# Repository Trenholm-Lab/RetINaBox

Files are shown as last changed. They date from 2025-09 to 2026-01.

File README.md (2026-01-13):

# RetINaBox 

Welcome to RetINaBox, an interactive learning tool for experimental neuroscience. If you haven't read the paper yet, check it out at https://www.eneuro.org/content/13/1/ENEURO.0349-25.2025.

To get started, you'll want to build yourself a RetINaBox, install the software on a Raspberry Pi, and connect your RetINaBox to the Raspberry Pi. Everything you need to get going can be found here, from the 3D printing files, to the components list, to the software, to the user manual. Once you're all up and running, check out the lesson plans!

Enjoy, and best of luck!

cover art copy

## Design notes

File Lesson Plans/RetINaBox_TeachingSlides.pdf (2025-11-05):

# RetINaBox

# Lesson Plans

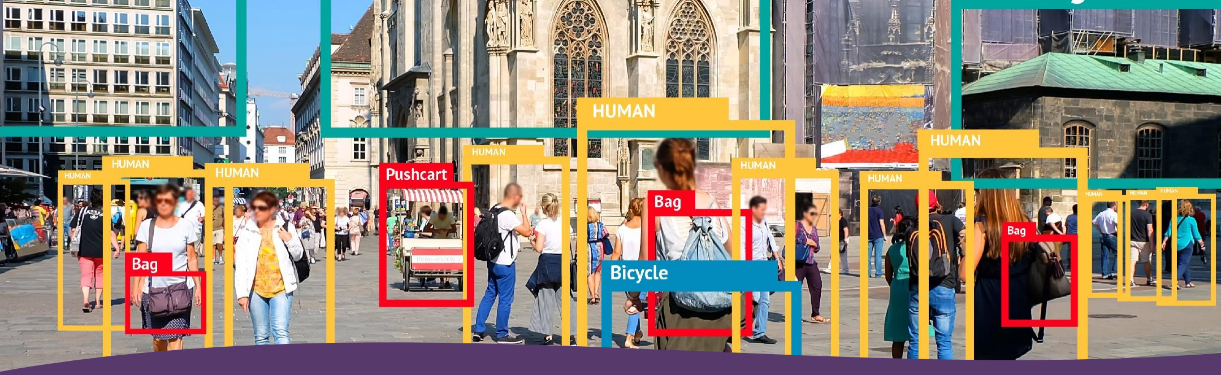
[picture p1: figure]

# The visual world is made up of things in places

Our brain has developed ways of knowing what it’s looking at and where things are

## The brain breaks down the visual world with feature detectors

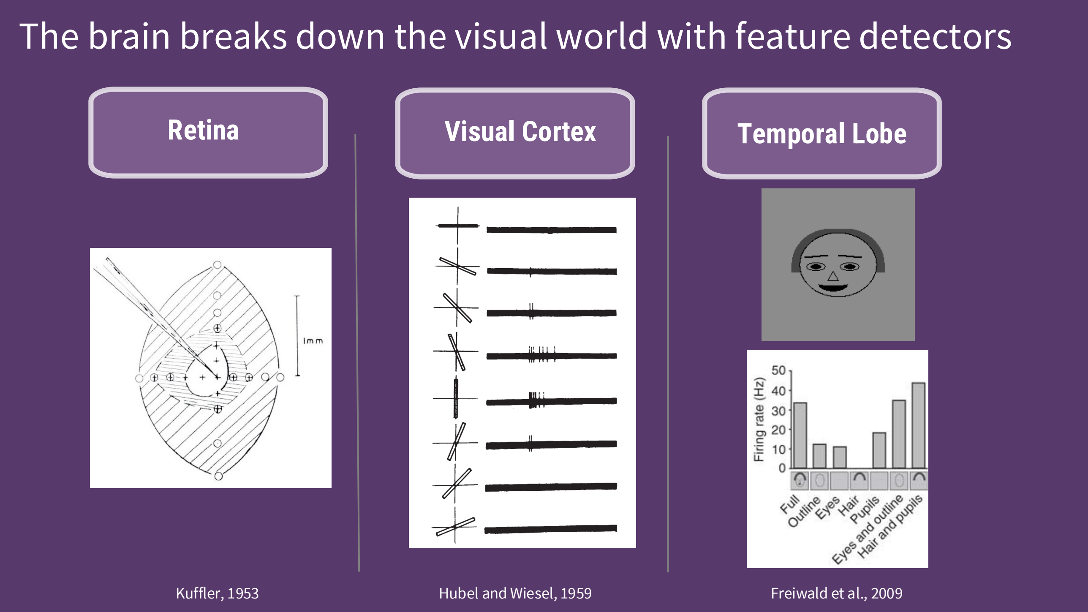
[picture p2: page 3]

Kuffler, 1953 | Hubel and Wiesel, 1959 | Freiwald et al., 2009
Retina | Visual Cortex | Temporal Lobe

# Seeing starts in the eye

# The retina

## Photoreceptors are arranged in a

dense, 3D mosaic in the retina.

# RetINaBox is a simplified model of the visual system

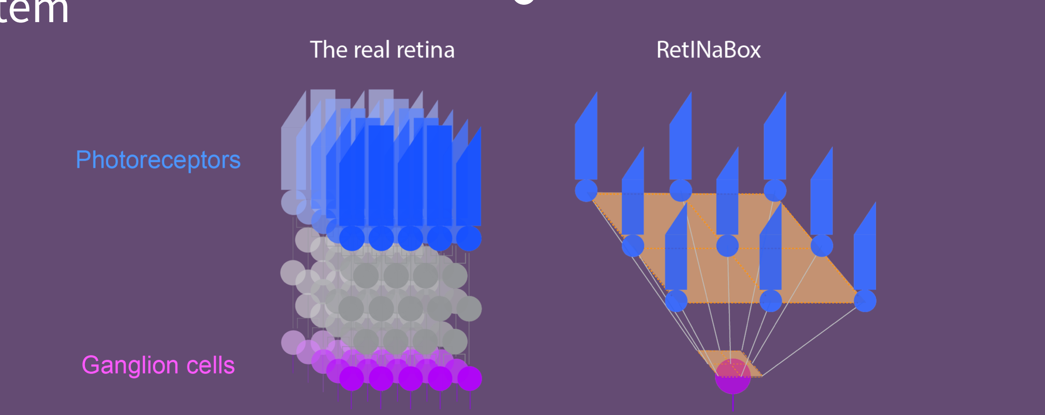
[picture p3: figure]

*Note that while in RetINaBox, photoreceptors directly connect to RGCs, this does not happen in the real retina. In RetINaBox, the contribution from other retinal neurons (such as horizontal cells, bipolar cells and amacrine cells) to RGC responses are included in sign, delay and ON/OFF transfer functions.

# Today we’ll use RetINaBox to explore how the brain generates visual feature detectors

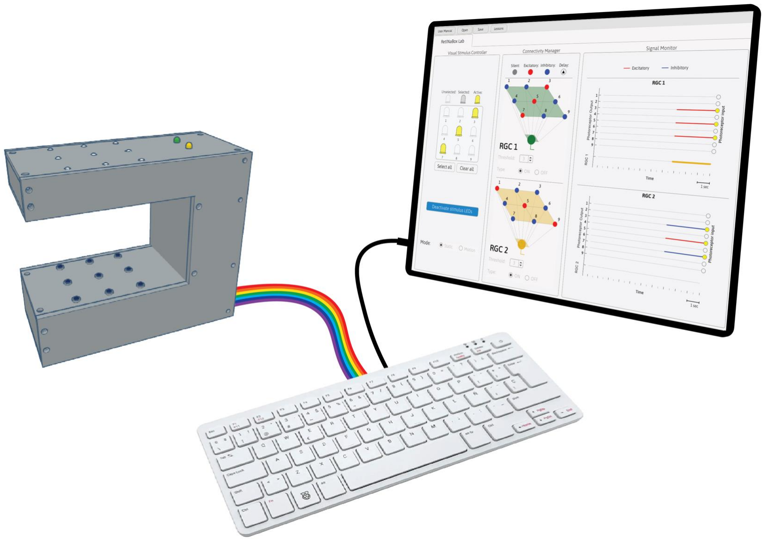
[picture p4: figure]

# RetINaBox

# RetINaBox

Each ganglion cell
responds when it
receives positive inputs
from a sufficient number
of photoreceptors.

Each photoreceptor can
connect to either or both
ganglion cells.

# RetINaBox

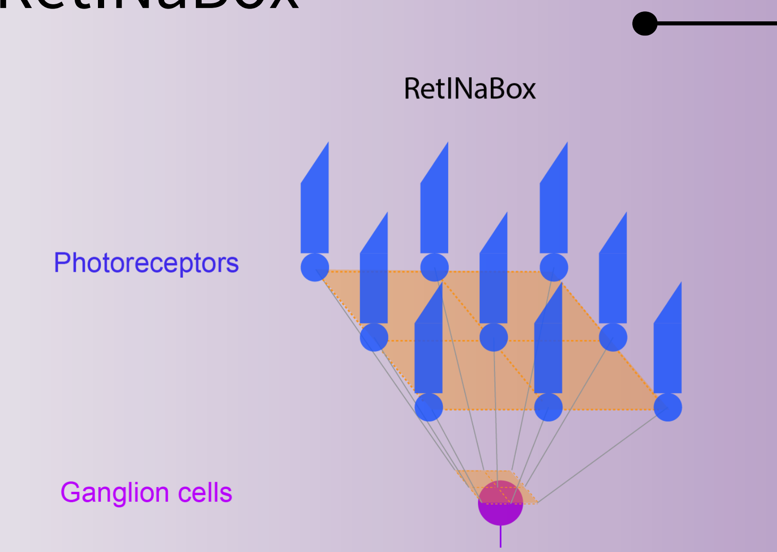
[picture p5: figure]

For each photoreceptor,
you get to set:
- Polarity (+/-)
- Time delay

For each ganglion cell,
you get to decide:
- Threshold
- Type: ON or OFF

# RetINaBox Graphical User Inerface (GUI)

# Visual Stimulus Controller

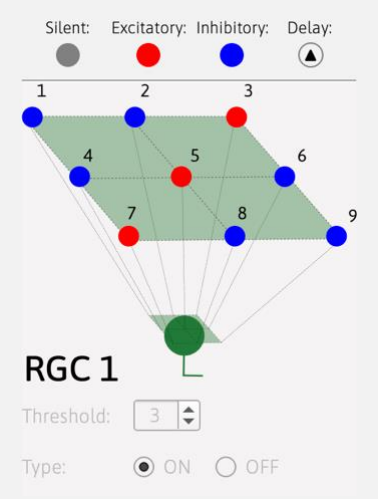
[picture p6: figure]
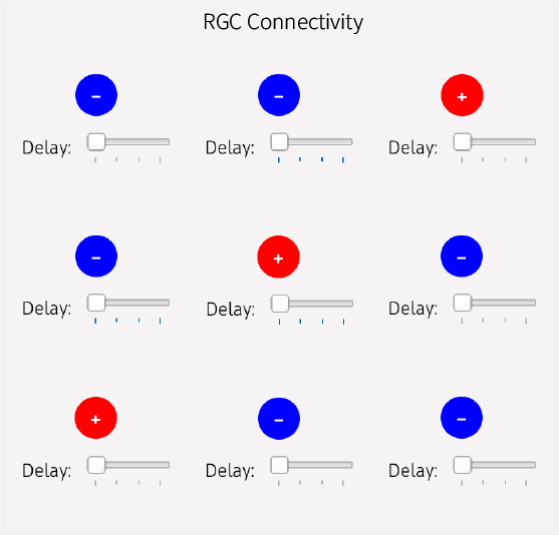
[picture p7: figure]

# Connectivity Manager

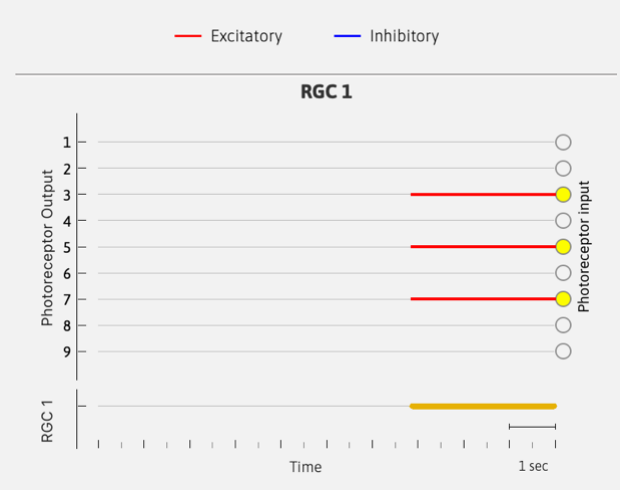
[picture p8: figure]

# Signal Monitor

# Objectives

## Build

Build simple circuits
that mimics retinal
ganglion cell with
different visual
preferences

## Test

Test your circuit by
activating different
LEDs to check the
ganglion cell’s
selectivity

## Real-world stimulation

Use the Visual Stimulus
Tool or shapes cut out of
paper/cardboard to see
how robust your circuit
is

# Testing your circuits

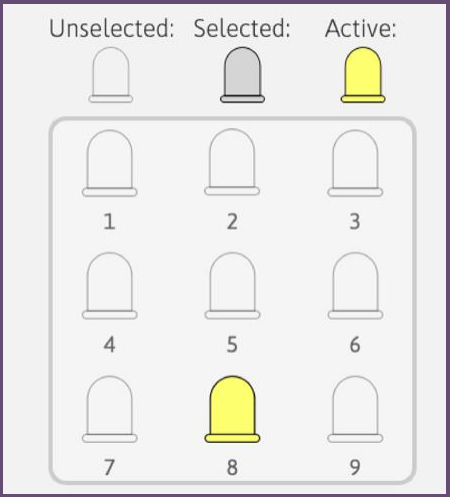
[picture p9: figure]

## LED activation

### Manually activate different combinations of LEDs in the Visual Stimulus Controller to stimulate photoreceptors

# Testing your circuits

## Manual stimulation

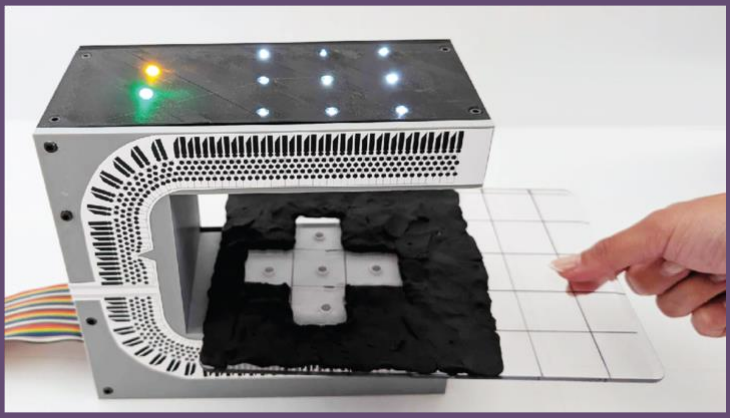
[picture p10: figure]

### Turn on the entire LED array

### Use the Visual Stimulus Tool (modeling clay on a clear board) or shapes cut out of paper/cardboard (stencils provided in the User Manual) to selectively block light from certain photoreceptors

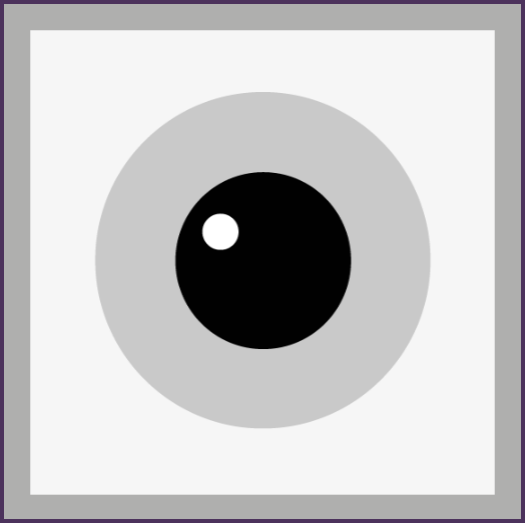
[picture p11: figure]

# Lesson 1

# ON/OFF and Center-Surround

### How do neurons in your visual system know what to respond to in the visual world?

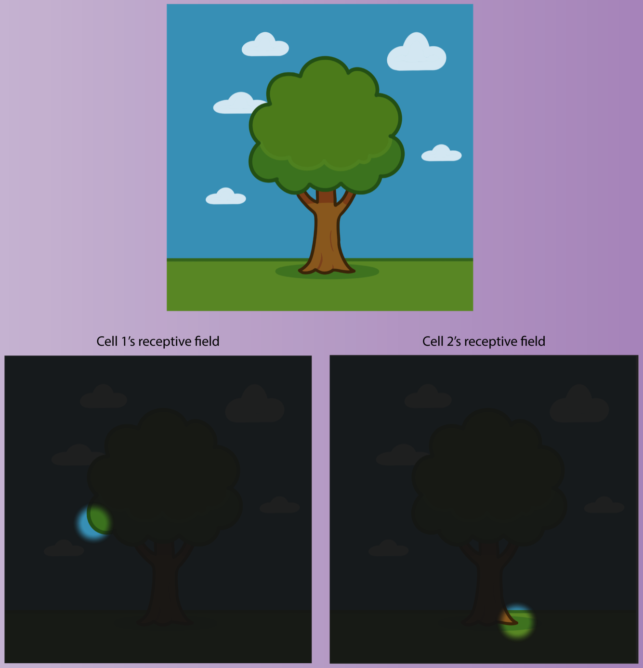
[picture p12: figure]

## Each visual neuron has a receptive field: a specific location in the visual field that it

can see.

# ON and OFF neurons

### Within their receptive fields, some neurons prefer bright stimuli (increases in luminance), while some prefer dark stimuli (decreases in luminance)

An ON neuron responds when the luminance increases within its receptive field.

An OFF neuron responds when the luminance decreases within its receptive field

# ON / OFF responses in the real retina

### Photoreceptors are hyperpolarized by light - they release less glutamate in the light

# ON / OFF responses arise in bipolar retinal neurons

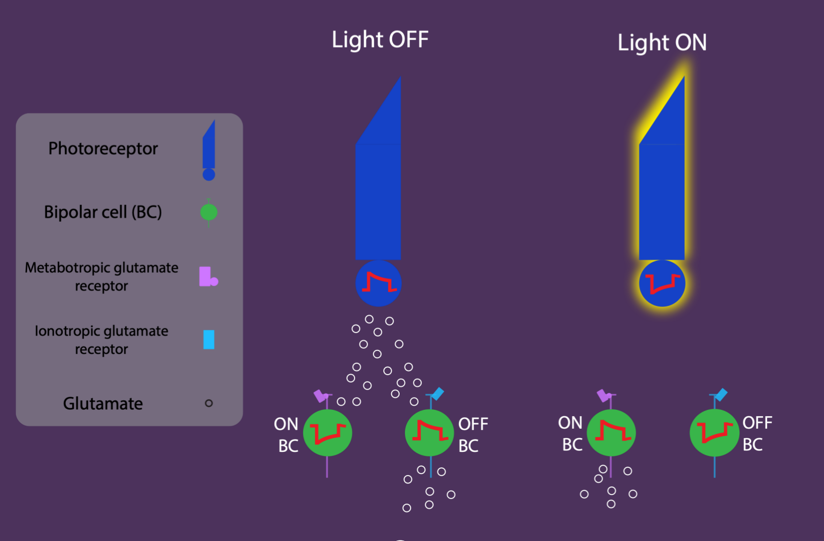
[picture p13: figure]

OFF BCs have
ionotropic
glutamate receptors.
They are sign-conserving
; when PRs
hyperpolarize, OFF
BCs hyperpolarize,
and vice versa.

ON BCs have
metabotropic
glutamate
receptors. They
are sign-inverting;
when PRs
hyperpolarize, ON
BCs depolarize,
and vice versa.

# Center-surround receptive fields

Neurons with center-surround

tuning respond when, within the small part of the visual scene that they see, one part of their receptive field is bright and another parts is dark.

# Center-surround receptive fields make

# neurons sensitive to luminance contrast

Light in the excitatory center drives the neuron

Light in the inhibitory surround reduces the neuron’s response

# The size of the center-surround receptive field controls the spatial frequency of luminance contrast that activates a neuron

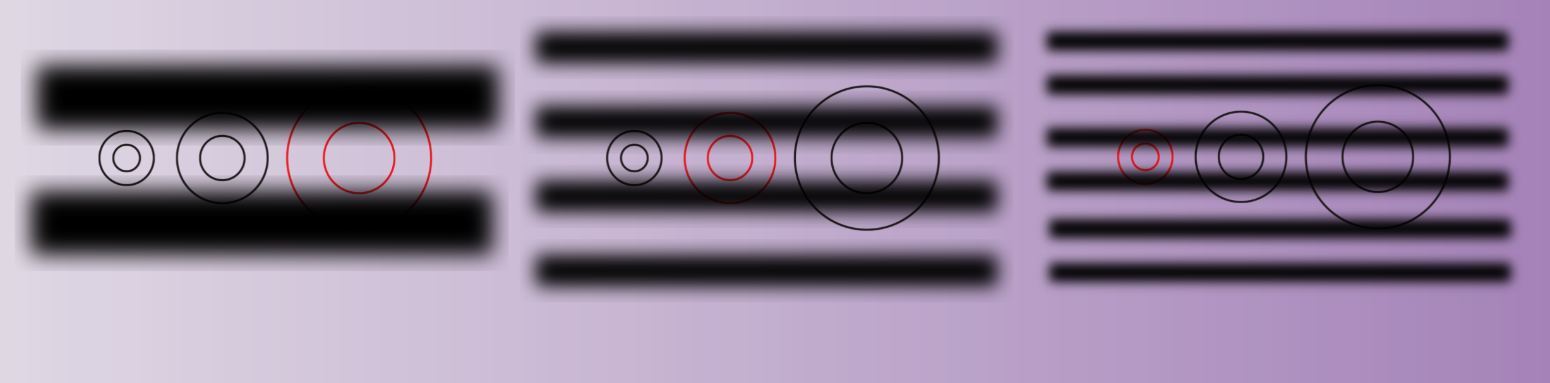
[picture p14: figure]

Visual neurons do not respond well to homogeneous scenes (e.g. a solid white wall)

# Center-surround tuning in the real retina

### Horizontal cells provide negative feedback to photoreceptors

# Center-surround tuning in the real retina

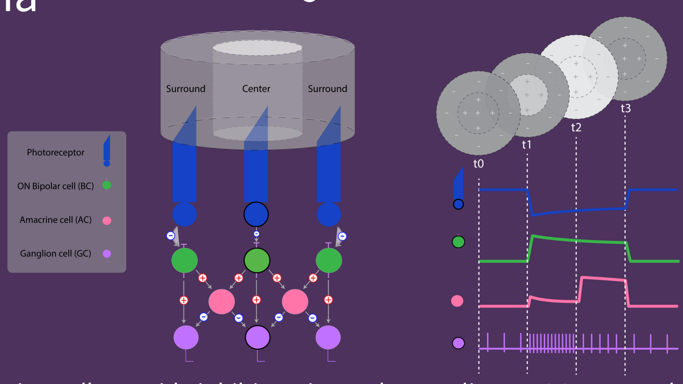
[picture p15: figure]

### Amacrine cells provide inhibitory input that mediates RGC surround responses

# Activity 1

### Build a spot detector with an ON-center/OFF-surround receptive field (activated by light in the center of the receptive field but inhibited by light in the surrounding area)

Use the GUI to build a circuit (RGC1) with an ON-center/OFF-surround ganglion cell that responds only when the center model photoreceptor of the 3x3 array is activated by light, but not when any of the surrounding model photoreceptors are also activated, and not when a small spot is located above any other model photoreceptor.

# Activity 2

### Build a second spot detector with a different receptive field location

Build an ON-ganglion cell (RGC2) with the same size preference (as in Activity #1), but whose receptive field is in a different position on the
photoreceptor array.

By moving the Visual Stimulus Tool, or a piece of paper/cardboard with a small circle cut out, you should now be able to activate each RGC, but only one at a time, based on stimulus position.

# Activity 3

### Build a second spot detector with the opposite polarity

Re-wire RGC2 such that it detects a dark spot instead of a light spot (i.e., make it an OFF cell). This cell should have the same receptive field center/surround as RGC1 built in Activity #1, but with the opposite polarity. RGC2 should be activated by light in the surround and an absence of light in the very center of its receptive field (i.e., it should be activated by a small dark spot in the

center of the photoreceptor array).

# Activity 4

### Build two spot detectors with preferences for spots of different sizes

Generate two different ON-ganglion cells (RGC1 and RGC2) with the same receptive field location (center) but tuned to spots of light of different sizes.

One ganglion cell should detect a small spot of light, while the other should detect a slightly larger spot of light.

If you make two spots of different sizes with your Visual Stimulus Tool or paper/cardboard with circles cut out, you should only be able to activate RGC1 with the small spot, and only activate RGC2 with the larger spot.

# Challenge

### Codebreaking with center-surround receptive fields

You will be given a series of visual stimuli; each represented as a 3×3 grid of photoreceptors. Some photoreceptors are activated (yellow), while others are not activated (black). Each stimulus corresponds to one letter of the secret message.

You will also be provided with a cipher, which will help you decode the message. The cipher will tell you the visual feature preferences for RetINaBox’s two ganglion cells, RGC1 and RGC2. The cypher will also provide you with a way to decode the activity of RetINaBox ganglion cell activity into four letters (0 means a ganglion cell is inactive; 1 means a ganglion cell is active).

Make sure that it is possible for both ganglion cells to be activated simultaneously by a single visual stimulus!

## Codebreaking with center surround receptive fields

Example

To begin the challenge:
Lessons > Lesson 1 > Code
Breaker

# Lesson 2

# Orientation Selectivity

### How do neurons in the visual system allow us to recognize things in the world?

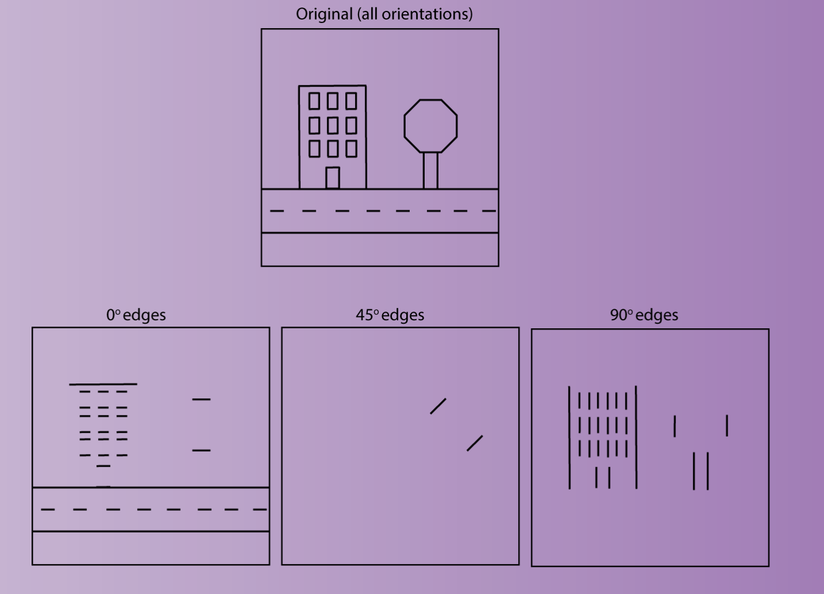
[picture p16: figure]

## Most things in the visual world can be decomposed into a combination of lines of different orientations

## Our visual system has evolved neurons that respond to lines oriented at specific angles - it decomposes the visual world into its fundamental building blocks: oriented

lines of varying orientation.

# Orientation tuning in the brain

### Several spatially-offset lateral geniculate neurons with center-surround receptive fields provide

input to a single V1 neuron.

# Orientation tuning in the brain

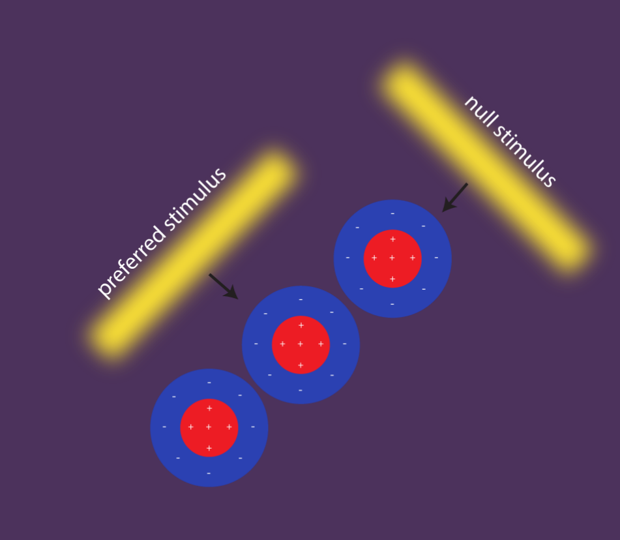
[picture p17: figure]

### The aligned inputs cause the V1 neuron to respond selectively to an elongated bar of light oriented

along the same axis.

# Activity 1

### Build an ON-ganglion cell that detects a vertical line

Configure a circuit for RGC1 such that it only responds to a thin vertical line of light located in a specific part of the photoreceptor array.

The ganglion cell should not respond to a spot of light. The ganglion cell should not respond to a line of the same length of any other orientation/thickness or centered in a different part of the photoreceptor array

# Activity 2

### Build an OFF-ganglion cell that detects a vertical line

Configure a circuit for RGC2 such that it has the same receptive field as RGC1 in Activity #1 (i.e., responds to a thin vertical line).

However, rather than responding to a bright vertical bar, this ganglion cell should respond to a dark vertical bar—an absence of light in the same region—and should be inhibited by light in this area.

# Activity 3

### Build a second ON ganglion cell that detects a diagonal line

Build a circuit for RGC2 that responds to a line of the same thickness as Activity #1 but only responds when the line is diagonal to the first ganglion cell’s preferred stimulus.

This second ganglion cell should not respond to a line of any other orientation or thickness, or to a line of the same orientation centered on a different part of the photoreceptor array.

# Activity 4

### Build two ON ganglion cells that detect vertical lines of different thicknesses

Configure RGC1 and RGC2 such that both cells respond to vertical lines of light, but with one selectively responding to a thin line and the other selectively responding to a thick.

# Activity 5

### Build two ON ganglion cells that detect vertical lines with different lengths

Configure RGC1 and RGC2 such that both cells respond to vertical lines of light with the same approximate spatial location, but with different lengths.

This activity emphasizes the concept of end-stopping, in which an orientation selective neuron responds only to an oriented line of a specific length.

# Challenge

### Build a shape detector with orientation selective receptive fields

Combine the outputs of two orientation selective ganglion cells to detect a specific shape (i.e., an X, +, T, or L): the shape arising from the combination of the lines that activate ganglion cell 1 and ganglion cell 2.

Build a buzzer that sounds only when the target shape is present (i.e., when both ganglion cells are activated).

## Build a shape detector with orientation selective receptive fields

Building the buzzer circuit

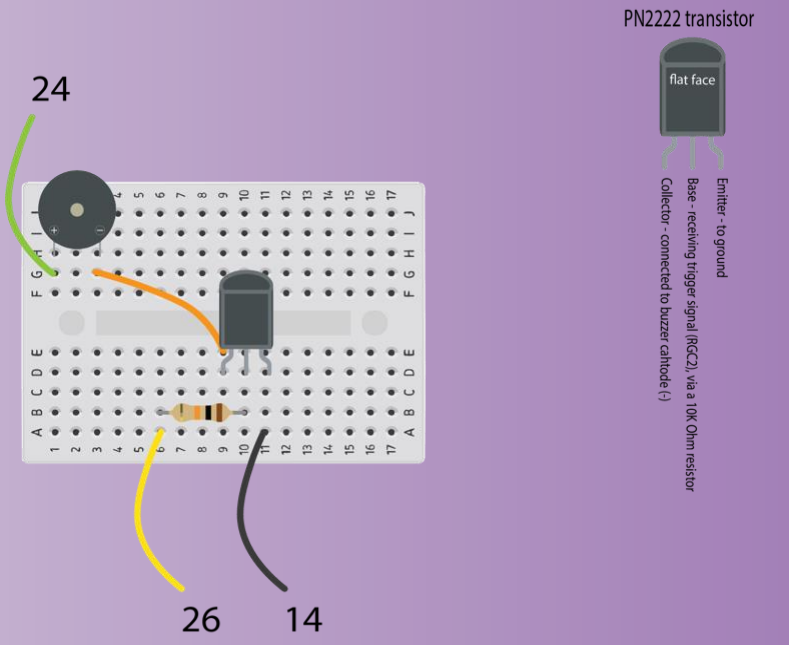
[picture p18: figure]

Once you’ve built the buzzer circuit (please consult the RetINaBox manual on page 9), connect the outputs of the two ganglion cells (the 3.3V digital out pins on the back of RetINaBox) and one of the grounds, to the buzzer circuit.

The buzzer should only sound when you present your target shape.

# Lesson 3

# Direction Selectivity

### How do neurons in the visual system detect motion?

Visual neurons with direction selective receptive fields help our brain know if something is approaching, moving away, or moving tangentially to us.

This ability is vital for survival—it helps animals track prey, avoid predators, and navigate through the world.

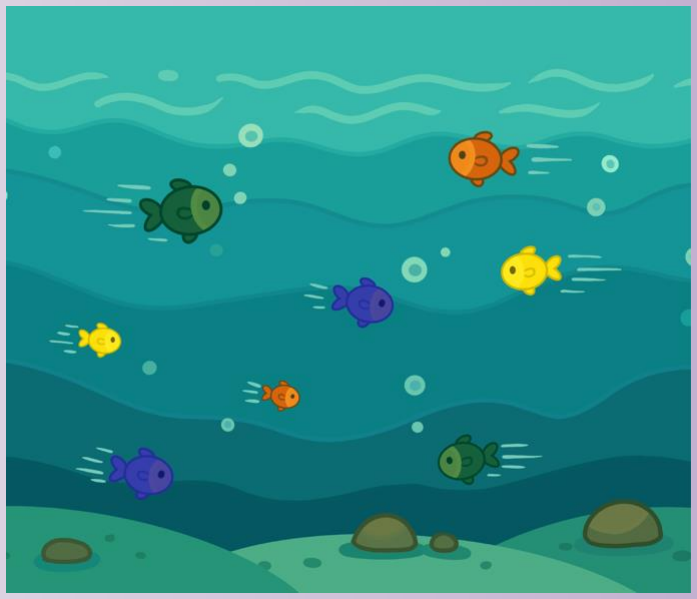
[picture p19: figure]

This can also help us differentiate movement in the visual world that we generate (by moving our
bodies/heads/eyes) from motion that is external to us (like a bird flying in the sky)

As something moves across your visual field, different photoreceptors with spatially offset receptive fields are activated in sequence.

Photoreceptors at the leading edge of the motion respond first, followed by those in the middle, and finally the trailing edge.

# Direction selective tuning in the real retina

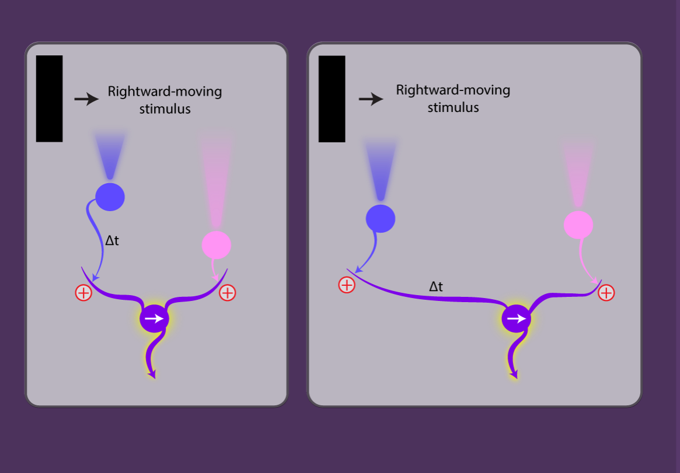
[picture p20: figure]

The brain leverages a time delay between two excitatory inputs to generate directionally selective responses of a neuron that maximally responds to rightward motion.

This delay can occur if the presynaptic neuron’s signal takes longer to travel to the postsynaptic neuron, or if it travels more slowly through the postsynaptic neuron’s dendrites before reaching the cell body.

# Direction selective tuning in the real retina

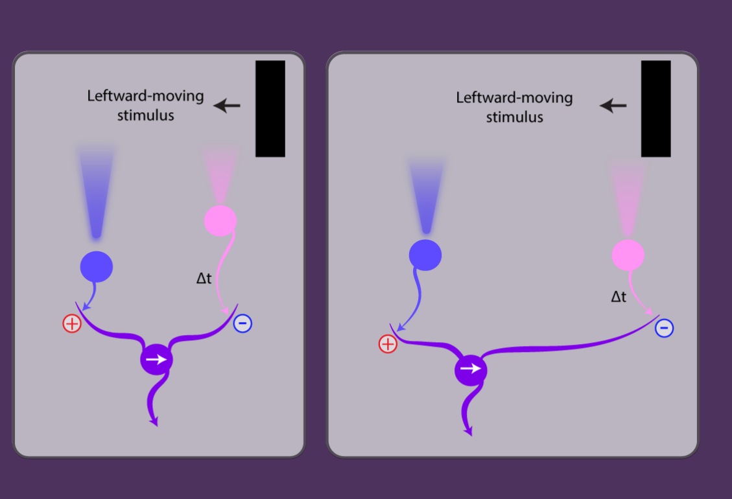
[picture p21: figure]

### In addition to utilizing delays in excitatory circuits, delays with an inhibitory circuit element can enhance direction selective processing

# Activity 1

### Build a left-preferring direction-selective ganglion cell

Build a circuit where RGC1 responds to a vertical line of light moving leftwards.

Test your circuit by moving your hand across your array in both left and right directions.

Begin with a short temporal delay for your first motion-selective circuit. Afterwards, experiment with longer delays tune cells to different speeds of motion.

# Activity 2

### Build a right-preferring direction-selective ganglion cell

Build a second circuit where RGC2 responds to a vertical line of light moving rightwards.

Test your circuit by moving your hand across your array in both right and left directions.

# Activity 3

### Build a slow/fast-moving right direction-selective ganglion cell

Build a circuit where one ganglion cell responds to a vertical line of light slowly moving rightwards, while the second ganglion cell responds to a vertical line moving in the same direction, but more quickly.

Test your circuit by moving your hand rightwards across your array at various speeds.

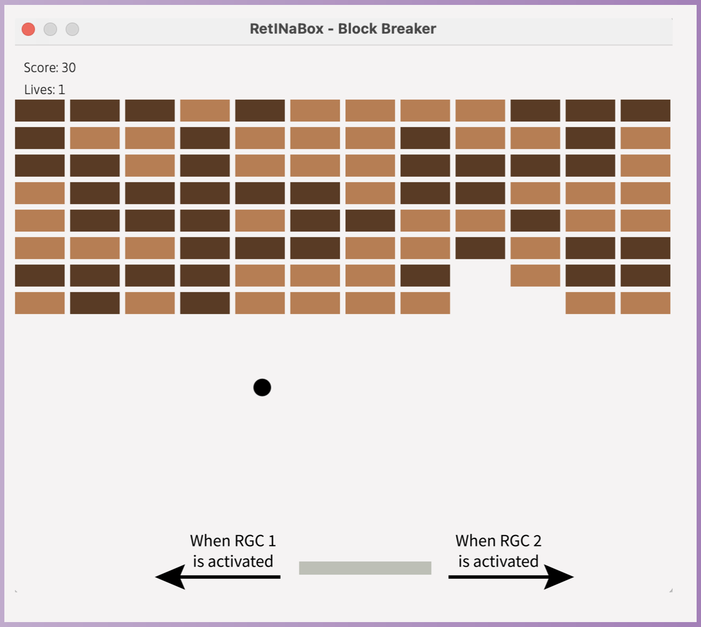
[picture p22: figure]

# Challenge

Players move a paddle to bounce a ball to break several rows of bricks. The goal is to clear all the bricks without letting the ball drop.

Your task is to configure two ganglion cells with opposite direction selectivity and use them as the input controls for the game inside the RetINaBox GUI.

### Block Breaker

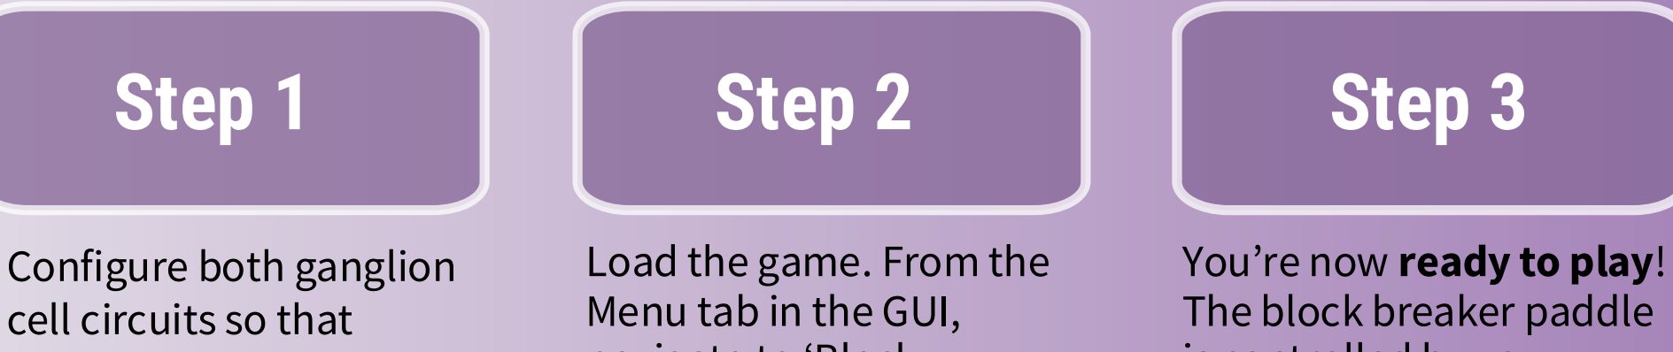
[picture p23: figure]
Load the game. From the Menu tab in the GUI,; You’re now ready to play! The block breaker paddle; Configure both ganglion cell circuits so that; Step 1; Step 2; Step 3

navigate to ‘Block
Breaker’ (Lessons >
Lesson 3 > Block
Breaker).

is controlled by you
sweeping a visual stimulus (your hand) leftward and
rightward across
RetINaBox’s field of view.

RGC1 is selective only
for leftward motion
and RGC2 is selective
only for rightward
motion.

# Block Breaker

# Lesson 4

# Discovery Mode

### It’s your turn discover which visual stimuli best activate visual neurons and discover what circuit connectivity properties underlie such feature

selectivity.

Your goal is to complete each challenge with the highest score possible.

From the Menu tab, navigate to ‘Discovery Mode’ (Lessons > Lesson 4 > Discovery Mode). Then, select a mystery circuit from the drop-down menu.

In Discovery Mode, there are three levels of difficulty (Easy, Medium, Hard), each with their own set of challenges.

For each challenge, you’ll start with 100 points. Incorrect answers cost you 5 points.

## Phase 1: Discover the Preferred Stimulus

Figure out how the ganglion cell obtains this selectivity?

How are the photoreceptors connected to the ganglion cell? What kinds of delays, polarities, or spatial arrangements of the photoreceptors give rise to this selectivity?

Figure out what each ganglion cell responds to (i.e., a specific shape, or a direction of motion, etc.).

Use your Visual Stimulus Tool or
paper/cardboard | with | different
shapes out to test different stimuli to figure out what the ganglion cell is tuned to.

## Phase 2: Discovery the Circuit Connectivity

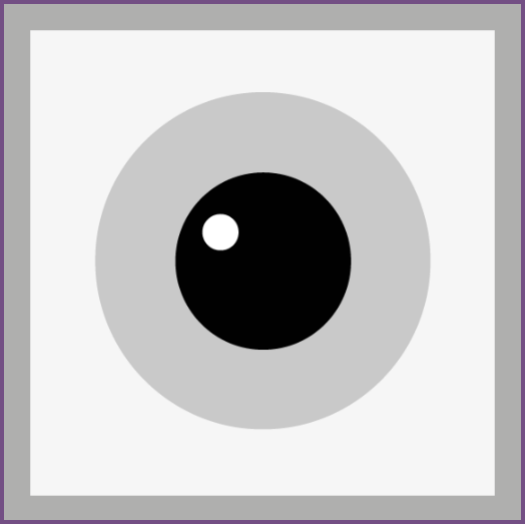
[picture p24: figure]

# Thank You!

Developed by the Trenholm Lab at McGill University

Solutions and additional details are provided in the Lesson Plan. Instructions for setting up hardware and software are available in the RetINaBox User Manual: http://www.trenholmlab.com/retinabox.html

Access code and materials: https://github.com/Trenholm (https://github.com/Trenholm-Lab/RetINaBox)-Lab/RetINaBox (https://github.com/Trenholm-Lab/RetINaBox)

For a more detailed overview of the retina and the visual system, visit theopenbrain.org and https://www.webvision.pitt.edu/

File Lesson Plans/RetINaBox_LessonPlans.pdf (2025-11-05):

# Lesson Plans

Version 1.1

## Overview of the visual system: How do we see?

Visual processing starts in the retina, a thin sheet of light-sensitive brain tissue at the back of your eye (yes, the retina is part of your brain).

Inside the retina, neurons called photoreceptors detect light and turn it into electrical-chemical signals. Through a process called phototransduction, light intensity changes alter the photoreceptor’s membrane potential—that is, the voltage, or difference in electric potential, between the cell’s inside and outside. This change in membrane potential affects how much of the neurotransmitter glutamate the photoreceptor releases. Many neurons ‘talk’ to each other by releasing glutamate, which can be detected by neighbouring neurons.

These photoreceptor-mediated signals are transmitted by helper neurons called bipolar cells onto ganglion cells. The signals passing from photoreceptoràbipolar cellàganglion cell are modulated by horizontal cells and amacrine cells (Figure 1). The result is that retinal ganglion cells respond only when specific visual features are present in the world. For instance, one ganglion might only respond when a spot of light of a particular size appears, and another ganglion cell might only respond when a visual stimulus moves from left to right across the visual field. Finally, ganglion cells pass visual signals out of the eye and to the rest of the brain via the optic nerve (Figure 1).

Figure 1. The eye and retina. Light enters the eye, passing through the cornea, the pupil, the aqueous humor, the lens, and the vitreous humor before falling on the retina. In the retina, light is detected by photoreceptors, which send signals on to ganglion cells, via a network of other retinal cells. Ganglion cells in turn pass visual signals onto higher visual areas in the brain.

However, retinal anatomy is a bit more complex than outlined above. Photoreceptors (and all the other cell types pictured above) are arranged in a dense, 3D arrangement (Figure 2). Within a given retinal layer, cells form a 2D mosaic (Figure 2). For example, in the photoreceptor layer, each individual photoreceptor captures changes in luminance from a tiny portion of the visual scene, but together all the photoreceptors encode the complete image that represents your visual field.


Figure 2. Diagram of the retina illustrating the mosaic-like arrangement of cells in the retina.

*For a more detailed overview of the retina, visit theopenbrain.org and https://webvision.med.utah.edu/.

## RetINaBox: a simplified model of the early visual system

As you’ve seen, the real retina is a complex tissue, with many cell types intricately connected to form myriad circuits. In contrast to the complex real retina, RetINaBox is a simplified model of the retina (Figure 3) that preserves the key principles of visual processing but provides a hands-on tool that you can use to wire, tweak, and test out visual computations. In other words, it was designed to let you discover how feature selective responses arise in the visual system. RetINaBox contains a 3 x 3 array of model photoreceptors, which directly connect to two model retinal ganglion cells. *Note that real photoreceptors do not directly synapse with ganglion cells.

Figure 3. RetINaBox – a simplified model system for studying feature selective responses in the visual system. Left, In the real retina, light is detected by photoreceptors, and these signals eventually make their way to ganglion cells. Right, For RetINaBox, we modeled the photoreceptor mosaic with a 3 x 3 array of model photoreceptors (photodiodes) and connect these directly to a model ganglion cell. The contributions from other retinal neurons are modeled as positive (+) / negative (-), delay, and ON/OFF functions that can be applied to the signal transfer from each photoreceptor to the ganglion cell.

RetINaBox has a few key components (Figure 4):

- A 3 x 3 array of light-sensitive photodiodes, that act as model photoreceptors, that detect changes in infrared light (from RetINaBox’s visual stimulus IR LEDs) and convert these visual signals into electrical signals that they then send to 2 model retinal ganglion cells.
- Two model retinal ganglion cells (RGCs) that integrate signals from the model photoreceptors.

Figure 4. Annotated diagram of RetINaBox (front view (left), rear view (right)).

Each ganglion cell responds when it receives positive inputs from a sufficient number of photoreceptors, based on a user-defined threshold. To model the contribution from other retinal neurons (e.g. horizontal cells, bipolar cells and amacrine cells), users can modify the nature of the signal transferred from each photoreceptor to each ganglion cell. Each photoreceptor can connect to either or both ganglion cells. You get to decide:

- Polarity: whether each photoreceptor activates (excitatory, +1) or silences (inhibitory, -1) the ganglion cell to which it is connected, or whether it remains silent.
- Time delay: how long the photoreceptor signal takes reach the ganglion cell (this can be used to model asymmetric circuit connectivity that can be helpful for implementing motion processing).
- Threshold: the number of positive photoreceptor inputs that a ganglion cell needs to receive to respond. If the combined input from all the connected photoreceptors does not sum past the assigned threshold, the ganglion cell does not respond.
- Type: whether the RGCs are ON or OFF type cells; ON RGCs receive inputs from photoreceptors (photodiodes) that are activated by light; OFF RGCs receive inputs from photoreceptors that are not activated by light.

To help you perform experiments with RetINaBox, we have designed an easy-to-use Graphical User Interface (GUI)! It has three components (Figure 5):

(1) Visual Stimulus Controller (see Figure 5, left panel; Figure. 6): controls the activation of a 3 x 3 LED array, which allows precise control of which model photoreceptors get activated. You decide which LEDs are activated and sending light to their respective photoreceptors (‘activated’ LEDs; LED activation arises once you select an LED and then turn the Visual Stimulus Controller on). LEDs can be activated in either ‘Static’ mode (stationary stimuli) or ‘Motion’ mode (stimuli moving left or right at slow, medium, or fast speeds). Use the ‘Activate Stimulus LEDs’ button to toggle LED activation.
(2) Connectivity Manager (see Figure 5, middle panel): allows users to connect each model photoreceptor to one (or both) ganglion cell(s), specifying the signal polarity (silent, excitatory (+), or inhibitory (-)) and delay (none, short, medium, or long). Users also get to set a threshold for the ganglion cell, and its type (either ON or OFF).
(3) Signal Monitor (see Figure 5, right panel): displays the input to and output from each photoreceptor, and the output of each ganglion cell (ganglion cell activation is also displayed via the green and yellow LEDs on the top of RetINaBox).

Figure 5. RetINaBox GUI, which includes the Visual Stimulus Controller (left), Connectivity Manager (middle), and Signal Monitor (right).

This setup is sufficient to build model ganglion cells with ON/OFF, center-surround, orientation selective, and direction selective receptive fields—just like in the real retina!

*Please refer to the User Manual if you need further assistance with the software.

## How to test your circuits

Each lesson (outlined below) includes hands-on activities that challenge you to build retinal circuits responsive to different types of visual stimuli. For every circuit you build, you'll have two ways to test its visual selectivity:

(1) LED activation (see Figure 6): manually activate different combinations of LEDs in the Visual Stimulus Controller to stimulate the model photoreceptors with different patterns of light. This is a quick way to check that your circuit behaves as expected (i.e. that your ganglion cells respond selectively to specific visual stimuli). Use the ‘Activate Stimulus LEDs’ / ‘Deactivate Stimulus LEDs’ button to toggle LED activation.


Figure 6. Visual Stimulus Controller interface for selecting and activating LEDs in the 3 x 3 array to generate custom patterns of light stimulation.

(2) Manual visual stimulation (see Figure 7): activate the entire LED array. Then, create patterns with your Visual Stimulus Tool—modeling clay on a clear plastic board. Pass this board between the LED and photoreceptor arrays to selectively block light from reaching certain photoreceptors. This is an effective way to test that your visual circuit responds selectively to specific static visual inputs. Alternatively, if you’re dextrous, you can just use your hands. Or, if you refer to the user manual, you can cut out some shapes with pieces of paper/cardboard and use these to control the pattern of light that falls on RetINaBox’s photoreceptor array. For moving stimuli, we recommend simply sweeping your hand leftward and rightward across RetINaBox’s LED array.

Figure 7. Placing the Visual Stimulus Tool between the LED array and model photoreceptors selectively blocks light and delivers precise visual patterns to RetINaBox’s photoreceptor array.

## Lesson 1: ON/OFF and Center-Surround

The visual world is made up of things in places—different shapes, colours, and patterns located in specific regions of space (Figure 8). And it turns out that your visual system has evolved to be particularly sensitive to things that are distinct from large homogeneous backgrounds.

Figure 8. Your visual system is optimized for parsing things out of visual scenes that differ from the background.

Receptive fields
A simple way your visual system breaks down the visual world is by endowing each visual neuron with a receptive field. This means that each neuron can only see within a specific region of your visual field (Figure 9). You can think of a receptive field like a spotlight: each neuron’s “spotlight” allows it to only see things in a specific part of the world. Since receptive fields from many different neurons tile your visual field of view, the collection of responses from neurons with different receptive field positions helps your brain figure out where things are in the world.

However, when a neuron is activated, it doesn’t just mean that something is in its receptive field. Most neurons also have a preference for what they want to see. In other words, each neuron only responds (or at least only maximally responds) when the specific thing it wants to see happens to fall within its receptive field. Throughout these lesson plans, we’re going to spend a lot of time discussing how individual neurons acquire preferences for different types of visual features. However, for the time being, imagine 4 visual neurons. Neurons 1 and 2 have overlapping receptive fields and only see within location A. Neurons 3 and 4 have overlapping receptive fields and only see within location B. Neurons 1 and 3 only respond when apples are in their receptive fields, and Neurons 2 and 4 only respond with pears are in their receptive fields. Figure 9 outlines this diagrammatically, indicating that a neuron responds only when the thing it wants to see falls within its receptive field.


Figure 9. Different neurons have different receptive fields and therefore only ‘see’ within small portions of your entire visual field of view. Different neurons can also have preferences for different visual features. In this example, Neuron 1 and Neuron 2 have the same receptive field location, but only Neuron 1 is selective to a circular spot of red light, so Neuron 1 is the only cell to respond to the presence of an apple in its receptive field. However, different neurons can also have preferences for the same visual feature, but different receptive field locations. In this example, Neuron 2 and Neuron 4 have a preference for a circular spot of yellow light, but here only Neuron 4 will fire as the pear is only present in Neuron 4’s receptive field. *The yellow bounding boxes indicate that Neurons 1 and 4 are active.

What visual features best activate visual neurons?

ON/OFF: A quick look across a visual scene—for instance the monochromatic scene shown in Figure 10—should make it clear that the luminance (i.e. how light or dark different parts of the visual scene are) often varies significantly from one location to another. And it turns out that your visual system evolved to parse visual scenes in part based on their bright and dim components via ON and OFF receptive fields (Figure 10). An ON visual neuron responds when the luminance increases within its receptive field, whereas an OFF neuron responds when the luminance decreases within its receptive field.

Figure 10. (A) Pablo Picasso’s Guernica (1937) with receptive fields of two example neurons highlighted in red and blue. (B) Histogram of luminance (brightness) values in Guernica, ranging from 0 to 1, showing two peaks corresponding to very bright and very dark pixels in the painting. (C) Normalized luminance values within the receptive fields of Neurons 1 and 2. (D) Response of Neuron 1 (ON cell) and Neuron 2 (OFF cell) in response to a light stimulus. The ON cell depolarizes in response to the light stimulus, while the OFF cell hyperpolarizes in response to the light stimulus, and depolarizes when it turns off.

How do ON vs. OFF responses arise in the visual system? Photoreceptors are the first cells in the visual pathway that respond to light. In darkness, their resting membrane potential is relatively depolarized and they continuously release the neurotransmitter glutamate. When luminance within a photoreceptor’s receptive field increases and the photoreceptor absorbs photons of light, its membrane potential hyperpolarizes, leading to a decrease in glutamate release (Figure 11). In this way, photoreceptors convert light into chemical signals that downstream neurons can interpret.

Figure 11. In darkness, photoreceptors depolarize and release glutamate. When luminance increases, photoreceptors hyperpolarize, and glutamate release decreases.

A decrease in glutamate release from photoreceptors is the signal that indicates to bipolar cells (BCs) that light is present (horizontal cells also sense glutamate release from photoreceptors and provide feedback, but we won’t focus on that point yet). It’s at the level of bipolar cells that the visual system starts sorting responses based on whether the luminance in a cell’s receptive field increased or decreased. This happens because there are two major classes of bipolar cells: ON and OFF. Both respond to glutamate, but they express different types of glutamate receptors in their dendrites, which allows ON and OFF bipolar cell to differentially respond to the same change in photoreceptor glutamate release that occurs when the light levels change.

ON BCs have metabotropic glutamate receptors in their dendrites. In the dark, glutamate released by photoreceptors binds to these receptors, activating a signaling cascade that closes cation channels, preventing Na⁺ ions from entering the cell, causing ON BCs to hyperpolarize (which means they, in turn, stop releasing glutamate from their axons). In the light, photoreceptors stop releasing glutamate. The ON BC’s metabotropic glutamate receptors become unbound, which leads to the opening of cationic channels, which allows Na⁺ ions to enter, which depolarizes the cell. This means that ON bipolar cells depolarize when photoreceptors hyperpolarize (and vice versa), and this is termed as ‘sign-inverting’ (Figure 12).

OFF BCs have ionotropic glutamate receptors in their dendrites. In the dark, glutamate released from photoreceptors binds to these receptors, which directly opens the receptor-associated cationic channel, allowing Na⁺ ions to enter and depolarize the cell. In the light, the photoreceptors stop releasing glutamate. The OFF BC’s ionotropic glutamate receptors no longer bind to glutamate, and the cationic channels close, Na⁺ ions no longer enter the cell, and the cell hyperpolarizes. This means that OFF bipolar cells hyperpolarize when photoreceptors hyperpolarize (and vice versa), and this is termed as ‘sign-conserving’ (Figure 12).


Figure 12. ON and OFF bipolar cells respond differently to light due to their distinct glutamate receptors. OFF BCs have sign-conserving ionotropic glutamate receptors, and ON BCs have sign-inverting metabotropic glutamate receptors. In darkness, photoreceptors release glutamate, depolarizing OFF BCs and hyperpolarizing ON BCs. When light is present, photoreceptor glutamate release decreases, depolarizing ON cells and hyperpolarizing OFF cells.

Condition | Photoreceptor | Glutamate Release | ON BC | OFF BC
Dark | Depolarized | High | Hyperpolarized | Depolarized
Light | Hyperpolarized | Low | Depolarized | Hyperpolarized
Table 1. Summary of photoreceptor and bipolar cell responses to light and dark conditions.

Center-Surround: In nature scenes, some sections (such as walls, or a clear sky) have little change in luminance over a large spatial area. These are regions of low contrast, with high spatial redundancy. Other parts of the visual scene have tightly packed variations in luminance within a small spatial area. These are regions of high contrast. It turns out that your visual system evolved to largely filter out redundant scenes while encoding local luminance contrast. One way your visual system accomplishes this is by having center-surround receptive fields (Figure 13).

ON-center/OFF-surround cells are excited by light in the center of their receptive fields but inhibited by light in the surround. OFF-center/ON-surround cells are excited by darkness in their center but inhibited by darkness in their surround.

With center-surround receptive fields, a cell’s receptive field is split into 2 regions: a central area, that when activated excites the neuron; a surrounding area, immediately flanking the center, that when activated inhibits the neuron. Center-surround receptive fields can come in both ON and OFF types. For an ON-center ganglion cell with a low spontaneous baseline firing rate (Figure 14), putting a small spot of light in the center that underfills the center will result in a slight increase in firing rate. Increasing the size of the spot of light so that it matches the size of the center but doesn’t active the surround will result in the highest firing rate. Further increasing the size of the spot of light will reduce the firing rate, as surround activation will inhibit firing (Figure 14).

Figure 14. Response of an ON-center/OFF-surround cell in response to a spot of light of increasing size.

If we consider a visual scene, the spacing between bright and dim elements varies widely. In other words, in some places, the luminance contrast changes over a very small portion of visual space, whereas in other places the luminance contrast varies over wider portions of visual space. The term we use for the size in the visual field that it takes an element to go from light to dark is referred to as spatial frequency. Natural scenes are composed of many different spatial frequencies, from low to high (Figure 15).

Figure 15. Visual scenes contain a large variety of spatial frequencies and can be decomposed into different spatial frequency bands. Low spatial frequencies capture coarse features, while higher frequencies contain fine details.

This is where center-surround receptive fields come in. As described above, center-surround receptive fields help visual neurons selectively respond to local luminance contrast—that is, differences in light intensity between nearby parts of the visual field. Center-surround receptive fields can vary in size, and cells with smaller receptive fields are optimized for detecting fine details (Figure 16; right panel; high spatial frequencies), while those with larger receptive fields respond best to broader patterns (Figure 16; left panel; low spatial frequencies).

Figure 16. Center-surround receptive fields mean that visual neurons tend to respond maximally when the contrast (bright vs. dark) is properly aligned between center and surround. The size of the center-surround receptive field is responsible for the spatial frequency of the luminance contrast that best activates a cell.
How is center-surround tuning implemented?

Center-surround receptive fields are present to some extent in most retinal neurons. Even photoreceptors have center-surround receptive fields. Photoreceptors connect to bipolar cells, which in turn connect to ganglion cells, which in turn pass visual signals out of the eye to higher visual signals. But photoreceptors also connect to horizontal cells. Horizontal cells are large, laterally projecting neurons. Each horizontal receives inputs from many photoreceptors, and horizontal cells are also laterally connected with other horizontal cells. Regarding center-surround, the important feature is that horizontal cells provide negative feedback to photoreceptors. In other words, when a photoreceptor activates a horizontal cell, the horizontal cell feeds back to the photoreceptor, making the photoreceptor less active. But a single photoreceptor only provides a week input to a horizontal cell, meaning that for a small spot of light that activates a single photoreceptor, the horizontal cell is only weakly activated and provides minimal feedback to the photoreceptor. In contrast, when a visual stimulus is large, it activates many neighbouring photoreceptors, which strongly activate horizontal cells, which now provide strong negative feedback to photoreceptors (Figure 17).


Figure 17. Horizonal cells (HCs) mediate surround responses in photoreceptors. A: HCs provide negative feedback to photoreceptors, which is maximal during large (surround) visual stimulation. B: Light in the center alone (t1) hyperpolarizes only the central photoreceptor, which weakly hyperpolarizes the downstream HCs. Light in the center and surround (t2) hyperpolarizes central and surround photoreceptors, strongly hyperpolarizing downstream HCs, which provide strong negative feedback to the photoreceptors, causing them to slightly depolarize, suppressing the overall photoreceptor light response (compared to center illumination alone).

Exactly how center-surround is implemented varies across different types of retinal neurons. In the retina, center-surround was first described in retinal ganglion cells. However, while (as describe above) even photoreceptors exhibit center-surround receptive fields, it appears that for ganglion cells the most significant portion of their receptive field surround arises from amacrine cells, retinal interneurons that can provide inhibition to bipolar and ganglion cells (as well as other amacrine cells). See Figure 18 for an example of center-surround in retinal ganglion cells.

Figure 18. Amacrine cells (ACs) provide inhibitory input that mediates RGC surround responses. *In this example, we focus specifically on the impact of amacrine cells on ganglion cell surrounds—as such, here we ignore surround responses in photoreceptors, bipolar cells or amacrine cells. A: ACs provide inhibitory input to ganglion cells (GCs) to modulate their response to a surround stimulus. B: Light in the center alone (t1) hyperpolarizes only the center photoreceptor, depolarizing the center ON bipolar cell (BC), which excites both a downstream center ON GC, while also weakly depolarizing some ACs. Weak AC activation has very little effect on the center GC, which fires maximally in response to light in the center. Light in the center+surround (t2) hyperpolarizes center and surround photoreceptors, depolarizing downstream the center and surround ON BCs. The center ON BC provides similar excitation to the center ON RGC in both center and center+surround stimulation conditions, but in the latter condition the surround BCs are also activated, so the amacrine cells are much more strongly activated in the center+surround condition. Strong AC activation has a strong suppressive effect on the center GC, reducing its overall spiking output (compared to center illumination alone).

In summary:

- Each visual neuron responds to light in a specific region of space – its receptive field – helping the brain determine where things are in space.
- Separate ON and OFF pathways in the retina enable the system to detect both increases and decreases in luminance, supporting contrast detection.
- ON-center/OFF-surround and OFF-center/ON-surround receptive fields help neuron encode what is in their receptive field: neurons respond to patterns with specific spatial frequencies (how quickly light and dark patterns change across space), allowing the visual system to capture both fine and coarse details in the visual scene.

Lesson 1 Objective

Build a simple circuit that mimics a center-surround retinal ganglion cell to explore how the visual system detects a localized spot of light. Then, test your circuit by activating different LEDs (in ‘static’ mode) to check the ganglion cell’s selectivity. Finally, test RetINaBox with real-world visual stimuli to see how robust your center-surround circuit is.

Keep in mind that photoreceptors don’t actually connect directly to ganglion cells, despite the simplified model presented in RetINaBox. Ganglion cells receive input from bipolar cells, and modulatory input from amarine cells which RetINaBox models with +/- and ON/OFF connectivity functions between photoreceptors and ganglion cells.

Activity #1: build a spot detector with an ON-center/OFF-surround receptive field Neurons with ON-center/OFF-surround receptive fields are activated by light in the center of their receptive field but inhibited by light in the surrounding area.

Use RetINaBox’s GUI to build a circuit for RGC1 with an ON-center/OFF-surround ganglion cell (also known as an ON cell) that responds only when the center model photoreceptor of the 3 x 3 array is activated by light, but not when any of the surrounding model photoreceptors are also activated, and not when a small spot is located above any other model photoreceptor.

This activity emphasizes that center-surround neurons (in this case, an ON-center/OFF-surround cell) respond selectively to specific spatial locations and spatial frequencies (in this case a small spot of light located in the center of the photoreceptor array).

Activity #2: build a second spot detector with a different receptive field location Your next task is to build an ON-ganglion cell (RGC2) with the same size preference as in Activity #1, but whose receptive field is in a different position on the photoreceptor array. By moving around the small spot visual stimulus, you should be able to independently activate RGC1 and RGC2 based on the stimulus position.

This activity emphasizes that the same photoreceptors can contribute to distinct parts of different downstream neurons’ receptive fields(in this case, the photoreceptor that contributes to one RGC’s center contributes to the other RGC’s surround), and that by tiling the visual field with spatially offset receptive fields the visual system is able to encode the location of a stimulus via population activity.

Activity #3: build a second spot detector with the opposite polarity
Next, re-wire RGC2 such that it detects a dark spot instead of a light spot (i.e., make it an OFF cell). This cell should have the same receptive field center/surround as RGC1 built in Activity #1, but with the opposite polarity, meaning that when light activates the center photoreceptor, it now inhibits the RGC instead of exciting it. More specifically, RGC2 should be activated by light in the surround and an absence of light in the very center of its receptive field (i.e., it should be activated by a small dark spot in the center of the photoreceptor array).

This activity emphasizes that having both ON and OFF responses allows the visual system to detect both increases and decreases in light intensity, helping the brain detect edges and contrast (changes in luminance). It also emphasizes that the same photoreceptors can lead to different receptive field components in ganglion cells that have overlapping receptive fields, dependent on the specific inputs to the ganglion cells.

Activity #4: build two spot detectors with preferences for spots of different sizes Your next task is to generate two different ON ganglion cells (RGC1 and RGC2) with the same receptive field location (center) but tuned to spots of different sizes. One ganglion cell should detect a small spot of light, while the other should detect a larger spot of light. If you make two spots of different sizes, you should only be able to only activate RGC1 with the small spot, and only activate RGC2 with the larger spot.

This activity emphasizes that the size of a neuron’s receptive field determines its spatial frequency preference: small fields detect fine details, while large fields respond to broader patterns.

If you have difficulty with any of these activities, you can load presets in the RetINaBox: Lessons > Lesson 1.

Challenge: Codebreaking with center surround receptive fields
Now that you’ve learned how to make ganglion cells that selectively respond to spots of specific sizes in specific locations, we challenge you to apply what you've learned about center-surround receptive fields to decode a hidden message.

You will be given a series of visual stimuli; each represented as a 3 × 3 grid of photoreceptors. Some photoreceptors are activated (yellow), while others are not activated (black). Each stimulus corresponds to one letter of the secret message.

You will also be provided with a cipher, which will help you decode the message. The cipher will tell you the visual feature preferences for RetINaBox’s two ganglion cells, RGC1 and RGC2. The cipher will also provide you with a way to decode the activity of RetINaBox ganglion cell activity into four letters (0 means a ganglion cell is inactive; 1 means a ganglion cell is active).

Your task:

1. From the Menu tab in the GUI, navigate to ‘Code Breaker’ (Lessons > Lesson 1 > Code Breaker).
2. In the Connectivity Manager, wire RetINaBox so that the two ganglion cells respond to the indicated visual stimuli. One important note: make sure that it is possible for both ganglion cells to be activated simultaneously by a single visual stimulus!
3. Use the Visual Stimulus tool or some shapes cut out with paper to present visual stimuli from the code to RetINaBox and monitor the responses of the ganglion cells.
4. For each visual stimulus, use the cipher to translate the RGC1+RGC2 output into a letter.
5. Repeat for each stimulus and piece together the full secret message.

See the example below (Figure 19):

Figure 19. Example of the code breaking game.

Challenge #1 of the code breaking activity


Figure 20. Challenge 1 for the code breaking game.

*See the Lesson Plan’s Appendix for the solution to this and additional codebreaking challenges.

## Lesson 2: Orientation selectivity

Instead of being a random jumble of patches of different luminance contrast, the visual world contains an abundance of extended lines and edges—extended boundaries along which luminance changes in a consistent manner, such as the outline of a tree or the edge of a building. In fact, most things in the visual world can be decomposed into a combination of lines of different orientations (Figure 21).

Figure 21. Natural visual scenes can be broken down into their fundamental building blocks—lines/edges of varying orientations. Each image in the bottom row shows the same scene, but filtered to reveal edges at 0o

, 45o

, or 90o

Because natural scenes contain so many edges of various orientations, the visual system has evolved neurons that respond to lines oriented at specific angles (Figure 22). In other words, it decomposes the visual world into its fundamental building blocks: oriented lines of varying orientation.

Figure 22. Some neurons in your visual system are tuned to seeing edges or lines of particular orientations in the visual world. These orientation selective cells (right) decompose the world into series of line elements of different orientations and locations.

How are orientation selective receptive fields implemented in the visual system?

Signals from retinal ganglion cells (RGCs) are sent through the optic nerve to the lateral geniculate nucleus (LGN) and then relayed to the primary visual cortex (V1). Early recordings from LGN neurons suggested that, much like RGCs, they tend to have center-surround receptive fields. However, the first recordings from primary visual cortex (V1), which receives it dominant visual input from the LGN, found that instead of center-surround receptive fields, most V1 neurons showed orientation selective receptive fields—they respond to extended edges or bars of light at a particular angle.

Visual scientists David Hubel and Torsten Wiesel proposed that this property arises when a single V1 neuron receives input from several LGN neurons whose center-surround receptive fields are spatially offset but aligned along a particular orientation in visual space (Figure 23 (left)). Together, these inputs form an elongated receptive field that best responds to a bar orientated along the same axis (Figure 23 (right)).


Figure 23. Left, Hubel and Wiesel’s model of orientation selectivity in V1. Several spatially-offset LGN neurons with center-surround receptive fields provide input to a single V1 neuron. The aligned inputs cause the V1 neuron to respond selectively to an elongated bar of light oriented along the same axis. Right, A bar of light aligned with the receptive-field centers of multiple LGN neurons (preferred stimulus) activates all inputs simultaneously, strongly exciting the downstream V1 neuron. In contrast, a bar of light oriented perpendicularly (null stimulus) activates only one center at a time, preventing the LGN inputs from summating and producing no response in the downstream V1 neuron.

In this way, the brain can build complex feature detectors from simple ones—it combines multiple center-surround inputs to create orientation-selective neurons that detect edges, bars, and contours. Higher-order downstream neurons can then combine inputs from various orientation-selective cells to represent various shapes.

While orientation selectivity can also arise in retinal ganglion cells in some species, via different biological implementations than describe above, Hubel and Wiesel’s model remains one of the most influential and widely taught examples of how orientation selectivity emerges in the visual system.

In lesson 2, you’ll explore how ganglion cells in your model retina can become selective to lines of specific orientations and how you can use these feature detectors to build a shape detector. *Remember, photoreceptors don’t connect directly to ganglion cells to generate orientation selective receptive fields, despite the simplified model presented in RetINaBox! Also, if it helps you conceptualy, while we call our tool RetINaBox, here, if you like, you can imagine that the model RGCs are actually model V1 orientation selective neurons.

In summary:
- Our visual system interprets visual scenes by decomposing them into simpler components: lines and edges of different orientations located in different parts of the visual world.
- Cortical V1 neurons integrate inputs from multiple center-surround neurons to become selective for lines of specific orientations, allowing the brain to piece together a rudimentary representation of the visual scene built from shapes and contours.

Lesson 2 Objective

Build and test two retinal ganglion cells to model orientation selectivity and use the combined tuning of these two cells to generate a shape detector. First, test your circuits by activating different combinations of LEDs (in the GUI’s ‘static’mode). Then, perform real-world visual stimulation by making a shape that is the combination of the two orientated lines that stimulate RGC1 and RGC2.

Activity #1: build an ON-ganglion cell that detects a vertical line
Configure a circuit for RGC1 such that it only responds to a thin vertical line of light located in a specific part of the photoreceptor array. The ganglion cell should not respond to a spot of light, nor should it respond to a line of the same length of any other orientation/thickness or centered in a different part of the photoreceptor array.

This activity emphasizes that orientation-selective neurons respond selectively to bars oriented at specific angles located in a specific part of the visual field.
Activity #2: build an OFF-ganglion cell that detects a vertical line
Configure a circuit for RGC2 such that it has the same receptive field as RGC1 in Activity #1 (i.e., responds to a thin vertical line). However, rather than responding to a bright vertical bar, this ganglion cell should respond to a dark vertical bar—an absence of light in the same region—and should be inhibited by light in this area.

This activity emphasizes that ON and OFF pathways work in parallel to encode increases and decreases in luminance. This organization extends to orientation selective receptive fields, allowing the visual system to detect both bright and dark lines of specific orientations.
Activity #3: build a second ON ganglion cell that detects a diagonal line
Re-wire RGC2 such that it responds to a line of light of the same thickness as Activity #1 but only when the line is in a diagonal orientation. This second ganglion cell should not respond to a line

of any other orientation or thickness, nor to a line of the same orientation centered on a different part of the photoreceptor array.

This activity emphasizes that each photoreceptor can contribute to distinct parts of multiple RGC’s receptive fields and that cells with similar receptive field positions can prefer lines of different orientations.
Activity #4: build two ON ganglion cells that detect vertical lines of different thicknesses
Configure RGC1 and RGC2 such that both cells respond to vertical lines of light, but with one selectively responding to a thin line and the other selectively responding to a thick line.

This activity emphasizes that receptive field size determines a neuron’s spatial frequency preference. Cells with smaller receptive fields respond to thin, fine line features, while those with larger receptive fields respond to broader, thicker line patterns.
Activity #5: build two ON ganglion cells that detect vertical lines with different lengths
Configure RGC1 and RGC2 such that both cells respond to vertical lines of light with the same approximate spatial location, but with different lengths.

This activity emphasizes the concept of end-stopping, in which an orientation selective neuron’s response is inhibited when a visual stimulus of the correct orientation extends beyond a preferred length. In other words, many orientation-selective neurons only respond to an oriented line of a specific length. End stopping is thought to help the visual system encode corners, line endings, and regions of high curvature, which are important for detecting boundaries and shapes.

If you have difficulty with any of these activities, you can load presets in the RetINaBox: Lessons > Lesson 2.

Challenge: build a shape detector with orientation selective receptive fields
Your task is to combine the outputs of two orientation selective ganglion cells to detect a specific shape: the shape arising from the combination of lines that activate RGC1 and RGC2. For example, you can build a detector for an X, T, L, or +.

To make this even more exciting, you’ll first have to build a buzzer that sounds only when the target shape is present, meaning that the buzzer will only sound when both ganglion cells are activated (this is an example of an AND gate). To build the buzzer circuit, please consult the RetINaBox User Manual. Once you have built the buzzer circuit, connect the outputs of the two ganglion cells (the 3.3V digital out pins on the back of RetINaBox) and one of the grounds, to the buzzer circuit (see Figure 24). If you have connected the buzzer circuit correctly, it will only sound when you present your target shape. This is similar to how many neuroscientists perform their experiments—for instance, David Hubel and Torsten Wiesel, who discovered orientation selective tuning in the visual cortex of cats, often plugged in their electrophysiological recording signal into a speaker, and listened to the neurons responding as they presented visual stimuli.

Figure 24. Circuit wiring of the buzzer. Please see the RetINaBox User Manual for detailed instructions.

This challenge emphasizes that the visual system builds complex feature detectors from simpler ones. In this activity, students combine two orientation-selective receptive fields to create a shape detector, illustrating how downstream neurons can integrate lower-level features to represent complex visual patterns.

## Lesson 3: Direction Selectivity

So far, we’ve seen that some visual neurons have receptive fields, and within these receptive fields some are tuned specific spatial frequencies of luminance contrast (thanks to ON/OFF and center-surround receptive fields, as outlined in lesson 1) and some are tuned to lines of specific orientations and lengths (thanks to orientation selective receptive fields, as outlined in lesson 2). But one important issue we haven’t considered yet is that things in the visual world are constantly moving. The wind blows trees, birds fly across the sky, cars zip by on the street. Additionally, we self-generate a lot of movement in our visual field every time we move our eyes or head, move our torso, or walk around. To deal with all these movements of our visual scene, it turns out that some visual neurons have evolved to be tuned to the direction of motion—they respond best when something moves in a particular direction within the visual field.

Visual neurons with direction selective receptive fields help our brain know if something is approaching, moving away, or moving tangentially to us (see Figure 25). This ability is vital for survival—it helps animals track prey, avoid predators, and navigate through the world.

Figure 25. Detecting motion in the visual world can be important for many tasks. Animals, like fish in the example here, rely on this ability to distinguish potential prey and other fish (e.g., left; small fish swimming in random directions) from predators (right; large looming shark quickly approaching).

Direction selective responses can also help us differentiate movement in the visual world that we generate (by moving our bodies/heads/eyes) from motion that is external to us (like a bird flying in the sky; Figure 26). The visual system needs to be able to distinguish both types of motion to appropriately navigate through our environment and interact with the external world. *However, please note that that direction selective circuits you’ll build with RetINaBox are simple motion detectors that won’t be able to differentiate between self-generated and external motion. The direction selective cells you’ll make with RetINaBox can only detect the direction in which patterns move across its visual field.


Figure 26. Distinguishing self-generated motion from external motion is important for many tasks. In this example, a shark approaching its prey must distinguish optic flow generated by its own movement from the movement of the fish it wishes to eat, which are also in motion. To successfully reach its target, the shark must integrate both self-motion and external motion signals.

To generate preferences for stimuli moving in specific directions, our visual system takes advantage of the fact that a moving stimulus will activate spatially-offset photoreceptors that connect to a single downstream visual neuron in temporal sequence along the trajectory of movement—that is, photoreceptors on the leading edge of the moving stimulus get activated first, while photoreceptors on the trailing edge of the moving stimulus get activated last. This means that, for a downstream neuron receiving signals from multiple spatially-adjacent photoreceptors, when a stimulus moves there is a time delay between when the downstream neuron receives signals from photoreceptors on leading versus trailing edges of its receptive field (see Figure 27).

Figure 27. As something moves across your visual field, different photoreceptors with spatially offset receptive fields are activated in sequence. Photoreceptors at the leading edge of the motion (left in the example above) respond first, followed by those in the middle, and finally the trailing edge (right). This sequential activation produces time-delayed signals that the visual system can use to detect the direction of motion.

How are direction selective receptive fields implemented in the visual system?

Directly selectivity arises when neurons selectively respond to motion in a particular direction. Below we outline some methods the brain can use to implement direction selective receptive fields from spatially-offset photoreceptor-mediated signals.

In Figure 28, two neurons with adjacent receptive fields (blue and pink) both synapse onto a downstream neuron (purple). The downstream neuron fires only if the excitatory signals from both inputs arrive simultaneously. A stimulus moving rightward will first activate the blue neuron, whose signal reaches the downstream neuron slightly earlier than the pink neuron’s signal. However, if a time delay (Δt) is introduced to the signal transmission from the blue cell to the purple cell, then motion in one specific direction (rightwards) causes both excitatory inputs to arrive together, summating and driving the downstream neuron to fire—this is the downstream neuron’s preferred direction. Motion in the opposite direction (leftwards) activates the pink cell first, and then the time delay with the blue cell means its input will not summate with that of the pink cell—this is the null direction.

Figure 28. Circuitry underlying a direction-selective responses of a neuron that maximally responds to rightward motion. Two possible mechanisms could generate this delay in a purely excitatory circuit. First, introducing a delay in the presynaptic (blue) neuron, so that there is a lag between when it first fires and when its signal reaches the downstream neuron (left). Alternatively, the delay could occur within the postsynaptic (purple) neuron’s dendrites, where the signal from the blue neuron takes slightly longer to reach to the cell body (right). Both these mechanisms ensure that the excitatory signals from the pink neuron and blue neuron arrive at the downstream purple neuron simultaneously and summate only for rightward motion to drive firing of the downstream neuron.

While the circuit above only utilized a time delay between two excitatory inputs to generate directionally selective responses, another method involves using a time delay of an inhibitory input neuron. In Figure 29, two neurons with adjacent receptive fields (blue and pink) both synapse onto a downstream neuron (purple). A stimulus moving leftward will first activate the pink neuron, whose signal reaches the downstream neuron slightly earlier than the blue neuron’s signal.

However, when a time delay (Δt) is introduced to the inhibitory pink neuron’s inputs, motion in the null direction (leftwards) causes both excitatory and inhibitory inputs to arrive together, effectively cancelling each other out, and preventing firing of the downstream neuron.


Figure 29. Alternative circuitry underlying a direction-selective responses of a neuron that only responds to motion moving rightward. Two possible mechanisms could generate this delay in a circuit with mixed excitatory and inhibitory inputs. First, introducing a delay in the presynaptic (pink) neuron, so that there is a lag between when it first fires and when its signal reaches the downstream neuron (left). Alternatively, the delay could occur within the postsynaptic (purple) neuron’s dendrites, where the signal from the pink neuron takes slightly longer to reach to the cell body (right). Both these mechanisms ensure that inhibitory signals from the pink neuron and excitatory signals from the blue neuron arrive at the downstream purple neuron simultaneously, cancelling each other out and preventing firing of the downstream neuron.

Lesson 3 Objective

Build a circuit that models a direction selective retinal ganglion cell to understand how the visual system detects motion. First, test your circuit by activating different combinations of LEDs (use the GUI’s ‘Motion’ mode, and select a speed and direction of motion). Then, sweep your hand across RetINaBox’s field of view to test the robustness of your circuit.

The key to direction selectivity lies in asymmetric anatomical connections that differentially process visual stimuli moving in one direction vs. the other. In RetINaBox, these asymmetric differences can be implemented with time delays (see above for more info on delays) that can be asymmetrically added in the Connectivity Manager along the right-left axis of the 3 x 3 photoreceptor array. These delays ensure that inputs to an RGC only summate (and the ganglion cell fires) when a stimulus moves in the RGC’s preferred direction.

Note

- In this section, wave your hand back and forth between the LEDs and photoreceptors to test your circuit’s functionality. *We don’t recommend using the Visual Stimulus Tool to test moving stimuli, due to edge artifacts that can drive spurious responses when the outer boundaries of the Visual Stimulus Tool enter and exit RetINaBox’s visual field

Depending on the time delays you’ve assigned to each photoreceptor, you may need to test different stimulus speeds (i.e. move your hand at different speeds) to observe the ganglion cell firing specifically to a single direction of movement.

Activity #1: build a leftward motion direction selective ganglion cell ß
Build a circuit where RGC1 responds to a vertical line of light moving leftwards. Test your circuit by moving your hand across your array in both left and right directions.

This activity emphasizes how direction selective circuits detect motion in a specific direction, illustrating how time delays along the preferred-null motion axis and specific circuit wiring determines a neuron’s preferred direction of motion.

Activity #2: build a rightward motion direction selective ganglion cell à
Next, build a second circuit so that RGC2 responds to a vertical line of light moving rightwards. Test your circuit by moving your hand across your array in both right and left directions. You should now be able to selectively activate RGC1 when you hand sweeps leftward across the RetINaBox photoreceptor array, whereas only RGC2 gets activated when you sweep your hand rightward.

This activity emphasizes that the same photoreceptors can contribute to multiple direction-selective circuits with different preferred directions, depending on the configuration of the connections to the downstream neuron.

Activity #3: build a slow vs. fast motion preferring direction selective ganglion cell à
Build a circuit where RGC1 responds to a vertical line of light slowly moving rightwards, while RGC2 responds to a vertical line moving in the same direction, but more quickly. Test your circuit by moving your hand rightwards across your array at various speeds or use the Visual Stimulus Controller to run various speeds of a vertical line moving rightward vs. leftward. *Tip – to generate RGCs with preferences for different speeds, think about what changing the time delay will accomplish.

This activity emphasizes how the timing of inputs can alter a neuron’s preferred speed of motion, demonstrating an example of temporal frequency selectivity.

Challenge: Block Breaking with direction selective circuits
Block Breaker is an arcade game where players control a paddle using leftward and rightward inputs to bounce a ball to break several rows of blocks. The goal is to clear all the blocks without letting the ball drop. Your task is to configure the 2 RGCs with opposite direction selectivity (i.e. make two robust direction selective ganglion cells, one for leftward motion, the other for rightward motion) and use them as the input controls for the game inside the RetINaBox GUI.
- Step 1: In the Connectivity Manager, configure both ganglion cell circuits so that RGC1 is selective only for leftward motion and RGC2 is selective only for rightward motion.
- Step 2: Load the game. From the Menu tab in the GUI, navigate to ‘Block Breaker’ (Lessons > Lesson 3 > Block Breaker).
- Step 3: You’re now ready to play (see Figure 30)! The block breaker paddle is controlled by the output responses from RGC1 and RGC2.

Figure 30. Block Breaker in the RetINaBox GUI. GC1 activation moves the paddle to the left, while GC2 activation moves the paddle to the right.

This challenge emphasizes how direction-selective circuits allow the visual system to detect motion in specific directions, and how the outputs of RetINaBox can be used to interact with external systems. Furthermore, the point can be emphasized that if we consider RetINaBox to be a model of the brain/retina, and since here we are controlling a computer with the output from RetINaBox, this can be considered as a model of a brain-computer-interface (BCI).

## Lesson 4: Discovery Mode

Welcome to Discovery Mode! You’ve made it this far, which means that you’re ready to perform some real experiments! In this section you’ll get a taste of what it it’s really like to be a visual neuroscientist!

So far, you’ve explored ON/OFF, center-surround, orientation selective, and direction selective receptive fields—all circuits that have already been well characterized by vision scientists. But the quest to understand what neurons in the brain “like to see” is far from over. Even today, neuroscientists are still working to discover which kinds of stimuli best activate visual neurons in various parts of the brain. Now it’s your turn discover which visual stimuli best activate some newly discovered visual neurons in RetINaBox and then discover what circuit connectivity properties underlie their feature selective responses.

In Discovery Mode (see Figure 31), there are three levels of difficulty (Easy, Medium, Hard), each with their own set of challenges. To complete each challenge, you’ll need to discover (i.e. correctly submit an answer) the mystery ganglion cell’s target visual stimulus (the visual response that drives that ganglion cell) and the circuit connectivity (the settings in the Connectivity Manager) that underlie this feature selective response. For each challenge, you’ll start with 100 points, but incorrect answers cost you 5 points. Your goal is to complete each challenge with the highest score possible.

Figure 31 Discovery Mode GUI. Each challenge has two phases: (1) discovering the preferred stimulus (left) and (2) discovering the circuit connectivity (right)

Each challenge in Discovery Mode has two steps:

Phase 1: Discover the Preferred Stimulus

From the Menu tab, navigate to ‘Discovery Mode’ (Lessons > Lesson 4 > Discovery Mode). After selecting a mystery circuit from the drop-down menu in the GUI, your first task is to figure out which visual stimulus activates the RGC. Does it prefer a specific shape? A particular direction of motion? Using your Visual Stimulus Controller, or the Visual Stimulus Tool, or some pieces of paper cut out with various shapes (or even your hands if you’re dextrous), test different static stimuli. Use your hand to test direction selective stimuli. The mystery circuits in RetINaBox are very selective to specific visual stimuli, so make sure you’re certain before submitting your answer.

Phase 2: Discover the Circuit Connectivity

Once you've discovered what the ganglion cell is tuned to, your next challenge is to discover how it obtains this selectivity. How are the photoreceptors connected to the ganglion cell? What kinds of delays, polarities, or spatial arrangements of the photoreceptors give rise to the ganglion cell’s feature selective response? Apply the correct settings to the Connectivity Manager to match the feature selectivity you discovered.

Please note:

- For challenges including moving stimuli, the speed of motion specified in Step 1 must match the time delay applied to the circuit in Step 2 (e.g., faster motion requires a shorter delay)
- Each challenge can be solved using either the ON or OFF pathway (both versions of the circuit solutions should respond to the same stimulus).

Good luck! Securing grant funding for your lab depends on your success! ;)

## Appendix

## Lesson 1 Solutions: ON/OFF and Center-Surround

Activity #1: build a spot detector with an ON-center/OFF-surround receptive field

The center photoreceptor (red) is excitatory (+): it activates the ganglion cell when it detects light.
- Connect the center photoreceptor to a ganglion cell with positive polarity (excitatory).

The surround photoreceptors (blue) are inhibitory (-): they suppress the ganglion cell when they are activated.
- Connect each surround photoreceptor to the same ganglion cell with negative polarity (inhibitory).

Set the ganglion cell’s threshold to 1. Set the cell type to ON. The ganglion cell will fire only when the center photoreceptor receives light. However, if any of the surround photoreceptors are also lit, their inhibition will cancel out the excitation, and the ganglion cell will not fire.

Lesson 1, Activity 1: Inputs & wiring to RGC1 (center-surround cell with center receptive field)

Activity #2: build a second spot detector with a different receptive field location

Please note that the following are just two possible examples of correct solutions. However, you could have selected any receptive field within the 3 x 3 array for either ganglion cell.

Example solution 1

Inputs to RGC2: A corner photoreceptor (red) is excitatory (+): it activates the ganglion cell when it detects light. All other surround photoreceptors (blue) are inhibitory (–): they suppress the ganglion cell when they are activated. Set ganglion cell threshold to 1. Set the cell type to ON.

Lesson 1, Activity 2 – Example solution: Inputs and wiring to RGC2 (center-surround cell with a top left corner receptive field)

Example solution 2

Inputs to RGC2: An edge photoreceptor (red) is excitatory (+): it activates the ganglion cell when it detects light. All other surround photoreceptors (blue) are inhibitory (-): they suppress the ganglion cell when they are activated. Set ganglion cell threshold to 1. Set the cell type to ON.

Lesson 1, Activity 2 – Alternative example solution: Inputs and wiring to RGC2, whose receptive field is on the edge of the array (center-surround cell with a bottom edge receptive field)

Activity #3: build a second spot detector with the opposite polarity

Inputs to RGC2: Set the cell type to OFF—this inverts the photoreceptor logic. Specifically, the center photoreceptor, which should be OFF excitatory (red, +) activates the ganglion cell when it does not detect light. All other surround photoreceptors (blue) are OFF inhibitory (–): they activate the ganglion cell when they do not detect light. Set ganglion cell threshold to 1. This OFF-center/ON-surround cell will only fire when the surround is illuminated while the center remains dark.

Lesson 1, Activity 3 – Inputs and wiring to RGC2 (OFF-center/ON-surround cell with a central receptive field)

Activity #4: build two spot detectors with preferences for spots of different sizes

Inputs to RGC1 (small spot detector): as described in Solutions to Activity #1: The center photoreceptor (red) is excitatory (positive polarity, +), while all other surround photoreceptors (blue) are inhibitory (negative polarity, -). Set the ganglion cell threshold to 1. Set the cell type to ON. This ganglion cell will only fire in response to a small spot of light illuminating the center photoreceptor.


Lesson 1, Activity 4 – RGC1 wiring: Inputs & wiring to RGC1 (small center-surround cell with center receptive field)

Inputs to RGC2 (larger spot detector): The center photoreceptor (red) is excitatory (positive polarity, +) and will activate the ganglion cell when it detects light. However, the nearest surround photoreceptors (directly above, below, and to the sides) are also excitatory (+). The corner photoreceptors (blue) are inhibitory (negative polarity, -): they suppress the ganglion cell if the stimulus becomes too large. Set the ganglion cell’s threshold to 5. Set the cell type to ON. This ganglion cell will fire in response to a larger spot of light illuminating the center photoreceptor and its side-surround photoreceptors. However, if the spot becomes too large and any of the corner surround photoreceptors are also lit, this added inhibition will subtract from the excitation, and the ganglion cell will not reach threshold to fire.

Lesson 1, Activity 4 – RGC2 wiring: Inputs & wiring to RGC2 (larger center-surround cell)

Challenge: Codebreaking with spot detectors

Challenge #1

Inputs to RGC1: This center-surround cell responds only when the four photoreceptors on the top right are activated. These four photoreceptors should have positive polarity (red, excitatory, +). All other surround photoreceptors have negative polarity (blue, inhibitory, -). The bottom left photoreceptor is left unconnected (grey), so that RGC1 and RGC2 can be co-activated. The ganglion cell threshold is set to 4. The cell type is set to ON.

Lesson 1, Challenge 1: Inputs & wiring to RGC1 (large spot detector with top right receptive field position)

Inputs to RGC2: This center-surround cell responds only when the bottom left photoreceptor is activated. This photoreceptor should have positive polarity (red, excitatory, +). All other surround photoreceptors have negative polarity (blue, inhibitory, -), except for the top 4 photoreceptors, corresponding RGC1’s receptive field center (see above), which should be left unconnected (grey). This ensures that RGC1 and RGC2 can be co-activated. The ganglion cell threshold is set to 1. Set the cell type to ON.


Lesson 1, Challenge 1: Inputs & wiring to RGC2 (small spot detector with bottom left receptive field)

Secret message #1: Dear reader, dread red area.

Extra problems

Challenge #2

Inputs to RGC1: This center-surround cell responds only when the top right corner photoreceptor is activated. This photoreceptor should have positive polarity (red, excitatory, +). All other surround photoreceptors have negative polarity (blue, inhibitory, -), except for the center and bottom photoreceptors in the middle and right column, which are left silent (grey), so that RGC1 and RGC2 can be co-activated. The ganglion cell threshold is set to 1. The cell type is set to ON.

Lesson 1, Challenge 2: Inputs & wiring to RGC1 (spot detector with top right receptive field)

Inputs to RGC2: This cell is selective to a medium-sized spot in the bottom right corner of the array. It responds only when the four photoreceptors in the bottom right of the array are activated. These photoreceptors should have positive polarity (red, excitatory, +). All other surround photoreceptors have negative polarity (blue, inhibitory, -), except for the photoreceptor connected to RGC1’s center, which should be left silent. The ganglion cell threshold is set to 4. Set the cell type to ON.

Lesson 1, Challenge 2: Inputs & wiring to RGC2 (vertical line-segment detector)

Secret message #2: A rare rat ate a tree.

Challenge #3

Inputs to RGC1: This cell is selective to a medium sized spot of light in the bottom left corner of the array. It responds only when the four photoreceptors in the bottom left corner are activated. These photoreceptors should have positive polarity (red, excitatory, +). All other surround photoreceptors have negative polarity (blue, inhibitory, -), except for the center and bottom photoreceptors in the right column, which are left silent (grey), so that RGC1 and RGC2 can be co-activated. The ganglion cell threshold is set to 4. The cell type is set to ON.

Lesson 1, Challenge 3: Inputs & wiring to RGC1 (vertical line-segment detector)

Inputs to RGC2: This cell is selective to a medium sized spot of light in the bottom right corner of the array. It responds only when the four photoreceptors in the bottom right corner are activated. These photoreceptors should have positive polarity (red, excitatory, +). All other surround photoreceptors have negative polarity (blue, inhibitory, -), except for the center and bottom photoreceptors in the left column, which are left silent (grey), so that RGC1 and RGC2 can be co-activated. The ganglion cell threshold is set to 4. The cell type is set to ON.

Lesson 1, Challenge 3: Inputs & wiring to RGC2 (horizontal line-segment detector)

Secret message #3: Mamma Mia! I am mad.

Challenge #4

Inputs to RGC1: This center-surround cell is selective to a small spot of light. It responds only when the center photoreceptor is activated. This photoreceptor should have positive polarity (red, excitatory, +). All other surround photoreceptors have negative polarity (blue, inhibitory, -), except for the photoreceptor connected to RGC2’s center, which should be left silent. The ganglion cell threshold is set to 1. The cell type is set to ON.

Lesson 1, Challenge 4: Inputs & wiring to RGC1 (orientation selective cell).

Inputs to RGC2: This center-surround cell responds only when the right photoreceptor in the middle row is activated. This photoreceptor should have positive polarity (red, excitatory, +). All other surround photoreceptors have negative polarity (blue, inhibitory, -), except for the center photoreceptors, which is left silent (grey), so that RGC1 and RGC2 can be co-activated. The ganglion cell threshold is set to 1. The cell type is set to ON.

Lesson 1, Challenge 4: Inputs & wiring to RGC2 (spot detector with right side receptive field).

Secret message #4: He ate the hat.

Challenge #5


Inputs to RGC1: This center-surround cell responds only when the four photoreceptors on the bottom right are activated. These four photoreceptors should have positive polarity (red, excitatory, +). All other surround photoreceptors have negative polarity (blue, inhibitory, -), except for the photoreceptor connected to RGC2’s center, which should be left silent. The ganglion cell threshold is set to 4. The cell type is set to ON.

Lesson 1, Challenge 5: Inputs & wiring to RGC1 (larger spot detector with bottom right receptive field)

Inputs to RGC2: This center-surround cell responds only when the middle photoreceptor in the top row is activated. This photoreceptor should have positive polarity (red, excitatory, +). All other surround photoreceptors have negative polarity (blue, inhibitory, -), except for the photoreceptors connected to RGC1’s center, which should be left silent. The ganglion cell threshold is set to 1. The cell type is set to ON.


Lesson 1, Challenge 5: Inputs & wiring to RGC2 (spot detector with top center receptive field)

Secret message #5: Bake a cake.

Challenge #6

Inputs to RGC1: This center-surround cell responds only when the top left corner photoreceptor is activated. This photoreceptor should have positive polarity (red, excitatory, +). All other surround photoreceptors have negative polarity (blue, inhibitory, -), except for bottom right photoreceptors, which is left silent (grey), so that RGC1 and RGC2 can be co-activated. The ganglion cell threshold is set to 1. The cell type is set to ON.

Lesson 1, Challenge 6: Inputs & wiring to RGC1 (spot detector with top left receptive field)

Inputs to GC 2: This center-surround cell is selective to a spot of light in the bottom right corner of the photoreceptor array. It responds only when the bottom right photoreceptor is activated. This photoreceptor should have positive polarity (red, excitatory, +). All other surround photoreceptors have negative polarity (blue, inhibitory, -), except for the photoreceptor connected to RGC2’s center, which should be left silent. The ganglion cell threshold is set to 1. The cell type is set to ON.

Lesson 1, Challenge 6: Inputs & wiring to RGC2 (orientation selective cell)

Secret message #6: Pack a cap.

## Lesson 2 Solutions: Orientation Selectivity

Activity #1: build a ganglion cell that detects a vertical line

Inputs to Ganglion Cell 1: Connect 3 adjacent photoreceptors in a straight vertical line (e.g., middle column) to the ganglion cell, with a positive (excitatory, +) polarity. Connect the 6 other surrounding photoreceptors to the same ganglion cell, with a negative (inhibitory, -) polarity. Set the ganglion cell threshold to 3, and the cell type to ON, so that the ganglion cell will only fire when all 3 photoreceptors are activated.

Lesson 2, Activity 1: Inputs & wiring to RGC1 (vertical orientation selective cell)

Please note that the above represents just one of three possible examples of a correct solution. However, you could have selected a vertical receptive field in the left or right column of the 3 x 3 array.

Activity #2: build an OFF-ganglion cell that detects a vertical line

Inputs to Ganglion Cell 2: Set the cell type to OFF. Connect 3 adjacent photoreceptors in a straight vertical line (e.g., middle column) to the ganglion cell, with a positive (excitatory, +) polarity. Connect the 6 other surrounding photoreceptors to the same ganglion cell, with a negative (inhibitory, -) polarity. Set the ganglion cell threshold to 3, so that the ganglion cell will only fire when all 3 photoreceptors in the center column are dark, but the surround (left and right columns) is illuminated.


Lesson 2, Activity 2: Inputs & wiring to RGC2 (vertical orientation selective OFF cell)

Activity #3: build a second ganglion cell that detects a diagonal line

Inputs to Ganglion Cell 2: Connect 3 photoreceptors along the diagonal line to the ganglion cell, with a positive (excitatory, +) polarity. Connect the 6 other off-diagonal photoreceptors to the same ganglion cell, with a negative (inhibitory, -) polarity. Set the ganglion cell threshold to 3, and the cell type to ON, so that the ganglion cell will only fire when all 3 photoreceptors are activated but will be inhibited if any of the off-diagonal photoreceptors are activated.

Lesson 2, Activity 3: Inputs & wiring to RGC2 (diagonal orientation selective cell)

Please note that the above represents just one of two possible examples of a correct solution. However, you could have selected a diagonal receptive field oriented at 135o (i.e., the other diagonal).

Activity #4: build two ganglion cells that detect vertical lines of different thicknesses

Inputs to Ganglion Cell 1: connect two adjacent columns of 3 photoreceptors in a vertical line (for example, middle column + side column) to Ganglion Cell 1, with a positive (excitatory, -) polarity. Connect the 3 other surround photoreceptors to the same ganglion cell, with a negative (inhibitory, -) polarity. Set the ganglion cell threshold to 6, and the cell type to ON, so that the ganglion cell will only fire when all 6 photoreceptors are activated.


Lesson 2, Activity 4: Inputs & wiring to RGC1 (thick vertical orientation selective cell)

Inputs to Ganglion Cell 2: connect one column of 3 photoreceptors in a vertical line (for example, right column) to Ganglion Cell 2, with a positive (excitatory, +) polarity. Connect the 6 other surrounding photoreceptors to the same ganglion cell, with a negative (inhibitory, -) polarity. Set the ganglion cell threshold to 3, and the cell type to ON, so that the ganglion cell will only fire when all 3 photoreceptors are activated.

Lesson 2, Activity 4: Inputs & wiring to RGC2 (thin vertical orientation selective cell)

Please note that the above represents one of several possible examples of a correct solution. You could have configured each ganglion cell with vertical receptive field in various locations (i.e., shifted left or right).

Activity #5: build two ganglion cells that detect vertical lines of different lengths (end stopping).

Inputs to Ganglion Cell 1: Connect 3 adjacent photoreceptors in a straight vertical line (e.g., middle column) to the ganglion cell, with a positive (excitatory, +) polarity. Connect the 6 other surrounding photoreceptors to the same ganglion cell, with a negative (inhibitory, -) polarity. Set the ganglion cell threshold to 3, and the cell type to ON, so that the ganglion cell will only fire when all 3 photoreceptors are activated by a vertical line of light.

Lesson 2, Activity 5: Inputs & wiring to RGC1 (vertical orientation selective cell)

Inputs to Ganglion Cell 2: Connect 2 adjacent photoreceptors in a straight vertical line (e.g., middle column) to the ganglion cell, with a positive (excitatory, +) polarity. Connect the 7 other surrounding photoreceptors to the same ganglion cell, with a negative (inhibitory, -) polarity. Set the ganglion cell threshold to 2, and the cell type to ON, so that the ganglion cell will only fire when both photoreceptors are activated by a vertical line of light of a specific length. RGC2 will be inhibited should the line extend past its excitatory receptive field (i.e., if the line is too long).

Lesson 2, Activity 5: Inputs & wiring to RGC2 (end-stopped vertical orientation selective cell)

Challenge #1: build a shape detector with orientation selective receptive fields

Please note that the solution below represents one of several possible correct solutions. You could have chosen any potential shape combining two straight lines of any orientation (for example, an X, a T, or an L - in any orientation). The below solution will configure a shape detector responsive to an ‘X’ shape.

Each of the ganglion cells should be responsive to a line in a different position/orientation. They should both fire when the shape is presented (i.e. each ganglion cell must not be silenced when the other ganglion cell is active).

Inputs to Ganglion Cell 1: To make a cross shape, we would like Ganglion Cell 1 to be responsive to a vertical line in the middle of the photoreceptor array. Connect 3 adjacent photoreceptors (e.g. a vertical line) to a ganglion cell with a positive (excitatory, +) polarity, so that it fires only when all 3 photoreceptors are activated (i.e., when a vertical bar of light is present in the center of the array). The cells in the corner of the array should be inhibitory (-), while the two left and right cells in the center row should be inactivated (grey). This will make the cell orientation selective but also continue to respond when Ganglion Cell 2 (see below) is activated.


Lesson 2, Challenge 1: Inputs & wiring to RGC1 (vertical orientation selective cell)

Inputs to Ganglion Cell 2: To make a cross shape, we would like Ganglion Cell 2 to be responsive to a horizontal line in the middle of the photoreceptor array. Connect 3 adjacent photoreceptors (e.g. a horizontal line) to the second ganglion cell with a positive (excitatory, +) polarity, so that it fires only when all 3 photoreceptors are activated (i.e., when a horizontal bar of light is present in the center of the array). Similar to above, adding inhibition to the corner photoreceptor connections (negative polarity, -) while inactivating the top and bottom cells in the middle column will make the cell orientation selective, but still allow it to respond when RGC1 is active.

Lesson 2, Challenge 1: Inputs & wiring to RGC2 (horizontal orientation selective cell)

## Lesson 3 Solutions: Direction Selectivity

Note: Depending on the time delays you’ve assigned to each photoreceptor, you may need to test different stimulus speeds to observe the ganglion cell firing specifically in one direction. The circuit will work most robustly when the speed of motion is tailored to the timing of the delays, allowing all preferred-direction inputs to summate at the ganglion cell simultaneously during preferred-direction motion, and allowing null-direction inhibition to effectively cancel excitation during null-direction motion.

Activity #1: build a left-moving direction selective ganglion cell ß

The ganglion cell receives input from two full columns of excitatory photoreceptors (positive polarity) and one full column of inhibitory photoreceptors (negative polarity).

- Left-most photoreceptor column (inhibitory, -): short/medium time delay
- Middle photoreceptor column (excitatory, +): No time delay
- Right-most photoreceptor column (excitatory, +): short/medium time delay

Set the ganglion cell threshold to 6 and the cell type to ON. This ensures that the cell will only fire when both columns of excitatory photoreceptors (6 photoreceptors in total) are activated in sync, i.e., when the direction of motion is leftwards, and the timing aligns perfectly for input summation.

This configuration causes the ganglion cell to fire only when a stimulus moves leftward across the array. The stimulus sequentially activates the rightmost, middle, and finally left column photoreceptors. The delays are configured so that the signals from the two excitatory columns arrive at the ganglion cell simultaneously only during leftward motion, allowing the cell to reach threshold and fire. The inhibitory column’s input, being delayed, arrives too late to interfere with the ganglion cell’s response. If the stimulus moves rightward (i.e., the opposite direction to the ganglion cell’s preferred direction), the inhibitory column will summate with the excitatory column, cancelling out excitation and preventing the ganglion cell from firing. Furthermore, the two columns of excitatory inputs will be activated out of phase with one another for rightward motion. *note that if you simply stimulate the 6 positively connected photoceptors (while not stimulating the 3 negatively connected photoreceptors) with a static stimulus, the ganglion cell will eventually turn on as well (similar to what happens for many direction selective ganglion cells in the brain which can sometimes be activated by both preferred direction moving and static stimuli).


Lesson 3, Activity 1: Inputs & wiring to RGC1 (left-moving direction selective cell)

Activity #2: build a right-moving direction selective ganglion cell à

The ganglion cell receives input from two full columns of excitatory photoreceptors (positive polarity) and one full column of inhibitory photoreceptors (negative polarity).

- Left-most photoreceptor column (excitatory, +): short/medium time delay
- Middle photoreceptor column (excitatory, +): No time delay
- Right-most photoreceptor column (inhibitory, -): short/medium time delay

Set the ganglion cell threshold to 6 and the cell type to ON. This ensures that the cell will only fire when both columns of excitatory photoreceptors (6 photoreceptors in total) are activated in sync, i.e., when the direction of motion is rightwards, and the timing aligns perfectly for input summation. Please refer to Activity #1 Solution for a detailed explanation of time-aligned input summation.

Lesson 3, Activity 2: Inputs & wiring to RGC2 (right-moving direction selective cell)

Activity #3: build a slow vs. fast motion preferring direction selective ganglion cell à

The key to solving this problem is the magnitude of the time delays imposed on the circuits seen in Activity #1 (right-direction selective cell).

Each ganglion cell receives input from two full columns of excitatory photoreceptors (positive polarity) and one full column of inhibitory photoreceptors (negative polarity). Set each ganglion cell threshold to 6 and the cell type to ON. This ensures that the cell will only fire when both columns of excitatory photoreceptors (6 photoreceptors in total) are activated in sync.

Inputs to RGC1 (slow-moving à directions-selective cell):
- Left-most photoreceptor column (excitatory, +): long time delay
- Middle photoreceptor column (excitatory, +): no time delay

- Right-most photoreceptor column (inhibitory, -): long time delay

Lesson 3, Activity 3: Inputs & wiring to RGC1 (slow right-moving direction selective cell)

Inputs to RGC2 (fast-moving à directions-selective cell):

- Left-most photoreceptor column (excitatory, +): short time delay
- Middle photoreceptor column (excitatory, +): no time delay
- Right-most photoreceptor column (inhibitory, -): short time delay

A shorter time delay creates a smaller time window for inputs to summate, so the stimulus must move faster to activate the ganglion cell. Conversely, a longer time delay creates a wider summation window, allowing the cell to respond to slower motion. Please refer to Activity #1 Solution for a detailed explanation of time-aligned input summation.


Lesson 3, Activity 3: Inputs & wiring to RGC2 (fast right-moving direction selective cell) Challenge: Block breaking with direction selective circuits

Inputs to RGC1 ß: the ganglion cell receives input from two full columns of excitatory photoreceptors (positive polarity) and one full column of inhibitory photoreceptors (negative polarity). Set the ganglion cell threshold to 6 and the cell type to ON.

- Left-most photoreceptor column (inhibitory, -): short time delay
- Middle photoreceptor column (excitatory, +): No time delay
- Right-most photoreceptor column (excitatory, +): short time delay

Lesson 3, Challenge 1: Inputs & wiring to RGC1 (left-moving direction selective cell)

Inputs to RGC2 à : the ganglion cell receives input from two full columns of excitatory photoreceptors (positive polarity) and one full column of inhibitory photoreceptors (negative polarity). Set the ganglion cell threshold to 6 and the cell type to ON.

- Left-most photoreceptor column (excitatory, +): short time delay
- Middle photoreceptor column (excitatory, +): No time delay
- Right-most photoreceptor column (inhibitory, -): short time delay


Lesson 3, Activity 4: Inputs & wiring to RGC2 (right-moving direction selective cell)
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

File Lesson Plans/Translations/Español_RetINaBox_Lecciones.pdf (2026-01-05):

# Lecciones

Versión 1.2

## Visión general del sistema visual: ¿Cómo vemos?

El procesamiento visual comienza en la retina, una fina lámina de tejido cerebral sensible a la luz ubicada en la parte posterior del ojo (sí, la retina es parte del cerebro).

Dentro de la retina, unas neuronas llamadas fotorreceptores detectan la luz y la convierten en señales electroquímicas. Mediante un proceso llamado fototransducción, los cambios en la intensidad de la luz alteran el potencial de membrana del fotorreceptor, es decir, el voltaje o la diferencia de potencial eléctrico entre el interior y el exterior de la célula. Este cambio en el potencial de membrana afecta la cantidad de glutamato, un neurotransmisor, que libera el fotorreceptor. Muchas neuronas se ‘comunican’ entre sí liberando glutamato, que puede ser detectado por las neuronas vecinas.

Estas señales mediadas por fotorreceptores son transmitidas por neuronas auxiliares llamadas células bipolares a las células ganglionares. Las señales que pasan del fotorreceptor àcélula bipolar àcélula ganglionar son moduladas por células horizontales y células amacrinas (Figura 1). Como resultado, las células ganglionares de la retina responden solo cuando existen características visuales específicas en el entorno. Por ejemplo, una célula ganglionar podría responder solo cuando aparece un punto de luz de un tamaño determinado, y otra célula ganglionar podría responder solo cuando un estímulo visual se mueve de izquierda a derecha a través del campo visual. Finalmente, las células ganglionares transmiten señales visuales fuera del ojo y al resto del cerebro a través del nervio óptico (Figura 1).


Figura 1. El ojo y la retina. La luz entra en el ojo, atraviesa la córnea, la pupila, el humor acuoso, el cristalino y el humor vítreo antes de incidir en la retina. En la retina, la luz es detectada por los fotorreceptores, que envían señales a las células ganglionares a través de una red de otras células retinianas. Las células ganglionares, a su vez, transmiten señales visuales a las áreas visuales superiores del cerebro.
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

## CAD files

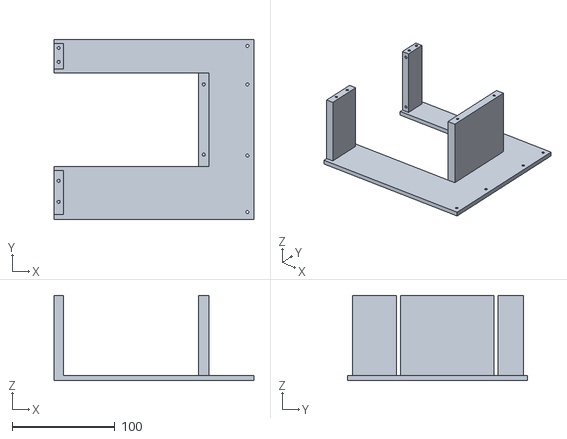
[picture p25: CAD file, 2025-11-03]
3D print files/RetINaBox_Case_Part4 .stl
195.0 x 176.0 x 83.0

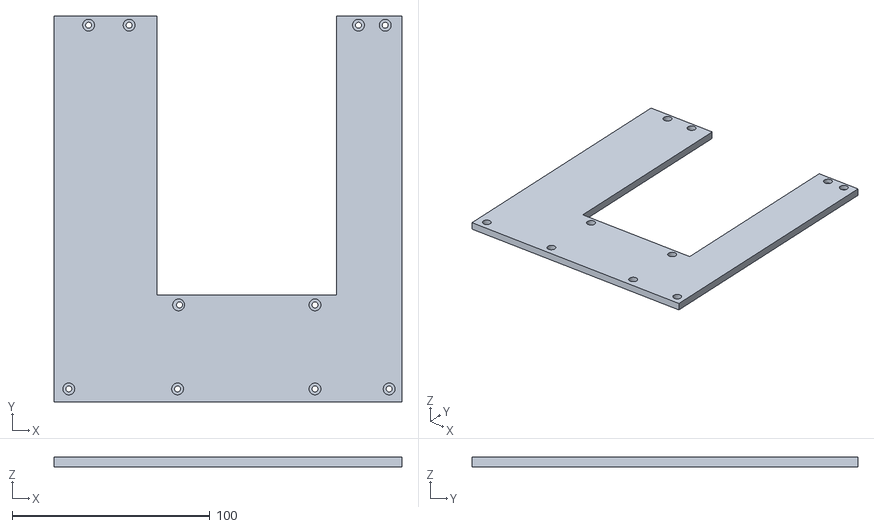
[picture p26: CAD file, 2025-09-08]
3D print files/RetINaBox_Case_Part6 .stl
176.0 x 195.0 x 5.00

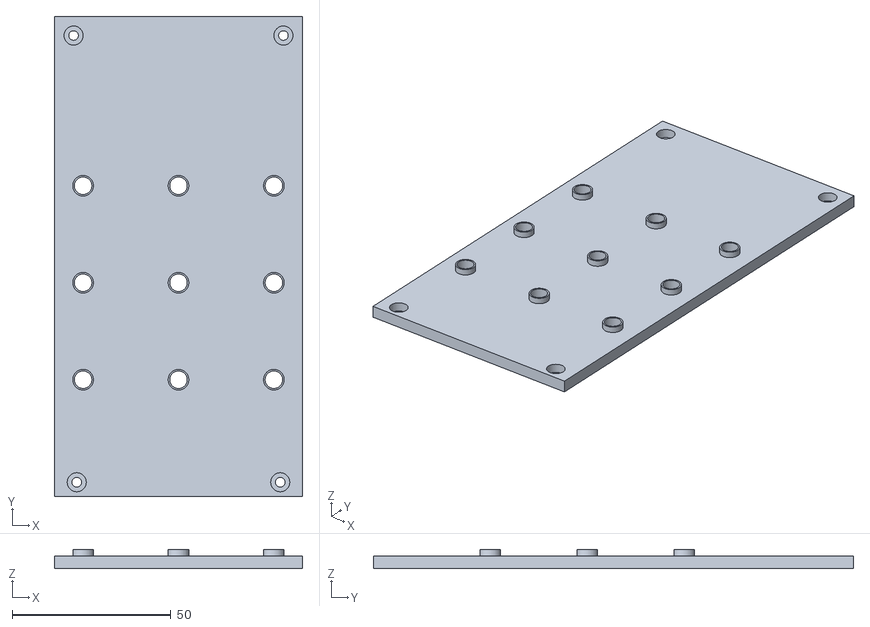
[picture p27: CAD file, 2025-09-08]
3D print files/RetINaBox_Case_Part2.stl
78.0 x 151.0 x 6.00

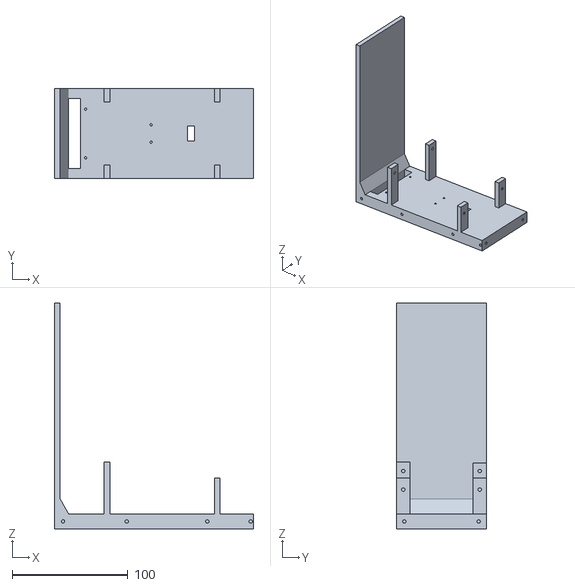
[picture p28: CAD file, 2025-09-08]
3D print files/RetINaBox_Case_Part1.stl
172.0 x 78.0 x 195.0

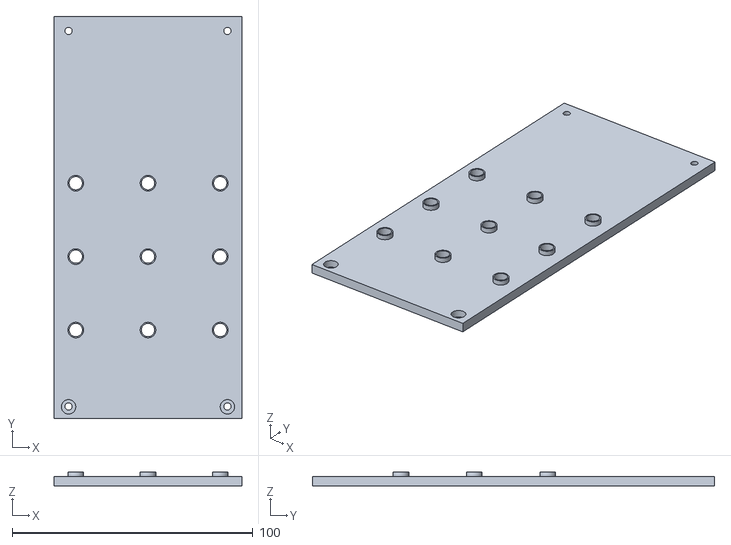
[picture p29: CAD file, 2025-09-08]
3D print files/RetINaBox_Case_Part3.stl
78.0 x 167.0 x 6.00

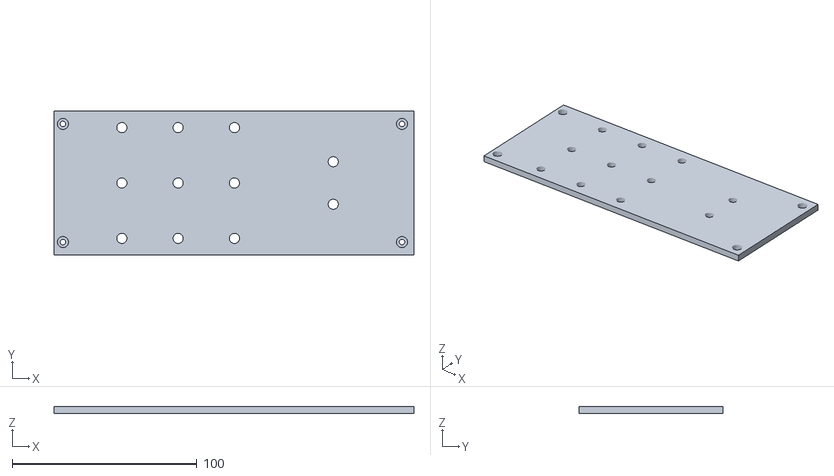
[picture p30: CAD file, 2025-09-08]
3D print files/RetINaBox_Case_Part5 .stl
195.0 x 78.0 x 4.00

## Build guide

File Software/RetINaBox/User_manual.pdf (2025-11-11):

## RetINaBox User Manual

### Instructions for setting up hardware and software

Version 1.2

## Table of contents

1. Introduction
2. Building RetINaBox
3. Generating Visual Stimuli
4. Installing the Software
5. Connecting RetINaBox to the Raspberry Pi
6. Using the Software

A1: Appendix 1: Components List
A2: Appendix 2: Troubleshooting A3: Appendix 3: Costs

### 1. INTRODUCTION

Welcome to the RetINaBox User Manual. Here you’ll find point-by-point instructions for building and assembling RetINaBox and for installing and using the software. In addition, we provide a full components list required to build RetINaBox. For those unfamiliar with working with electronics, don’t worry, you don’t need to solder anything. For those already familiar with electronics, the design of RetINaBox is simple, and it should be possible to build it with different LEDs, photodiodes, resistors, etc. than the exact ones specified here as long as those electronics components are compatible with the Raspberry Pi. Lastly, we provide a troubleshooting section in case you get through the manual and things still are not working correctly.

### 2. BUILDING RetINaBox

RetINaBox is built from a 3D-printed case that houses LEDs, photodiodes, and a bunch of wires that connect these components to the Raspberry Pi. The case is composed of six 3D printed pieces joined together, mostly with M3 screws of varying length (as outlined below). Although the case does not have to be assembled in the order indicated in the manual, the order we outline below ensures that case assembly is as straightforward as possible. Wiring the different components will be outlined as well, with electronics components being integrated into the case during the assembly process. Before starting, it is recommended to have all the necessary components and tools on hand. The assembling steps will be as follows:

a) Wiring
- Wiring the photodiodes
- Wiring the LEDs arrays
- IR LEDs arrays
- White LEDs arrays
- Coloured LEDs
b) Case Assembly
- Description of the 3D printed case parts
- Main parts of RetINaBox
c) Connecting electronics to Raspberry Pi GPIO
- Connecting the photodiodes to the GPIO
- Connecting 3.3V out pins to the GPIO
- Connecting the buzzer (for Lesson 2)
- Connecting the LED panels to the GPIO
- White LED panel
- Coloured LED panel

a) WIRING
1. Wiring the photodiodes (~30 min)
Materials needed: 9 infrared (IR) photodiodes, jumper wires, wire cutters
a. Have 9 photodiodes at hand. Remove or fold back the clear LED from the photodiodes (Fig. 1; these LEDs will not be used in RetINaBox). These photodiodes will be powered with a constant 3.3V from the Raspberry Pi, and the Raspberry Pi will also independently read the output signal from each photodiode (i.e. whether the photodiode is detecting light or not). Each photodiode board contains a potentiometer, which will be used to adjust light sensitivity (outlined below).

Figure 1. IR photodiodes.

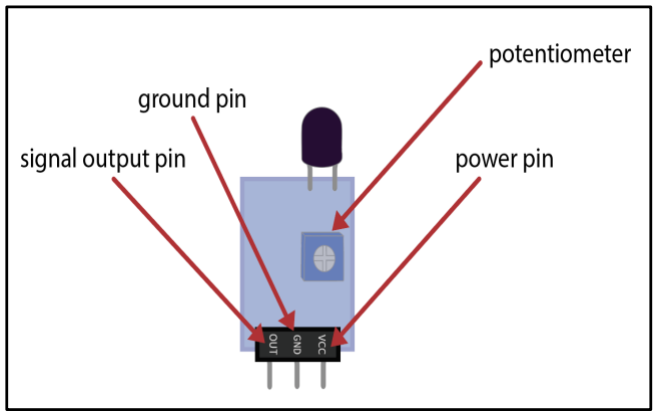
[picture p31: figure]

b. Put together 4 mini breadboards following the orientation of the diagram below (Fig. 2).

Figure 2. 4 mini breadboards.

c. Place the photodiodes on the mini breadboards as shown in the figure below (Fig. 3). It is important to respect the exact positioning as this ensures the photodiodes properly fit into the 3D printed case. *For the middle row, it may be easier to place the wiring first and then the photodiodes after.

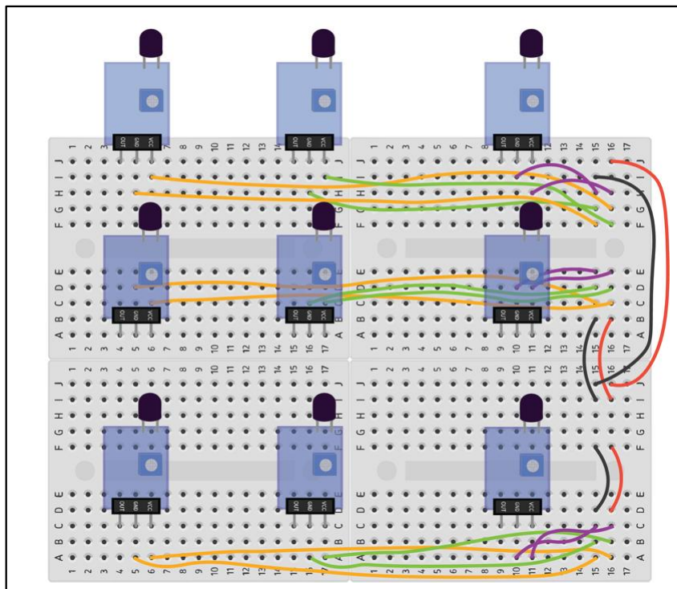
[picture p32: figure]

Figure 3: Placement of photodiodes and local wiring on breadboard.

2. Wiring the LEDs (~90 mins)
Materials needed: 9 white LEDs, 9 IR LEDs, jumper wires, wire cutters
a. IR and white LEDs
i. Put together 2 sets of 4 mini breadboards following the orientation of the diagram below (Fig. 4). Ensure that the orientation of the breadboards is exactly like the figure, as the IR and white LEDs will sit on top of each other in the case.
ii. | With the wire cutters, cut the LED leads short enough that the LED
| plastic case sits flush with the breadboard surface (or no more than
| 5 mm above the breadboard surface).
iii. | Place the LEDs on the mini breadboards as shown in the figure
| below. It is important to respect the exact positioning as this ensures
| that the 3D printed pieces that cover the LED panels fit properly.
| *Make sure to orientate LEDs with correct polarity (+/-). In Fig. 4, the
| white LEDs on the left breadboard have the + pin on the left, whereas
| the IR LEDs on the right breadboard have the + pin on the right.

iv. Wire the LEDs as shown in the figure. This is the first part of the wiring and can be done with the mini breadboard panels side by side.

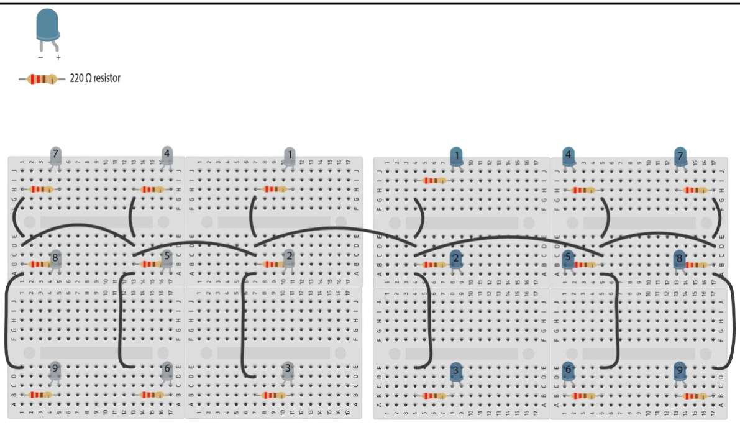
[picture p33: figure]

Figure 4. LED wiring. Here, the wiring of the white LEDs is indicated on the left, and the IR LEDs on the right. Note that these are mirror-symmetrical wirings, as these two arrays will be ‘folded’ to rest one on top of the other, with white LEDs facing upward and IR LEDs facing downward (as per Fig. 5).

v. Remove the sticker cover from the base of each mini breadboard. Stick the two panels together so that white LED 1 and IR LED 1 are aligned vertically, with white LEDs pointing up and IR LEDs pointing down (Fig. 5).

Figure 5. Orientation of white and IR LEDs. Note that, vertically, each white LED has a matching IR LED. *For simplicity, wiring is not shown here (for wiring see Fig. 4).

vi. After sticking together the white and IR LED panels, finish wiring the LEDs, add the wiring shown in green below (Fig. 6). The figure below shows the panels side by side for ease of visualization (as a result the green wiring appears to be longer than it actually is). However, the wiring should now be done with the panels on top of one another (this will help ensure stability of the wiring). Note that these wires (indicated in green below) put each white LED on the same electrical circuit as its vertically corresponding IR LED.

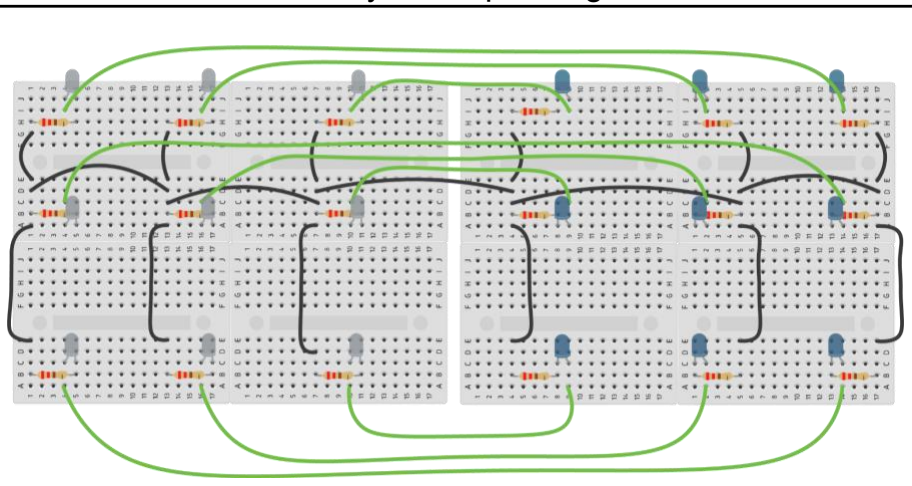
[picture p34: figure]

Figure 6. Wiring between the white and IR LED arrays (this should be done with these two arrays vertically stacked on top of one another (as in Fig. 5)).

b. Coloured LEDs (representing the output of the 2 retinal ganglion cells) Materials needed: 1 yellow LED, 1 green LED, 2 mini breadboards
i. Cut the LED pins to a length of between ~5-10 mm (this is longer than the pins for the white and IR LEDs). This is required so these LEDs fit firmly into their corresponding holes in the 3D printed case.
ii. | Place the two LEDs in one of the breadboards as shown in Fig. 7.
| Stack this mini breadboard on top of another mini breadboard. Both
| breadboards should be facing upward and can be taped together (the
| bottom breadboard only serves to prop the top breadboard higher,
| so the LEDs can fit appropriately into the 3D case.

Figure 7. Placement of colored LEDs on a mini breadboard. These LEDs will represent the outputs of retinal ganglion cell (RGC) 1 and 2.

b) CASE ASSEMBLY (~30 mins)
The case must be 3D printed before assembly (.stl files provided). It was designed in 6 separate parts to enable simple printing and easy assembly (Figs. 8 and 9).

Description of the 3D printed parts for the case:
P1 - part 1: This piece is the backbone of the case. It holds the photodiodes array, the LEDs panels, the out pins, and the GPIO interface board.
P2 - part 2: Placed on top of the photodiodes, each photodiode should fit in one of the holes of the piece.
P3 - part 3: Placed underneath the IR LED panel. Each IR LED should fit in one of the holes of the piece.
P4 - part 4: Interfaces with pieces 1-3 and provides structural support and covers the wiring that goes through the middle portion of the case.
P5 - part 5: Placed at the very top of the structure, covering the white LED panel as well as the two coloured LEDs.
P6 - part 6: Covers the C shaped opening on the side of the case. This is the last piece that should be attached. Much of the RetINaBox system testing and troubleshooting stages require P6 to be unattached.

*3D printed pieces will be referred to as P1, P2, and so on throughout the manual.
*P2 is smaller in length than P3

Figure 8. RetINaBox 3D printed pieces.

P1 | P2 | P3
P4 | P5 | P6

Figure 9. Individual RetINaBox 3D printed pieces.

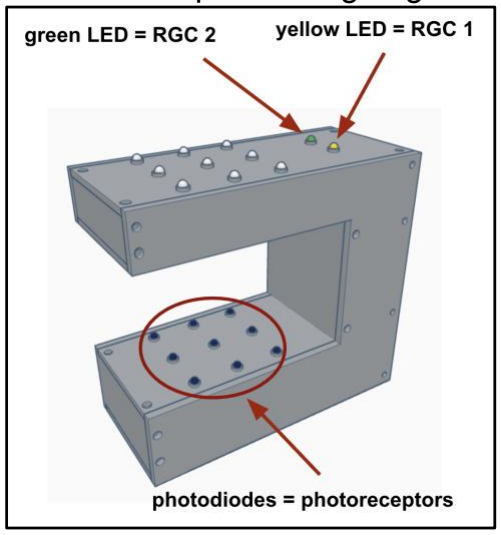
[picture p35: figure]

Here (Fig. 10) we show the case fully assembled from a couple viewing angles.

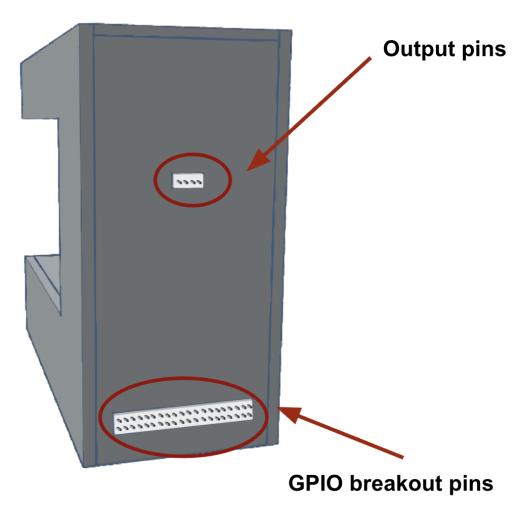
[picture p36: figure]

Figure 10. Fully assembled RetINaBox.

c) CONNECTING ELECTRONICS TO Raspberry Pi GPIO (~45 mins)

GPIO (general purpose input/output)
RetINaBox includes a GPIO interface to enable simple connectivity between RetINaBox and the Raspberry Pi with a single cable. Secure the GPIO interface board in the corresponding hole in P1 and attach it using four 6mm M2 screws (Fig. 11). *The following steps occur at the same time as Case Assembly.

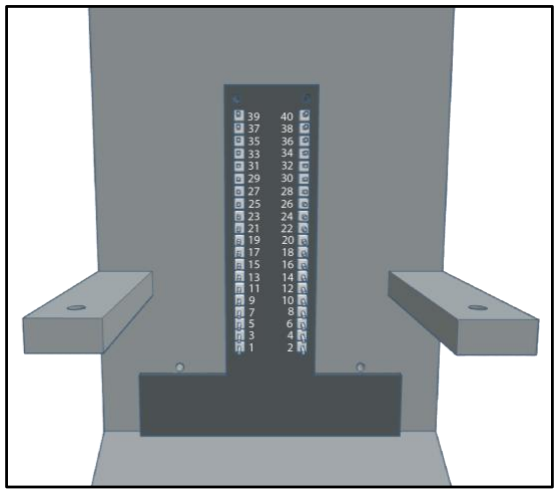
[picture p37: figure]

Figure 11. Installation of RetINaBox GPIO adapter.

While shown in more detail below in the subsequent assembly steps, here we provide the complete wiring logic for the RetINaBox electronics (Fig. 12). *All the wires going from the GPIO board to the LEDs panel should pass through a gap inside the case (Fig. 13).

Figure 12. Connections between GPIO and RetINaBox electronics.

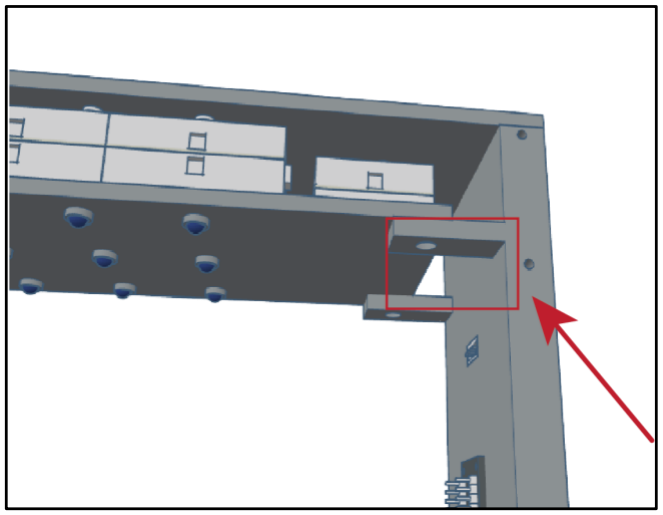
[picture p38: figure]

Fig 13. Wiring from the GPIO board to the LEDs array should pass through the internal gap in the case indicated by the red rectangle.

1. Connecting the photodiodes to the GPIO:
Materials needed: 11 female to male dupont wires, 2 x 6mm-long M3 screws
a. Place the photodiode panel on P1 as indicated in Fig 14. Do not remove the plastic cover from the bottom of the mini breadboards, the photodiode panel shouldn’t stick to P1. It will get held firmly in place by P2.

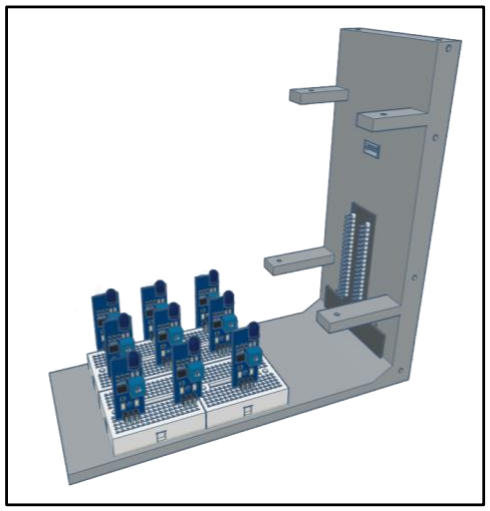
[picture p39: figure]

Figure 14. Placement of the photodiode containing breadboards onto part P1.

b. Use female-to-male dupont wires to connect the signal output pin of each photodiode to the GPIO, using connectivity instructions listed below (Fig. 15). Each number in Fig. 15 corresponds to a GPIO pin (Figs. 11 & 12).

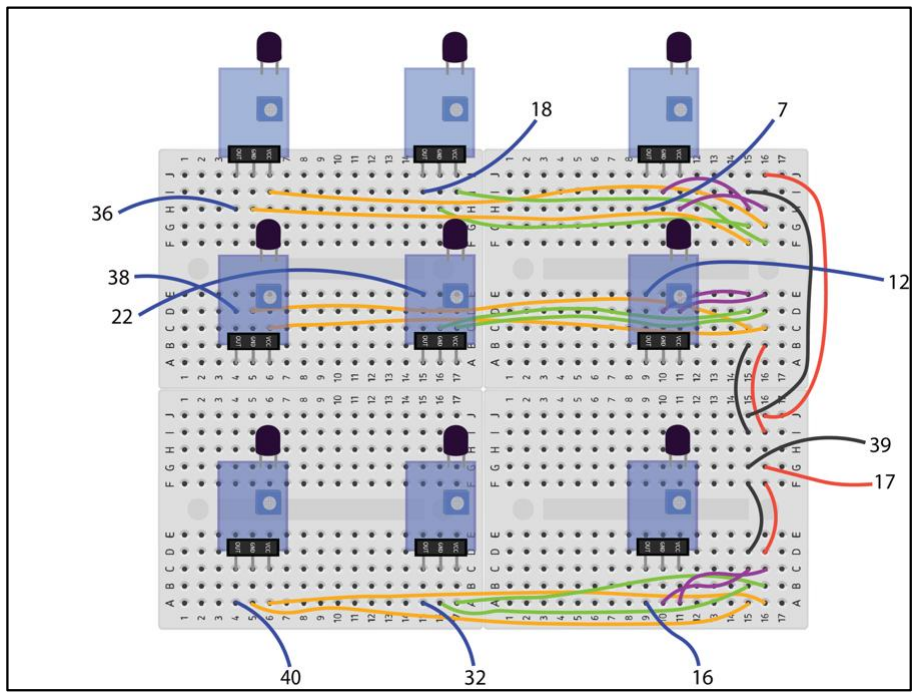
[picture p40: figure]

Figure 15. Logic for connecting photodiodes to the GPIO board.

c. Attach part P2 on top of the photodiodes. Carefully fit all 9 photodiodes into the holes in P2. Then use 2x6mm long M3 screws to secure the piece in place (Fig. 16). *Do not tighten it fully yet; P2 should be orientated with the raised LED guides (i.e. the bumps at each of the LED holes) facing up.

Figure 16. Assembly progress, with P1 and P2, the photodiodes and the GPIO interface board.

2. Connecting the 3.3V output pins (which are RGC digital outputs) to the GPIO:

Materials needed: 4 female-to-female dupont wires, 4 wires from the Connector Pre-Crimped Cable Kit (see Appendix)
a. Put together a 4-pin connector (4 pins stick out on each side) and socket from the Connector Pre-Crimped Cable Kit. This allows wires to be connected on both sides. One side should have visible pins sticking out. On the other side, the pins are covered by the socket.
b. Place it in the middle hole of P1 as shown in Fig. 17. The side that has the pins covered by the socket should face the interior of the case. *The socket should be on the inside part of the case and the pins on the outside. The socket connector should fit tightly into the hole in the case.
c. Attach wires from the kit to the 4 socket pins on the inside of the RetINaBox case (Fig. 17).
d. Daisy chain these wires with female-to-female dupont wires (use electrical tape to secure this connection) and connect to the corresponding GPIO pins (according to the logic in Fig. 17).

Figure 17. Connecting the 3.3V RGC output pins to the GPIO. Note that the socket is not shown in the connectivity cartoon.

3. Connecting the buzzer:

Materials needed: 1 mini breadboard, 10k resistor, PN2222 transistor, Elegoo active buzzer, 1 jumper wire, 3 wires from the Connector Pre-Crimped Cable Kit, 3 M-F dupont wires
a. On a mini breadboard, place the buzzer, the transistor, the 10K ohm resistor and the jumper wire as shown in Fig. 18.

Figure 18. Placement of buzzer, transistor, jumper wire between transistor and buzzer, and resistor.

b. Wire the components as shown in the Fig. 19. First connect 3 wires from the Connector Pre-Crimped Cable Kit to the corresponding output pins, then, daisy chain these wires with female-to-male dupont wires (use electrical tape to secure these connections). Note that the buzzer is connected to the GPIO breakout board through the output pins that face the back of the box (refer to Figs. 10, 12 and 17). With this circuit, the buzzer will only sound when both pin 24 and 26, which correspond to RGC1 and RGC2, send out 3.3V at the same time, which happens when RGC1 and RGC2 are co-activated.

Figure 19. Circuit wiring of the buzzer (related to Lesson Plan 2).

4. Connecting the LEDs to the GPIO board:

Materials needed: electrical wire, wire cutter, 10 female to female dupont wires, 2x 6mm-long M3 screws
a. Attach part P3 with 2 x 6mm-long M3 screws (Fig. 20). *P3 should be orientated with the raised LED guides (i.e. the bumps at each of the LED holes) facing down.

Figure 20. Attaching part P3.

b. Place breadboards containing LEDs onto P3 (Fig. 21; wiring is not shown here for ease of visualization). *Follow steps c) and d) before completing b).

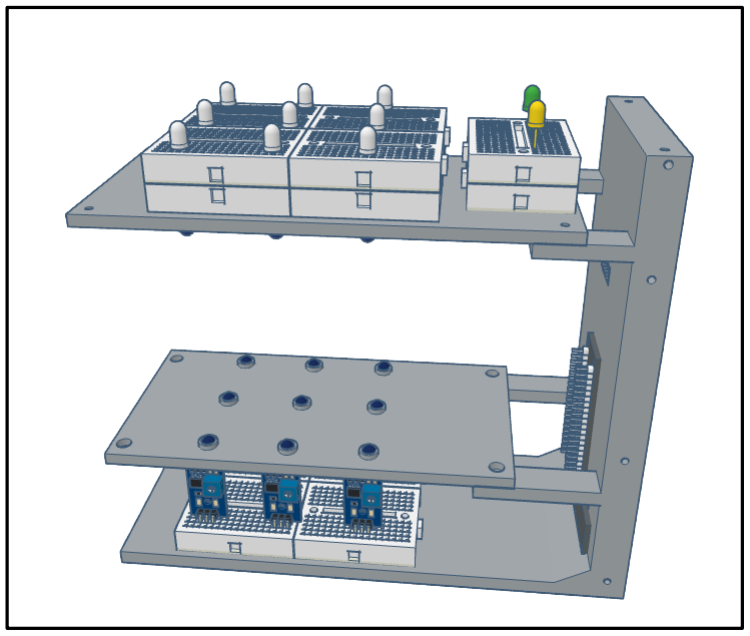
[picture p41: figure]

Figure 21. Attaching LEDs onto part P3.

c. Connect each of the 9 white+IR LED pairs to the GPIO (via the 9 orange wires (+) and black wires (-, GND; black hook-up wires) in Fig. 22. For the orange wires (orange here is for visual display—in reality, here we used the red hook-up wire), cut the electrical wire to an appropriate length (~5cm) and daisy chain it to a female-to-female dupont wire, which will then connect to the GPIO board (according to the logic in Fig. 22). *Hook-up electric wire (as opposed to Dupon wires) is used here due to the limited space between the LEDs and the 3D printed pieces that these LEDs arrays will fit between.

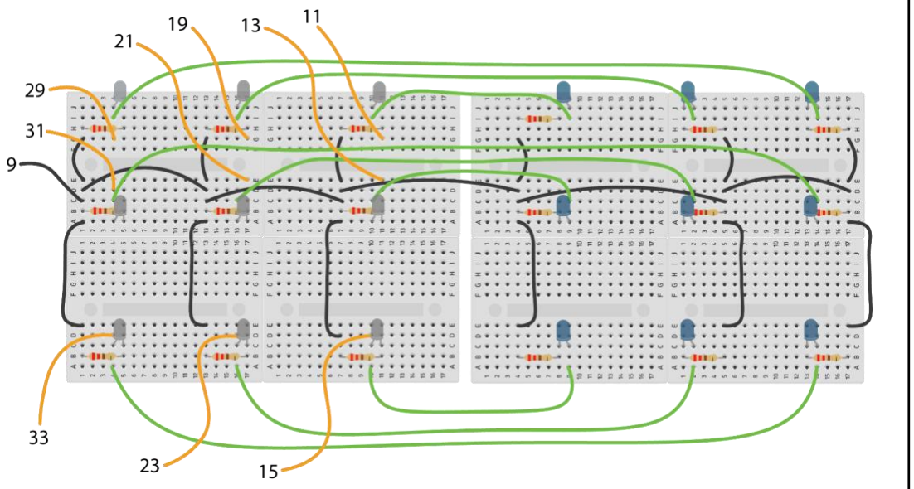
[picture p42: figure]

Figure 22. Connecting white and IR LEDs to the GPIO.

d. Connect the two color (green and yellow) LEDs, which represent the outputs of ganglion cells 1 and 2, to the GPIO, using the following logic (Fig. 23).

Figure 23. Connecting green and yellow LEDs to the GPIO.

e. Attach part P4 by connecting it to P2 and P3 (Fig. 24). This will stabilize the case and facilitate testing. Attaching parts P5 and P6, which will close up RetINaBox, but should be performed later, once RetINaBox has been connected to the Raspberry Pi and the electronics are tested and the photodiode sensitivities optimized (outlined below).

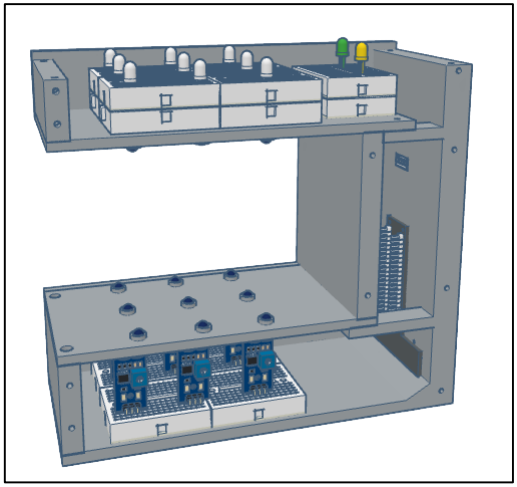
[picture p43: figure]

Figure 24. Attaching part P4.

### 3. GENERATING VISUAL STIMULI (~15 mins)

While visual stimuli can be generated directly with the Visual Stimulus Controller within RetINaBox’s GUI, to better mimic hands-on visual neuroscience experiments, users can turn all of RetINaBox’s stimulus LEDs and put real-world shapes in between RetINaBox’s LEDs and photodiodes (i.e. block out light in specific patterns) to make visual stimuli and test feature selectivity of the model RGCs. Here we provide a couple methods for generating visual stimuli to test RetINaBox with.

a) Visual Stimulus Tool

Materials Needed: clear plastic sheet, permanent marker, modeling clay, ruler (see Appendix)

To delivery various patterns of visual stimuli to RetINaBox, we recommend that users create a Visual Stimulus Tool. To do this, take the clear plastic sheet and use a fine-tipped permanent marker and a ruler to draw a grid covering the entire plastic sheet (Fig. 25). Each square in the grid should be 3 cm by 3 cm wide, roughly corresponding to the receptive field area of a single RetINaBox photodiode.

Figure 25. Visual Stimulus Tool with grids for aligning stimuli with the model photoreceptor array.

Next, place modeling clay over the plastic sheet. Leave specific regions without clay in order to make your visual stimulus (i.e. light passing/being block out of specific regions is your stimulus). You can use the clay to create differently shaped visual stimuli to present to RetINaBox (Fig. 26).

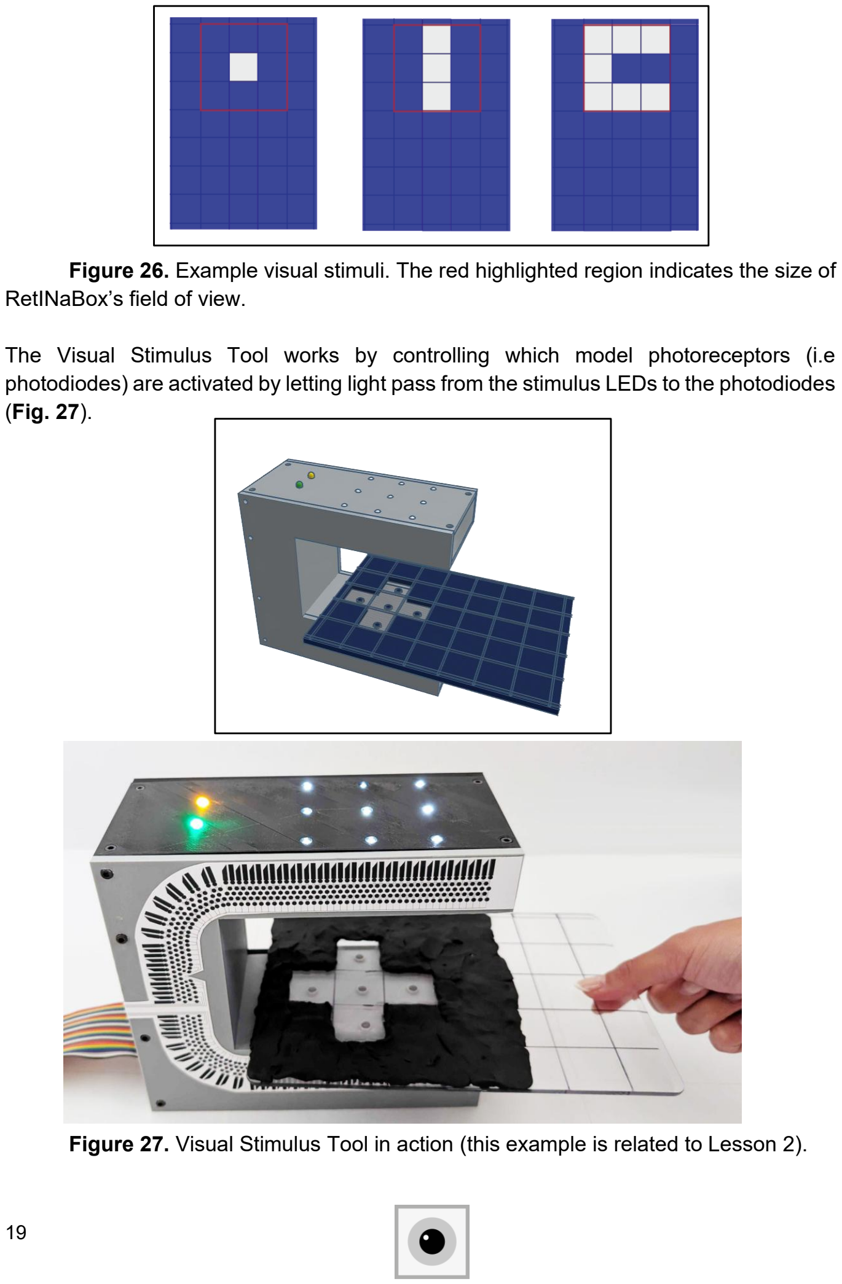
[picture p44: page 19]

Figure 26. Example visual stimuli. The red highlighted region indicates the size of RetINaBox’s field of view.

The Visual Stimulus Tool works by controlling which model photoreceptors (i.e photodiodes) are activated by letting light pass from the stimulus LEDs to the photodiodes (Fig. 27).

Figure 27. Visual Stimulus Tool in action (this example is related to Lesson 2).

b) Visual stimulation with shapes cut out of paper/cardboard

While the Visual Stimulus Tool is a great option as it allows users to make essentially any shape, in either ON or OFF versions, it can take a bit of time to switch between different stimuli. As an alternative method for more quickly testing out visual responses in RetINaBox, users can cut shapes out of paper/cardboard. To get started, users can access a PDF document containing a set of shape templates that can be printed and cutout here. (https://github.com/Trenholm-Lab/RetINaBox/blob/main/User%20Manual/RetINaBox_VisualStim_Cutouts.pdf) These shapes, as shown in Fig. 28, can be used to work through many of the lesson plan activities. Users can also generate other shapes as they see fit.

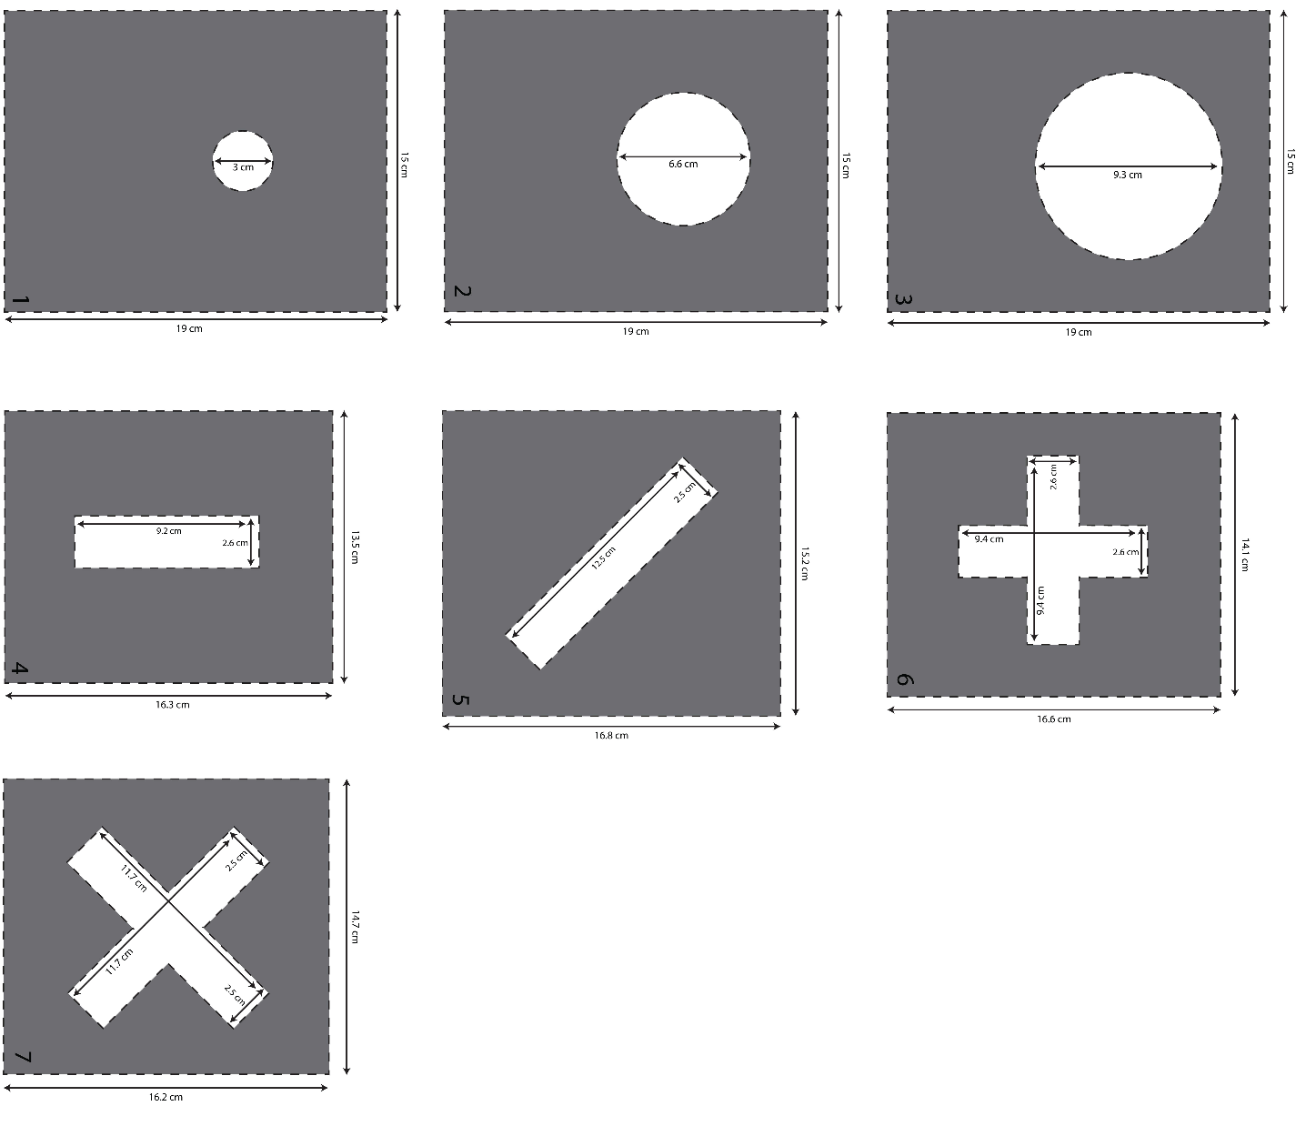
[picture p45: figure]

Figure 28. Visual stimulus shapes that can be printed and cutout from paper/cardboard.

### 4. INSTALLING THE SOFTWARE (~5 mins)

a. On your Raspberry Pi, use the Web Browser to access the Trenholm Lab RetINaBox GitHub page: https://github.com/Trenholm-Lab/RetINaBox. *We recommend using a Raspberry Pi 500 (or Raspberry Pi 5). We tested the software on a Pi 400, and though it works, it is a bit laggy.
b. Download the repository ZIP by clicking on the green ‘Code’ button, then the ‘Download ZIP’ button (Fig. 29). Once downloaded, the ZIP file will appear in your downloads folder as RetINaBox-main.zip.

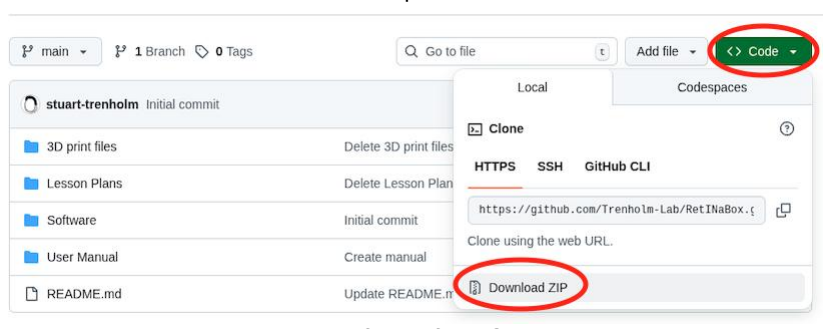
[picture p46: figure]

Figure 29. Downloading RetINaBox software from GitHub.

c. Unzip the code files to your device by right-clicking on the RetINaBox-main.zip file and selecting ‘Extract To…’. Select your Desktop as the ‘Extract to:’ save path and leave all other options untouched as outlined below in Fig. 30. After this step, your Desktop will now contain a folder titled RetINaBox-main. Do not modify or move this folder. You can now close the File Manager.

Figure 30. Raspberry Pi Extract Files Menu.

d. Open the terminal and type the following commands followed by the enter key as shown in Fig. 31.
cd Desktop/RetINaBox-main/Software/RetINaBox chmod +x install_RetINaBox.py
python3 install_RetINaBox.py

Figure 31. Terminal during RetINaBox code installation.

e. Following the successful installation of RetINaBox, you will see a new app on your Desktop. To access the GUI, double click on the new RetINaBox Desktop app and click on Execute (Fig. 32). Welcome to the RetINaBox Lab!
i. Should installation not be successful, please refer to the User Manual section A2: Appendix 2: Troubleshooting.

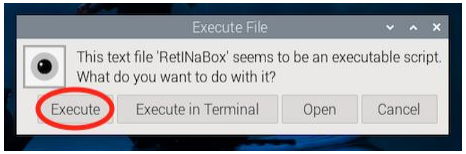
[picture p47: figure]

Figure 32. RetINaBox Execute File Message.

### 5. CONNECTING RetINaBox TO THE Raspberry Pi

a. Connect RetINaBox to the Raspberry Pi using the GPIO rainbow connection cable. IMPORTANT: the grey connectors at both ends of the rainbow cable have a small raised plastic notch on one side of the connector’s horizontal axis - it is very important to connect these appropriately to the RetINaBox and Raspberry Pi, otherwise the connections between RetINaBox and Raspberry Pi will be incorrect and the Raspberry Pi or electronic elements could get burned out! The sockets in both the RetINaBox and Raspberry Pi have little notches cut out, indicating the proper orientation that the rainbow connection cable should be attached!
b. Connect the Raspberry Pi to power (i.e. plug in the Raspberry Pi). We recommend using an extender cable for the rainbow connection cable, which doubles its length and makes it easier to orient the RetINaBox next to the Raspberry Pi 500.
c. If the photodiodes have been connected correctly, the right-most red LED on each of their circuit boards should light up (Fig. 33), indicating they are receiving power.

Figure 33. Powering ON the Raspberry Pi should result in power going to all 9 photodiodes, which should turn on the right-most red LED on each photodiode circuit board.

d. The next step is to adjust the sensitivity of the IR photodiodes such that they are only activated when the IR LEDs are turned on. First, take a small screwdriver, and for each photodiode turn the potentiometer in a clockwise manner until the leftmost LED lights up (Fig. 34). Then turn the potentiometer roughly a half turn back counterclockwise so that the leftmost LED turns off. Next, open the RetINaBox software (see Section 6 below) and turn on all 9 LEDs. If the LEDs have been connected correctly, the 9 white LEDs on the top of RetINaBox should now light up (visible by eye), and the 9 IR LEDs should also light up, but not be visible by eye. Turning the LEDs on should activate the photodiodes and turn on the leftmost LED on each photodiode. If this doesn’t happen, adjust the photodiode sensitivity with the potentiometer until the leftmost red LED only turns on when the IR LED directly above that photodiode is turned on (Fig. 34). If you a potentiometer is powered but you are unable to activate by turning on the LEDs, likely the IR LED is not correctly wired (see Troubleshooting section).

Figure 34. Adjust the sensitivity of the IR photodiode by dialing the potentiometer back and forth until the leftmost red LED on the circuit board only turns on when the IR LEDs are turned on the RetINaBox software.

e. Attach parts P5 and P6 (Fig. 35). You have now finished building RetINaBox!

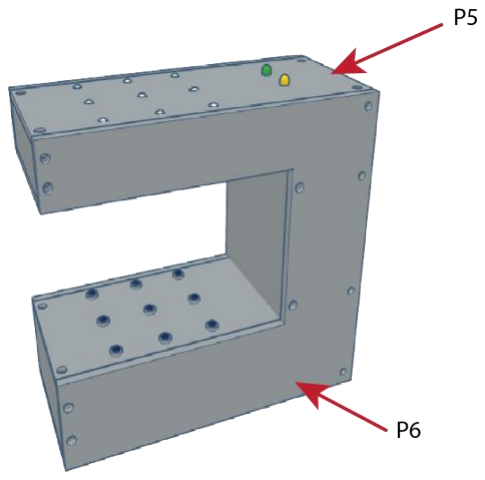
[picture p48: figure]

Figure 35. Completed RetINaBox

### 6. USING THE SOFTWARE

a. Double click on the “RetINaBox” logo on the desktop, or in Visual Studio Code, run the file “main.py”
b. This will open the welcome screen (Fig. 36). Select “Enter the Lab” to start working with RetINaBox. You can also access the user manual and lesson plans.

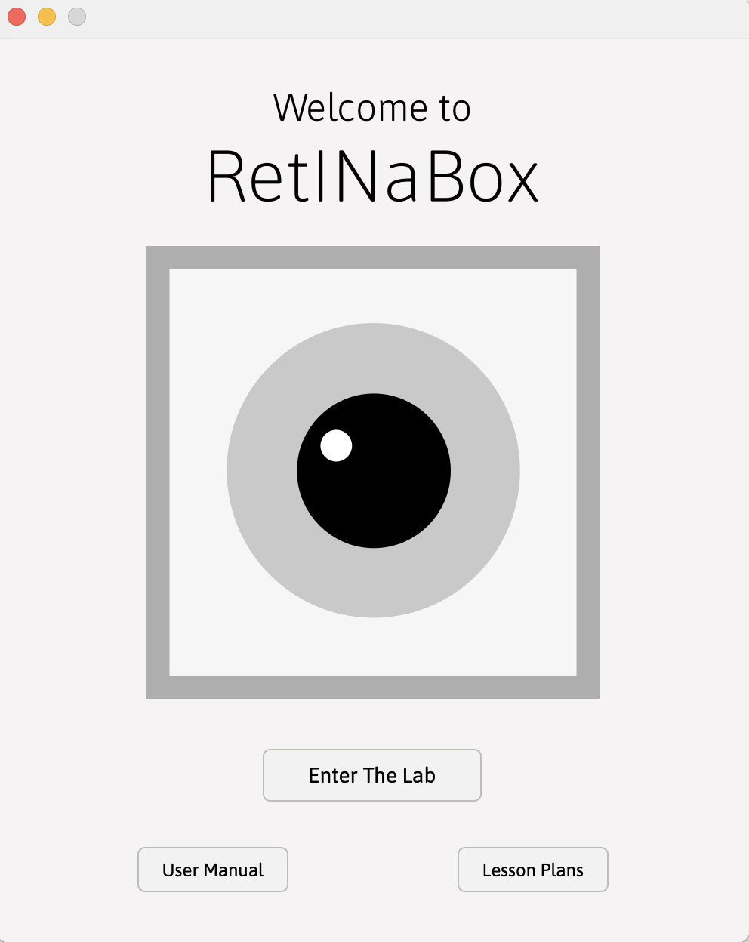
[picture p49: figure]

Figure 36. RetINaBox welcome screen.

c. You will now see the main RetINaBox graphical user interface (GUI; Fig. 37). The software contains 4 menu items (the GUI can be maximized to full screen):
i. User Manual: Opens a PDF of the user manual
ii. | Lessons: Here you can access the lesson plans. Also, for each of the 4
| lessons you will find preset RetINaBox settings, and lesson-specific
| challenges.
iii. | Save: Click this to save your current RetINaBox settings.
iv. | Open: Click here to open previously saved RetINaBox settings.

The RetINaBox GUI is split into 3 sections (we’ll go into each of these in more detail next):
| Visual Stimulus Controller: This is where you control RetINaBox’s stimulus
| LEDs
| Connectivity Manager: This is where you control the connectivity of the
| model photoreceptors to the model ganglion cells.
| Signal Monitor: This shows you when photoreceptors are active, what signal
| they’re passing to the ganglion cells, and when the ganglion cells are active.

Figure 37. The main RetINaBox graphical user interface.

d. Visual Stimulus Controller (Fig. 38).
i. At the top, you’ll see the 3 x 3 LED array. Before turning on the LEDs, you’ll need to activate (by clicking on them) the LEDs you want to turn on. This will turn them grey in the display. There are also “Select all” and “Clear all” buttons.
ii. | Next, you can decide if you want to present a static (still) stimulus, or if you
| want it to move leftward or rightward. To start with, leave it in Static mode
iii. | Now, click the ON/OFF button. You’ll see in the display that the LEDs you
| selected are now active (i.e. yellow). If you’re connected to the RetINaBox,
| you’ll also see the LEDs you selected turn on. The LED numbering in the
| software corresponds to when you’re directly looking at the front of
| RetINaBox.
iv. | Related to the direction selectivity lesson (lesson 3), you may wish to have
| your visual stimuli move leftward or rightward. To do this, simply activate a
| pattern of LEDs (you’ll have to turn on the LEDs before changing which
| ones are active), select Motion mode, select direction (left or right arrow),
| and select speed (slow, medium, or fast).
v. Lastly, for all the lessons in the lesson plan, at some point you’ll want to test
| real-world stimuli, using the Stimulus Presenter Tool, the paper cutouts, or
| your hands. To do this, activate all 9 LEDs, select Static Mode, and turn the
| LEDs on.

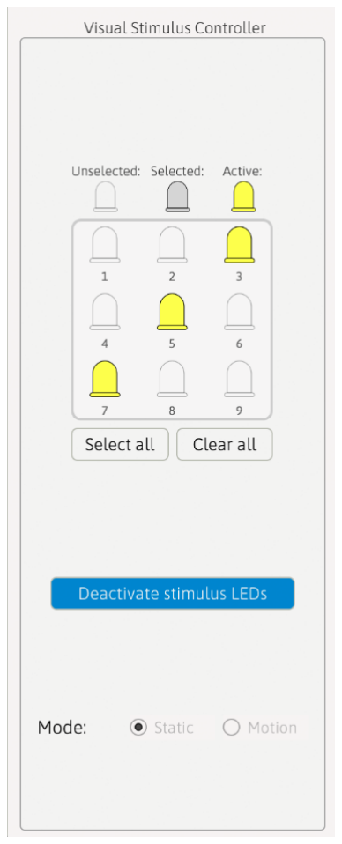
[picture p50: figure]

Figure 38. The Visual Stimulus Controller.

e. Connectivity Manager (Fig. 39).
i. The Connectivity Manager allows users to set the connectivity between each of the 9 model photoreceptors (i.e. the photodiodes) and 2 different model retinal ganglion cells (RGCs).
ii. Independently for each of the 2 RGCs, each photoreceptor can be set as:
1. Silent: it provides no signal to the ganglion cell
2. Excitatory: when activated, this photoreceptor provides a signal of +1 to the
| ganglion cell
3. Inhibitory: when activated, this photoreceptor provides a signal of -1 to the
| ganglion cell
4. Delay: you can add a time delay between when the photoreceptor is activated
| and when it sends a signal to the ganglion cell. The delay options are: none,
| short, medium, and long. These delays can be helpful for generating direction
| selective responses and are meant to help model temporally asymmetric circuit
| connectivity.
iii. | To change the connectivity to one of the ganglion cells, simply click on its circuit
| (Fig. 39, left). This will open a pop-up window (Fig. 39, right) where you can
| change the settings for each model photoreceptor.
iv. | Set the RGC’s Threshold. At each point in the time, the RGC will sum up all its
| photoreceptor inputs, and it needs to meet this threshold to become activated.
v. Set the RGC Type as ON or OFF. For ON RGCs, photoreceptors are
| considered activated when the photodiode detects light. For OFF RGCs,
| photoreceptors are considered activated when the photodiode does not detect
| light.

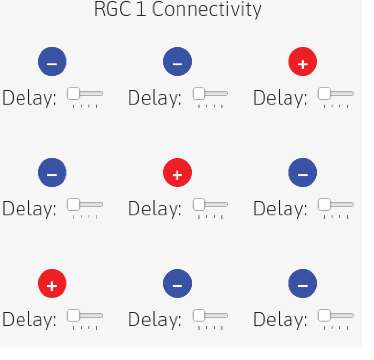
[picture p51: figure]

Figure 39. Connectivity Manager in main GUI (left) and its pop-up window (right).

f. Signal Monitor (Fig. 40).
i. The Signal Monitor provides a real-time readout of:
1. Which model photoreceptors (photodiodes) are detecting light. This can be seen when the circles on the right-hand side turn yellow.
2. The polarity of the signal being sent, either excitatory (red) or inhibitory (blue), by each activated model photoreceptor to each retinal ganglion cell.
3. When each ganglion cell (RGC1, top; RGC2, bottom) is activated. This occurs when the sum of all its photoreceptor inputs meets or exceeds the threshold set in the Connectivity Manager.

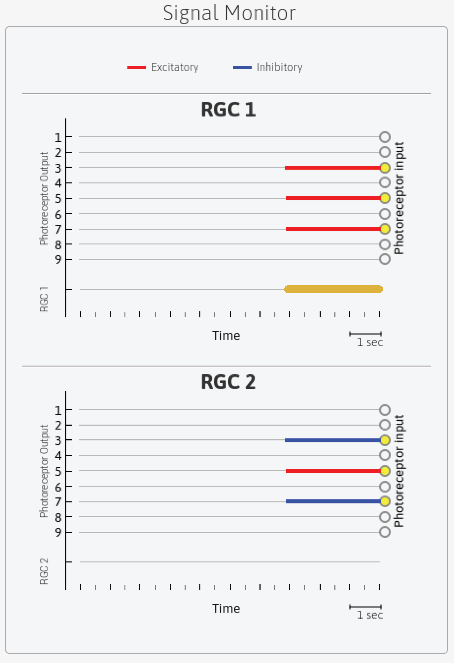
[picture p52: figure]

Figure 40. The Signal Monitor.

g. Additional software features
i. Code breaking activity:
1. In Lesson 2, users are tasked with using center-surround receptive fields to crack codes. Accessed via the Lessons tab in the menu bar (Lessons > Lesson 2 > Code Breaker), selecting the Code Breaker activity will load a new tab (Fig. 41).
2. Using cipher information, users must toggle back to the main RetINaBox GUI and set the Connectivity Manager so that RGC1 and RGC2 exhibit preferred visual stimuli as outlined in the cipher (while ensuring that RGC1 and RGC2 can be co-activated).
3. Next, users should use the Visual Stimulus Tool to present stimuli corresponding to each of the letters in the code, and, referencing the decoder in the cipher, enter the correct letter in the codebreaker for each stimulus code.
4. Once users have solved the code, they can check their answer.

Figure 41. Code breaking activity related to Lesson 2.

ii. Block breaker video game:
1. In Lesson 3, after generating direction selective ganglion cells
| selective for leftward and rightward motion, users are instructed to open the block breaker game (accessed via the Lessons tab in the menu bar). This will open the game (Fig. 42). Opening the game automatically turns on all the stimulus LEDs on RetINaBox.
2. The game is programmed to take the RetINaBox output from RGC1
| to move the game paddle to the left, and the RetINaBox output from RGC2 to move the game paddle to the right
3. Users then sweep their hand across RetINaBox’s field of view,
| leftward and rightward, to move the paddle and play the game.

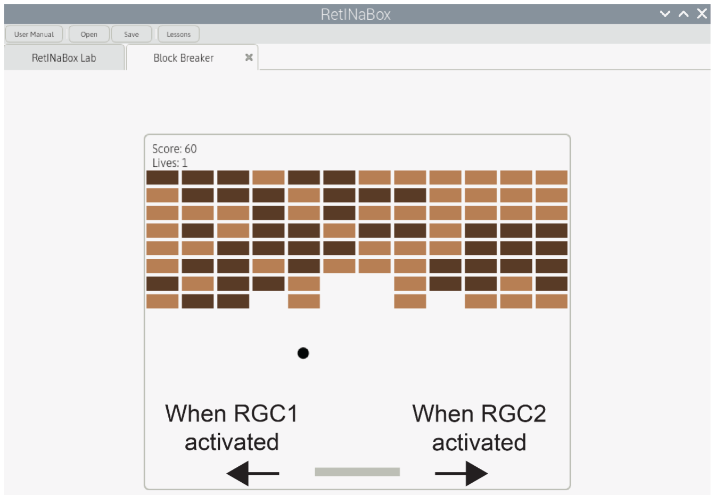
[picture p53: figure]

Figure 42. Brick breaker game related to Lesson 3.

iii. Discovery Mode:
1. Lesson 4 is Discovery Mode, which can be accessed via the Lessons
| tab in the menu bar. It opens the Discovery Mode tab (Fig. 43). Opening Discovery mode automatically turns on all the stimulus LEDs on RetINaBox.
2. Next, users select a Challenge from the menu.
3. In Phase 1, users use the Visual Stimulus Tool, or their paper
| cutouts, or their hand, to present various static and moving stimuli to RetINaBox until they are able to activate RGC1.
4. Once users find the preferred visual stimulus for a given challenge,
| they enter the solution into the left-hand side of the software (Phase
1) and select ‘Test Stimulus.’ If they are correct, they move onto
| Phase 2.
5. In Phase 2, users set the connectivity between model photoreceptors
| and the model RGC in order to recreate the visual stimulus selectivity they discovered in Phase 1. Once the user is confident in their solution, the click ‘Test Connectivity.’

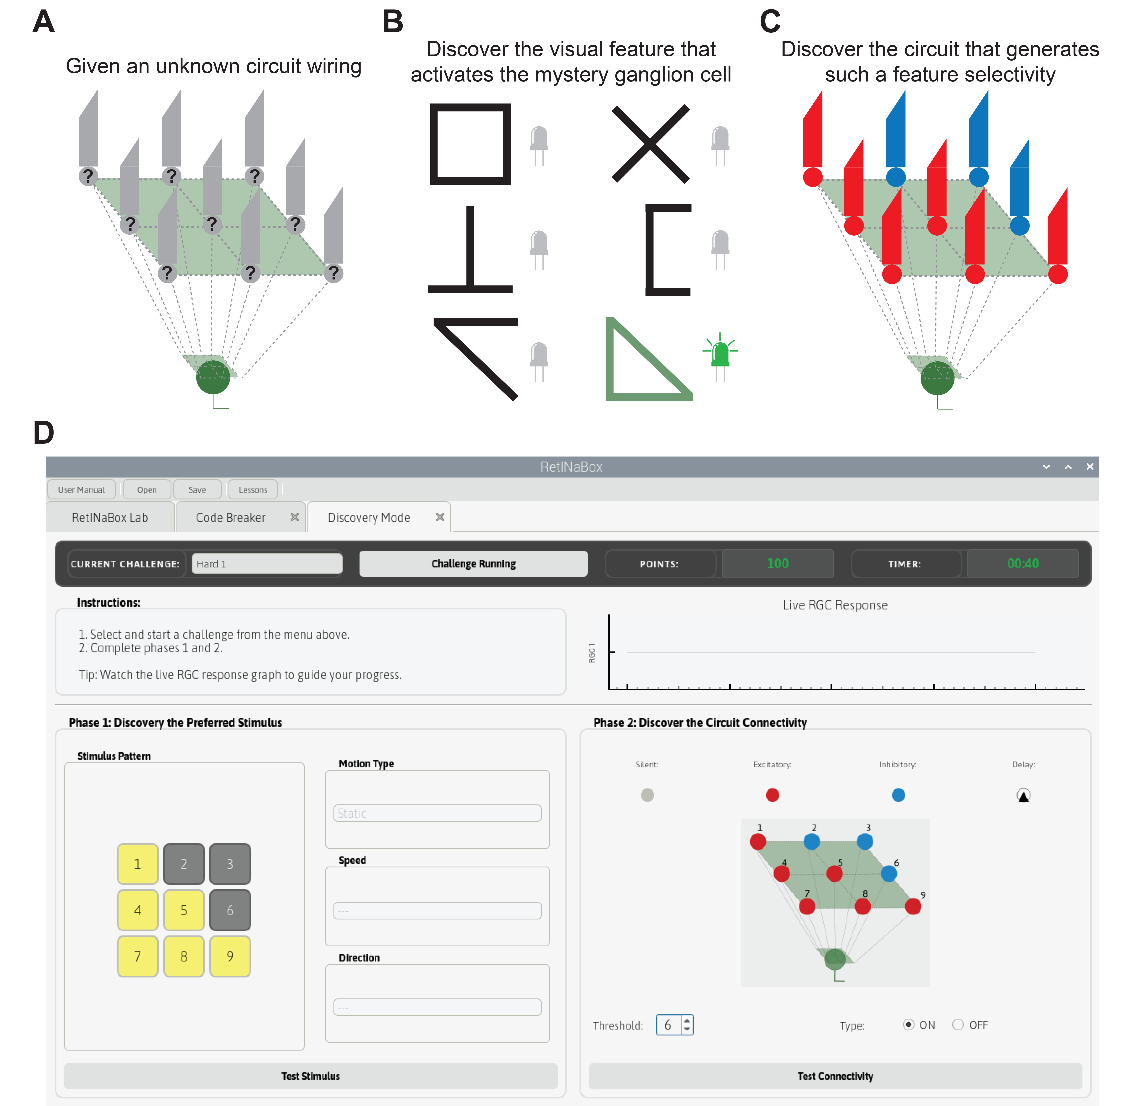
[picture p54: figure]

Figure 43 Discovery Mode graphical user interface.

Category | # | Product | Specifications | Supplier | Notes
RetINaBox | 6 | Case | 3D printed pieces (link) (https://drive.google.com/drive/folders/1DmUhCU8-99DyLmYc_d9g1IFadtFvgH2a?usp=sharing)
| 26 | M3 screws 6mm
| 4 | M2 screws 6mm | | | Used to secure GPIO board to the case
| 9 | 5mm IR LED | 100 mA continuous, 1000 mA pulse Approx 1.6V forward voltage | Adafruit 387 (https://www.adafruit.com/product/387)
| 9 | IR Photodiodes | | Amazon (https://www.amazon.ca/HiLetgo-Infrared-Avoidance-Reflective-Photoelectric/dp/B07W97H2WS)
| 1 | Elegoo electronics kit | Things you’ll need from here: 9 white LEDs, 1 green LED, 1 yellow LED, resistors | Amazon (https://a.co/d/1njj6g7)
| 12 | Mini Breadboard | | Amazon (https://a.co/d/6qQtx3f)
| 26 | Dupont Wires | | Amazon (https://a.co/d/4TvdGkJ)
| | Jumper wires kit | | Amazon (https://a.co/d/fxJ6lkD)
| 1 | GPIO Breakout Kit for Raspberry Pi | | Amazon (https://a.co/d/4zZ2Pfc)
| 1 | Rainbow connection extender | Optional – adding an extra cable or two lets you orient RetINaBox more freely next to the Raspberry Pi | Amazon (https://www.amazon.ca/Jumper-Computer-Accessories-Breadboard-Ribbon/dp/B0DQJTR131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)
| 1 | elechawk PH 2.0 Connector Pre-Crimped Cable Kit | | Amazon (https://a.co/d/gQgTWbW)
| 1 | Roll of electrical tape

A1- APPENDIX 1: COMPONENTS LIST

Category | # | Product | Specifications | Supplier | Notes
| 1 | Red electrical hook-up wire | | Digikey (https://www.digikey.ca/en/products/detail/alpha-wire/3051-1-RD005/281577) | If you have some lying around, great. If not, order something like this, but it need not be exactly this product
| 1 | Black electrical hook-up wire | | Digikey (https://www.digikey.ca/en/products/detail/alpha-wire/3051-1-BK005/281576) | Same note as above
For testing IR LEDs | 1 | 3.3V USB to Serial Adapter | Optional | Amazon (https://www.amazon.ca/dp/B08G1JNSWV?previewDohEventScheduleTesting=C) | You can use this to power an IR photodiode and test the IR LEDs independently of the rest of RetINaBox
Visual Stimulus Tool | Set of 2 | Clear plastic sheet (15.4x 22.4cm) | | Amazon (https://www.amazon.ca/BAOFALI-Standard-Cutting-Machine%EF%BC%9BClear-Polycarbonate/dp/B0C5QGRGJN) | Put the playdough on this and then stick it in between RetINaBox’s IR LEDs and photodiodes
| 1 | Thin-tipped sharpie | Any thin tipped permanent marker should do | | To draw a grid on the Visual Stimulus Tool to guide where to place the modeling clay
| 1 | Modeling clay | Any brand should do, including play dough | | You need enough to thinly cover the Visual Stimulus Tool
Tools | 1 | 2.5mm hex key | | | Used with M3 screws
| 1 | 1.5mm hex key | | | Used with M2 screws
| 1 | Wire stripper/cutter
| 1 | Mini screwdriver | | | For adjusting the photodiode sensitivity

A2- APPENDIX 2: TROUBLESHOOTING

3D printing related:

a. The photodiodes and LEDs don’t fit properly fit into holes in the 3D printed parts meant for them to pass through
i. We recommend printing parts P2, P3 or P5 first, and checking that the LEDs/photodiodes fit snugly into the holes. If not, the pieces should be scaled a couple % in size up or down based on how your printer generates these pieces. Then, all other printed parts should be scaled by the same factor.

Photodiode related:

a. The photodiode power light (right-most LED on the circuit board) does not turn on when RetINaBox is connected to the Raspberry Pi and the Raspberry Pi is turned on.
i. Check the wiring between the RetINaBox GPIO connector and the photodiode. A multimeter can be handy here.
ii. | Check that you’ve properly connected the rainbow connection cable.
iii. | You can check that the Raspberry Pi is correctly sending out power to the
| LEDs. First, disconnect the rainbow connection cable. Next, connect a
| spare visible light LED onto a spare mini breadboard. Take a female-to-
| male dupont cable and connect GPIO pin 17 (which normally provides 3.3V
| to power the photodiodes) and connect it to the LED’s (+) lead. Next, take
| another female-to-male dupont cable and connect GPIO pin 39 (which
| normally provides the (-)/GND to the photodiodes) to the LED’s (-) lead. If
| the LED lights up when you turn it on with the RetINaBox GUI, then the
| Raspberry Pi is sending out power, and the issue is with your wiring. If this
| doesn’t work, you may have somehow burned this pin in your Raspberry Pi.
b. The photodiode is powered, but it doesn’t get activated (i.e. its leftmost red LED on its circuit board does not turn on) when the IR LEDs are turned on, or it doesn’t get deactivated (i.e. its leftmost red LED on its circuit board does not turn off) when the IR LEDs are turned off.
i. The photodiode’s sensitivity is not properly adjusted. Remove part P6.
| Using the RetINaBox software, turn on the LED directly above the
| photodiode you’re having an issue with. Adjust that photodiode’s
| potentiometer (see Fig. 34) with a screwdriver until the leftmost red LED on

its circuit board turns ON when the LED is ON, and also turns OFF when the LED is turned OFF.
ii. | If step 1 doesn’t work, there are two other possible issues. First, it could be
| that the IR LED is not wired correctly. To check this, go to the section below
| titled “LED related.” Second, it could be that the photodiode and its
| correspond LED are not properly aligned in the 3D printed case. To the best
| of your ability, each photodiode should point directly at its corresponding IR
| LED, and each IR LED should point directly at its corresponding photodiode
| (the LEDs have relatively narrow angle output, and the photodiodes are
| most sensitive to light pointing directly at them.

LED related:

a. One of the white LEDs does not turn on when it’s activated in the software
i. Check your wiring (and the polarity of your LED)!
ii. | Try replacing the LED.
iii. | Similar to step a-iii in the “Photodiode related” section above, you can
| directly check that the Raspberry Pi is sending the correct signal. Check
| with Figs 12 and 22 to check which GPIO pins correspond to the LED that
| is not working correctly. Take a female-to-male dupont cable and connect
| the GPIO pin that provides power to the problematic LED (which normally
| provides 3.3V to power that LED when the software activates it) and
| connect it to the breadboard LED’s (+) lead. Next, take another female-to-
| male dupont cable and connect GPIO pin 9 (which normally provides the (-
| )/GND to the photodiodes) to the breadboard LED’s (-) lead. If the LED lights
| up when you activate this LED in the RetINaBox GUI then the Raspberry Pi
| is sending out power appropriately, and the issue is with your wiring. If this
| doesn’t work, you may have somehow burned this pin in your Raspberry Pi.
b. One of the IR LEDs does not turn on when it’s activated in the software
i. Check your wiring (and the polarity of your LED)!
ii. | Try replacing the LED.
iii. | Follow the same instructions as outlined in the “LED related” section a-iii.
| Since you cannot see whether the IR LED is active with your eye, you can
| either use the corresponding photodiode in RetINaBox as your readout, or
| you can connect the USB to TTL serial adapter (see recommend
| components list) to a spare photodiode, and use this photodiode to test for
| activation of the IR LED.
c. One of the color LEDs (green or yellow) does not turn on when the software is running and the corresponding retinal ganglion cell is activated in the GUI’s Signal Monitor.

i. Check your wiring (and the polarity of your LED)!
ii. | Try replacing the LED.
iii. | Follow the same instructions as outlined in the “LED related” section a-iii,
| but for the GPIO pins powering these two LEDs (Figs. 12 and 22).
d. For a connected pair of white and IR LEDs, only one of them is active (i.e. they are getting powered, but only one of them is active).
i. Check your wiring (and the polarity of your LED)!
ii. | Try replacing the LED that isn’t working.
iii. | Make sure you have the correct resistors in place (this is important, since
| the different types of LEDs have different forward voltage (and likely
| different internal resistance as well), so to ensure both LEDs are activated
| by the same power source we need to use resistors to standardize current
| flow through both IR and white LEDs).
e. LEDs are flickering
i. Check your wiring - most likely it’s a loose connection.

Software installation related:

a. The code does not run when the RetINaBox app is clicked and ‘Execute’ is selected. See troubleshooting suggestions here. (https://github.com/Trenholm-Lab/RetINaBox/blob/main/Software/RetINaBox/README.md)

A3: Appendix 3: Costs

Part | Price (CAD) | Price (USD)
| piece 1 (130g) | 4.03 | 2.86
| piece 2 (136g) | 4.21 | 2.99
| piece 3 (80g) | 2.48 | 1.76
| piece 4 (38g) | 1.18 | 0.83
| piece 5 (48g) | 1.49 | 1.06
| piece 6 (41g) | 1.27 | 0.90
GPIO Breakout Kit for Raspberry Pi | | 18.00 | 12.78
Jumper wires kit | | 18.99 | 13.48
Dupont Wires | | 12.99 | 9.22
Mini Breadboards | | 12.99 | 9.22
Photodiodes | | 15.99 | 11.35
Raspberry Pi 500 | | 169.95 | 120.66
Screen YODOIT | | 89.99 | 63.89
M3 screws | | 11.65 | 8.27
M2 screws | | 18.99 | 13.48
ELEGOO kit | | 21.99 | 15.61
Pre-Crimped Cable Kit Compatible | | 20.99 | 14.90
IR LEDs | | 8.40 | 5.96
Plastic sheet | | 15.99 | 11.35
Play doh | | 3.00 | 2.13
3.3V USB to TTL Serial Adapter | | 15.99 | 11.35
Total | | 470.55 | 334.096

3D printed pieces (cost estimate)

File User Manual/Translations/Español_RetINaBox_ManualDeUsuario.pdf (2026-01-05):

## Manual de usuario de RetINaBox

## Instrucciones para la instalación del hardware y la configuración del software

Versión 1.2

## Tabla de contenidos

1. Introducción
2. Ensamblaje de RetINaBox
3. Armado de la Herramienta de Estímulo
4. Instalación del Software
5. Conección de RetINaBox al Raspberry Pi
6. Uso del Software

A1: Anexo 1: Lista de componentes
A2: Anexo 2: Resolución de problemas A3: Anexo 3: Costos

### 1. INTRODUCCIÓN

¡Bienvenido al manual de usuario de RetINaBox! Aquí encontrará instrucciones detalladas para la construcción y el montaje de RetINaBox, así como para la instalación y el uso del software. Además, le proporcionamos una lista completa de los componentes necesarios. Si no tiene experiencia en electrónica, no se preocupe: no necesitará soldar nada. Para quienes sí tengan conocimientos básicos de electrónica, el diseño de RetINaBox es bastante sencillo y, siempre que sean compatibles con Raspberry Pi, podrá utilizar otros componentes electrónicos, como LEDs, fotodiodos y resistencias, distintos a los especificados aquí. Finalmente, incluimos una sección de resolución de problemas por si, tras leer el manual, el dispositivo aún no funciona correctamente.

### 2. ENSAMBLAJE DE RetINaBox

RetINaBox está compuesto por una carcasa impresa en 3D que alberga LEDs, fotodiodos y los cables que conectan estos componentes a la Raspberry Pi. La carcasa consta de seis piezas impresas en 3D que se ensamblan mediante tornillos M3 de diferentes longitudes (como se describe a continuación). Si bien el orden de montaje no es estricto, seguir el orden indicado en este manual garantiza un montaje sencillo y eficiente. También se describirá el cableado de los diferentes componentes, que se integrarán en la carcasa durante el proceso de montaje. Antes de comenzar, se recomienda tener a mano todos los componentes y las herramientas necesarias. Los pasos para el montaje son los siguientes:

a) Cableado
- Cableado de los fotodiodos
- Cableado de los paneles LED
- Paneles LED infrarrojos
- Paneles LED blancos
- Paneles LED de colores
b) Montaje de la carcasa
- Descripción de las piezas de la carcasa impresas en 3D
- Partes principales de RetINaBox c) Conexión electrónicas al GPIO de Raspberry Pi
- Conexión de los fotodiodos al GPIO
- Conexión de los pines de salida de 3,3 V al GPIO
- Conexión del buzzer o parlante zumbador (para la lección 2)
- Conexión de los paneles LED al GPIO
- Panel LED blanco
- Panel LED de colores
a) CABLEADO
1. Cableado de los fotodiodos (~30 min)
Materiales necesarios: 9 fotodiodos infrarrojos (IR), cables de conexión, cortador de alambre.
a. Tenga 9 fotodiodos a la mano. Retire o doble hacia atrás el LED transparente de cada fotodiodo (Fig. 1; estos LEDs no se utilizarán en RetINaBox). Los fotodiodos se alimentarán con un voltaje constante de 3,3 V proveniente de la computadora Raspberry Pi, la cual también leerá de forma independiente la señal de salida de cada fotodiodo (es decir, si el fotodiodo está detectando luz o no). Cada placa del fotodiodo incluye un potenciómetro, que se utilizará para ajustar la sensibilidad a la luz (como se describe a continuación).

Figura 1. Fotodiodos infrarrojos (IR).

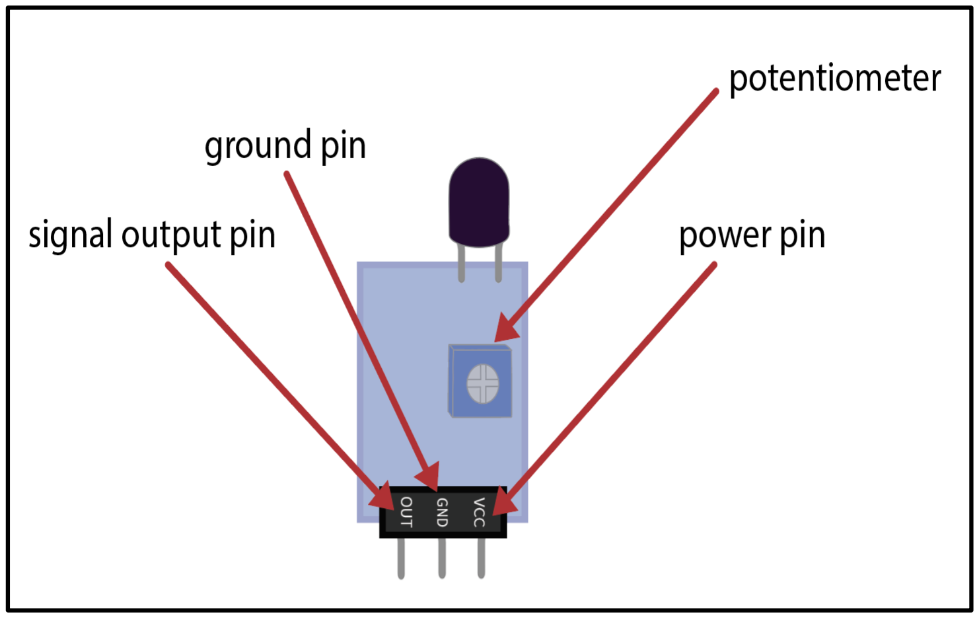
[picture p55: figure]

b. Coloca 4 mini tableros de circuitos siguiendo la orientación del diagrama a continuación (Fig. 2).

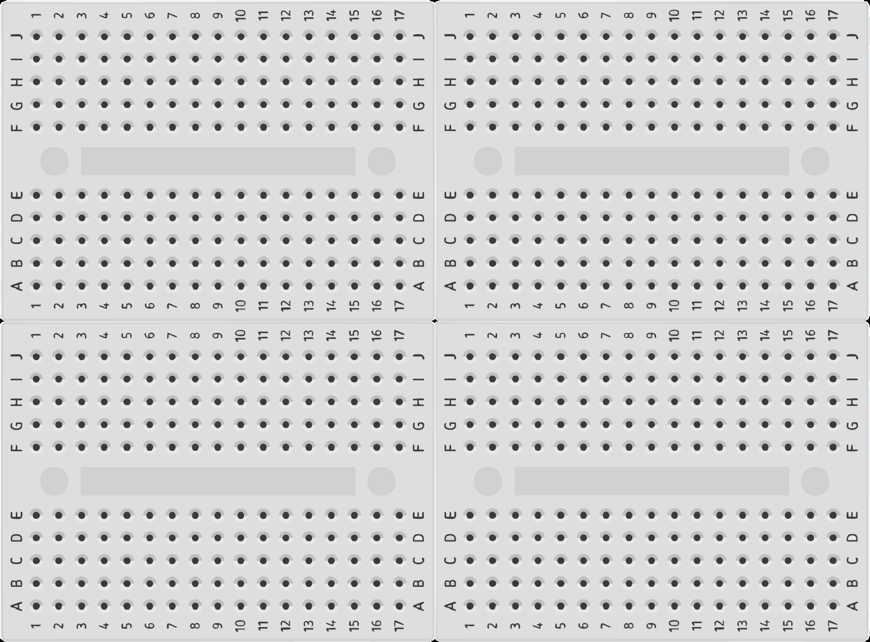
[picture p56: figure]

Figura 2. 4 mini tableros de circuitos

c. Coloque los fotodiodos en los tableros de circuitos como se muestra en la figura siguiente (Fig.3). Es importante respetar la posición exacta, ya que esto garantiza que los fotodiodos encajen correctamente en la carcasa impresa en 3D. *En el caso de la fila central, puede resultar más sencillo colocar primero los cables y luego los fotodiodos.

Figura 3: Colocación de los fotodiodos y cableado local en los tableros de circuitos.

2. Cableado de los paneles LED (~90 mins)
Materiales necesarios: 9 LEDs blancos, 9 LEDs infrarrojos, cables de conexión, cortador de alambre
a. LEDS infrarrojos y blancos
i. Coloque dos conjuntos de 4 mini tableros de circuitos, siguiendo la orientación del diagrama (Fig. 4). Asegúrese de que la orientación sea exactamente como se muestra, ya que los LEDs infrarrojos y blancos se colocarán uno encima del otro en la carcasa final.
ii. | Con la ayuda del cortador de alambre, corta los extremos del LED
| de forma que la carcasa de plástico quede ajustada correctamente
| sobre los tableros de circuitos
iii. | Coloque los LEDs en los mini tableros de circuitos tal como se
| muestra en la figura. Es importante respetar la posición exacta, ya
| que esto garantiza que las piezas impresas en 3D que cubren los
| paneles de LEDs encajen correctamente. *Asegúrese de orientar los
| LEDs con la polaridad correcta (+/-). En la figura 4, los LEDs blancos
| del tablero de la izquierda tienen el pin positivo a la izquierda,
| mientras que los LEDs infrarrojos del tablero de la derecha tienen el
| pin positivo a la derecha.
iv. | Conecta los LEDs tal como se muestra en la figura. Esta es la
| primera parte del cableado y debe realizarse con los tableros
| colocados uno al lado del otro.

Figure 4. Conexiones eléctricas de los LED. En la imagen, las conexiones de los LED blancos se muestran a la izquierda y las de los LED infrarrojos a la derecha. Cabe destacar que se trata de conexiones simétricas, ya que estos dos conjuntos de LED se colocarán uno encima del otro, con los LED blancos orientados hacia arriba y los LED infrarrojos orientados hacia abajo (según la Fig. 5).

v. Retire la etiqueta adhesiva de la base de cada tablero de circuitos. Pegue los dos paneles juntos de manera que el LED blanco 1 y el LED infrarrojo 1 queden alineados verticalmente en la misma posición, pero en lados opuestos del doble panel de tableros (Fig. 5).

Figura 5 . Orientación de los LED blancos y los LED infrarrojos. Tenga en cuenta que, en posición vertical, cada LED blanco tiene un LED infrarrojo correspondiente. *Por simplicidad, el esquema de cableado no se muestra aquí (para ver el esquema de cableado, consulte la Fig. 4).

vi. Una vez unidos los paneles de LED blancos y los de LED infrarrojos, complete el cableado de los LED, siguiendo el esquema que se muestra en verde Fig.6. En la figura, los paneles se muestran uno al lado del otro para facilitar la visualización (por lo que el cableado en verde parece más largo de lo que realmente es). Sin embargo, el cableado debe realizarse con los paneles superpuestos (esto garantizará la estabilidad del mismo). Tenga en cuenta que estos cables (marcados en verde) conectan cada LED blanco al mismo circuito eléctrico que el LED infrarrojo situado justo debajo de él.

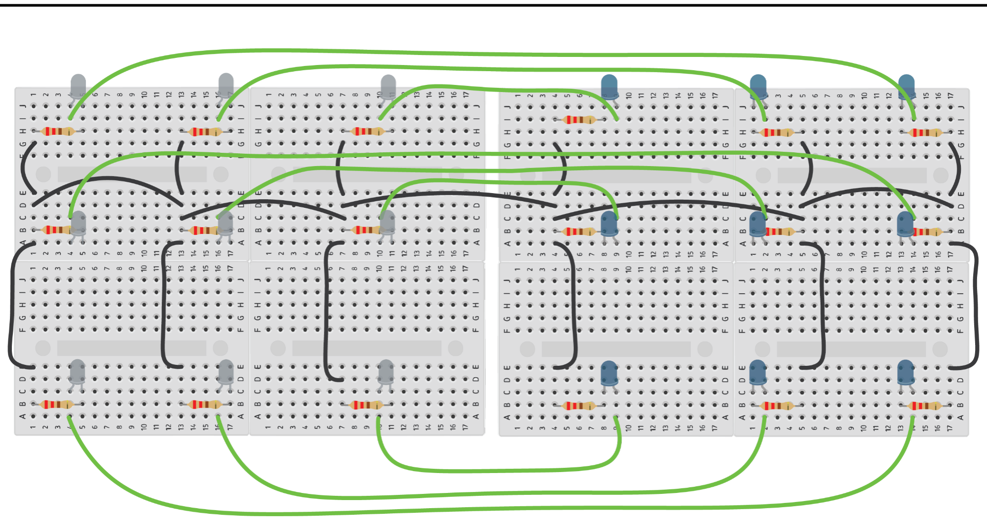
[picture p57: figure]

Figura 6. Cableado entre los paneles de LED blancos y los de LED infrarrojos (esta conexión debe realizarse con los dos paneles apilados verticalmente uno encima del otro, como se muestra en la Fig. 5).

b. LEDs de colores (que representan la señal de las dos células ganglionares de la retina)
Materiales necesarios: 1 LED amarillo, 1 LED verde, 2 mini tableros de circuitos
i. Corte los pines de los LED a una longitud de aproximadamente 10mm. Los LEDs deben estar aproximadamente 10mm encima del panel de circuitos. Esto es necesario para que los LED queden firmemente sujetos en los orificios correspondientes de la carcasa impresa en 3D.

ii. Coloque los dos LEDs en un mini tablero de circuitos, tal como se muestra en la Fig. 7. Apile este mini tablero sobre otro mini tablero del mismo tamaño. Ambos tableros deben estar orientados hacia arriba; puede fijarlos con cinta adhesiva (el tablero inferior sirve únicamente para elevar el superior, de modo que los LEDs queden correctamente posicionados dentro de la carcasa 3D).

Figura 7. Colocación de LEDs de colores en un mini tablero de circuitos. Estos LEDs representarán las señales de salida de las células ganglionares de la retina (RGC) 1 y 2.

b) MONTAJE DE LA CARCASA (~30 mins)
La carcasa debe imprimirse en 3D antes del montaje (se incluyen los archivos .stl). Ha sido diseñada en 6 partes separadas para facilitar la impresión y el montaje (Fig. 8 y 9).

Descripción de las piezas de la carcasa impresas en 3D:
P1 - pieza 1: Esta pieza constituye la base de la carcasa. En ella se encuentran la matriz de fotodiodos, los paneles de LED, los pines de salida y la placa de interfaz GPIO.
P2 - pieza 2: Ubicada sobre los fotodiodos, cada fotodiodo debe encajar en uno de los orificios de esta pieza.
P3 - pieza 3: Ubicada debajo del panel de LED infrarrojos. Cada LED infrarrojo debe encajar en uno de los orificios de esta pieza.
P4 - pieza 4: Pieza 4: Se conecta con las piezas 1 a 4 y proporciona soporte estructural, además de cubrir el cableado que atraviesa la parte central de la carcasa.

P5 - pieza 5: Ubicada en la parte superior de la estructura, cubre el panel de LED blanco y los dos LED de color.
P6 - pieza 6: Cierra la abertura en forma de C en el lateral de la carcasa. Esta es la última pieza que se debe colocar. Para la mayoría de las pruebas y la resolución de problemas del sistema RetINaBox, es necesario retirar la pieza P6.

*Las piezas impresas en 3D se denominarán P1, P2, etc, a lo largo del manual.
*La pieza P2 es más corta que la P3.

Figura 8. Piezas de RetINaBox impresas en 3D.
P1 | P2 | P3
P4 | P5 | P6

Figura 9. Piezas individuales de RetINaBox impresas en 3D.

Aquí (Fig.10) mostramos la carcasa completamente ensamblada desde varios ángulos de visión.

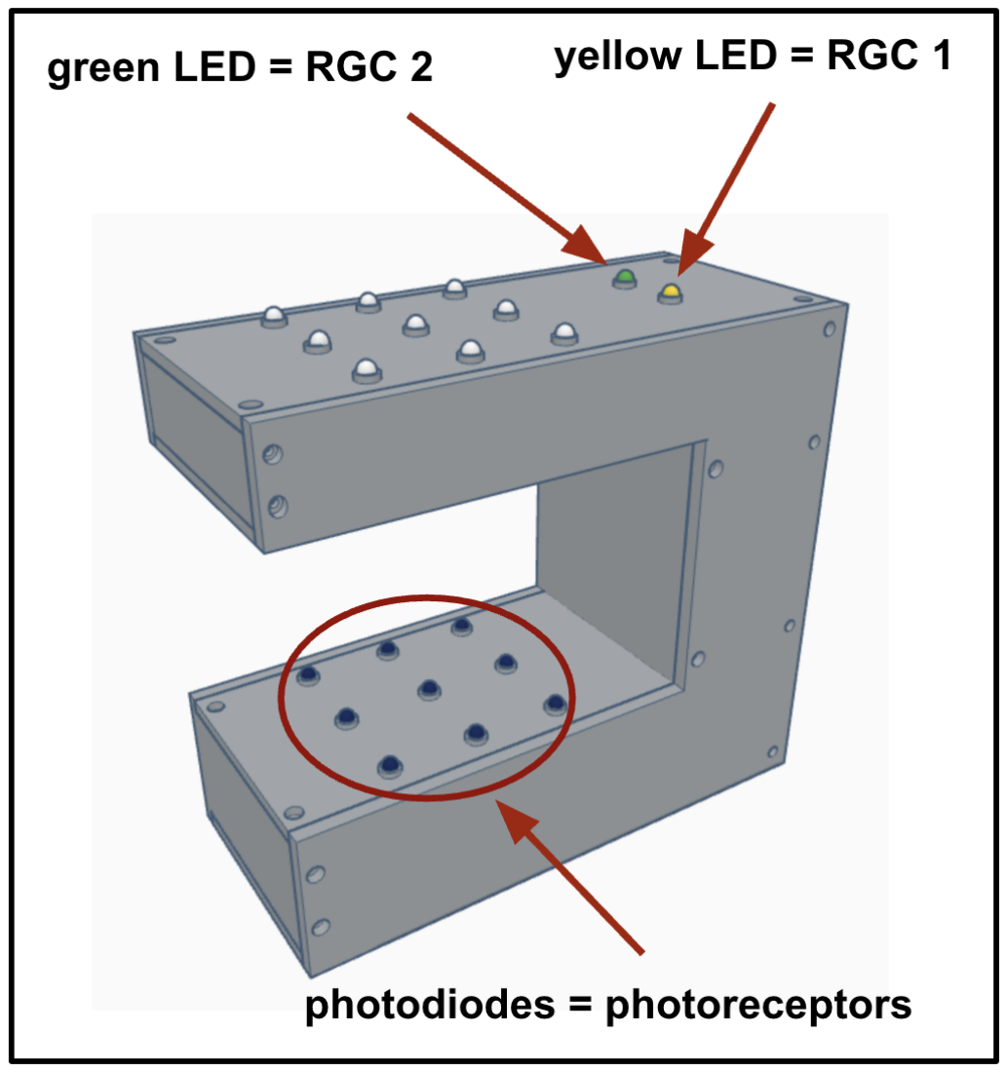
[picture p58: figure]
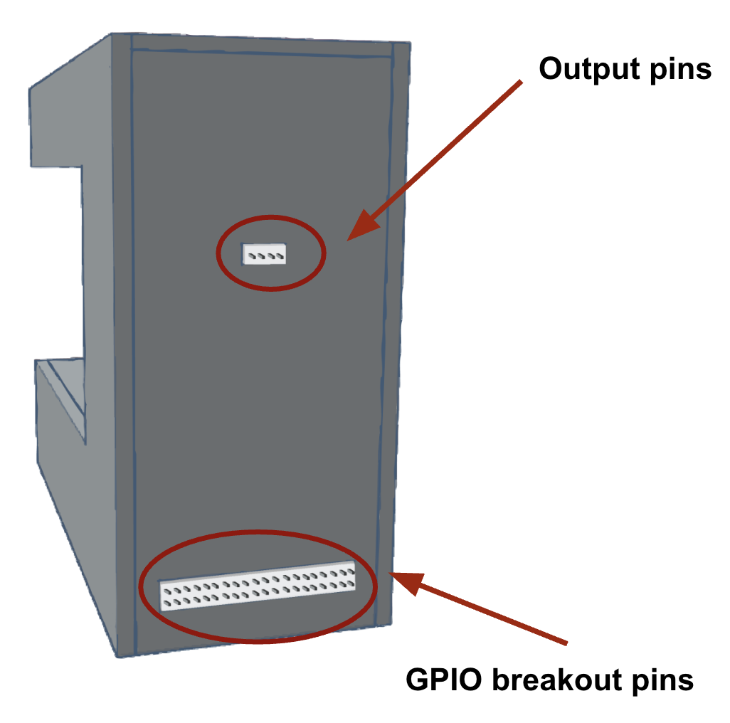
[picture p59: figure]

Figura 10. RetINaBox completamente montada.

c) CONEXIONES ELECTRÓNICAS al GPIO de Raspberry Pi

GPIO (general purpose input/output, entrada/salida de propósito general) RetINaBox incluye una interfaz GPIO que permite una conexión sencilla entre RetINaBox y Raspberry Pi mediante un único cable. Fije la placa de interfaz GPIO en el orificio correspondiente de P1 y asegúrela con cuatro tornillos M2 de 6 mm (Fig. 11). *Estos pasos se realizan simultáneamente con el montaje de la carcasa.

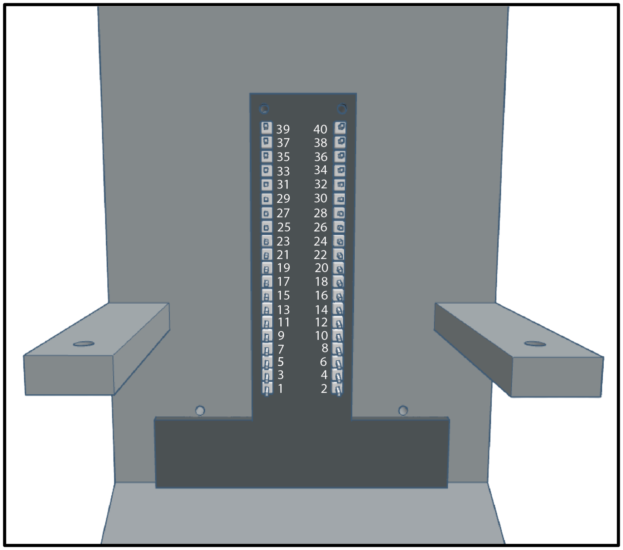
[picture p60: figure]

Figura 11. Instalación del adaptador GPIO de RetINaBox.

Si bien se muestra con mayor detalle en los siguientes pasos de montaje, aquí presentamos el esquema completo del cableado de la electrónica de RetINaBox (Fig. 12). *Todos los cables que van desde la placa GPIO al panel de LEDs deben pasar por el centro de la caja (Fig. 13).

Figura 12. Conexiones entre la interfaz GPIO y los componentes electrónicos de RetINaBox.

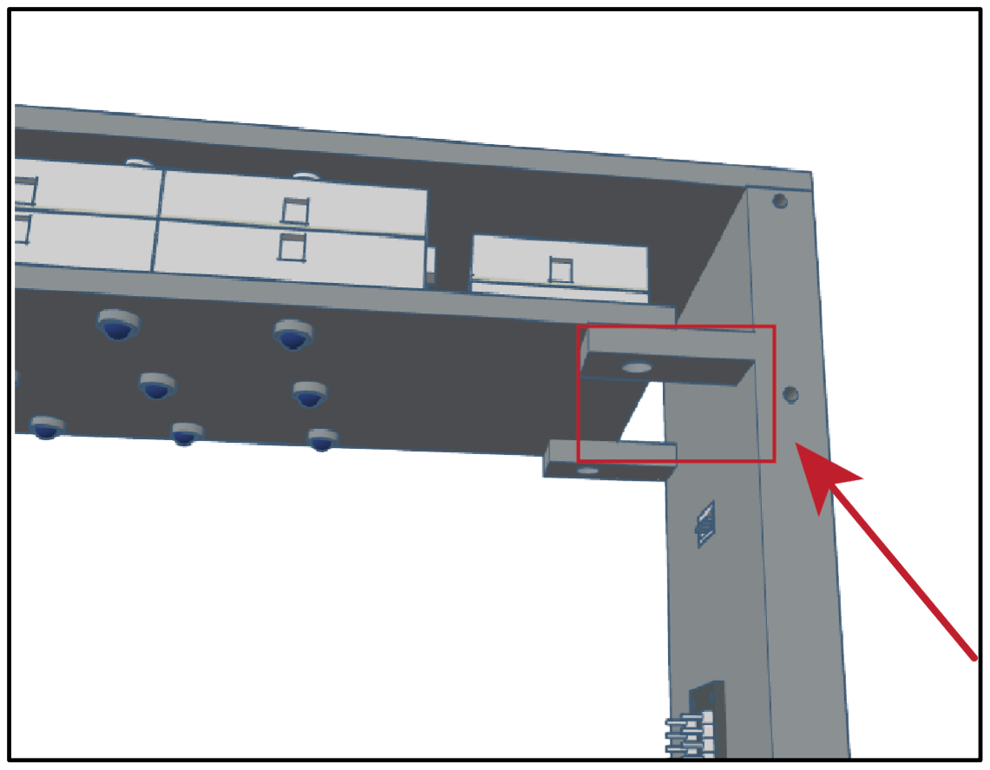
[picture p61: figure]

Figura 13. El cableado que conecta la placa GPIO con la matriz de LEDs debe pasar por el orificio indicado con el rectángulo rojo.

1. Conexión de los fotodiodos al GPIO:
Materiales necesarios: 11 cables Dupont (hembra a macho), 2 tornillos M3 de 6 mm de longitud
a. Coloque el panel de fotodiodos en P1 tal como se indica en la Fig 14. No remueva el sticker que cubre la base de los tableros de circuitos, el panel the fotodiodos no debe estar pegado a P1. Será sostenido firmemente por P2.

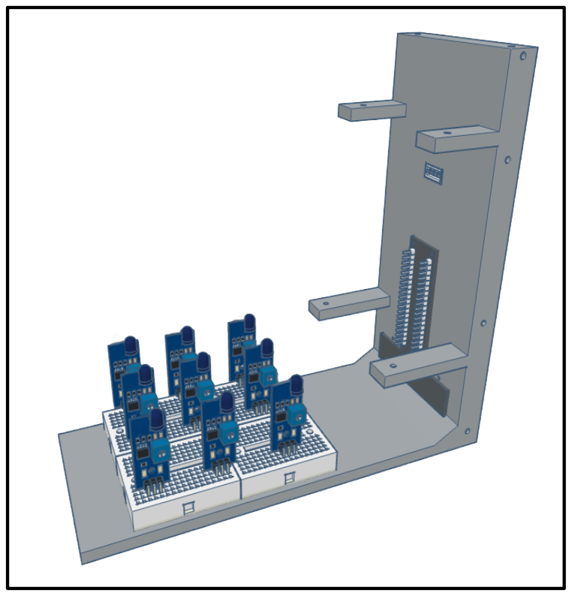
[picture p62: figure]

Figura 14. Colocación de los tablero con los fotodiodos en la pieza P1.

b. Utilice cables Dupont (hembra-macho) para conectar el pin de salida de señal de cada fotodiodo al GPIO, siguiendo las instrucciones de conexión que se indican a continuación (Fig. 15). Cada número de la Fig. 15 corresponde a un pin GPIO (Figs. 11 y 12).

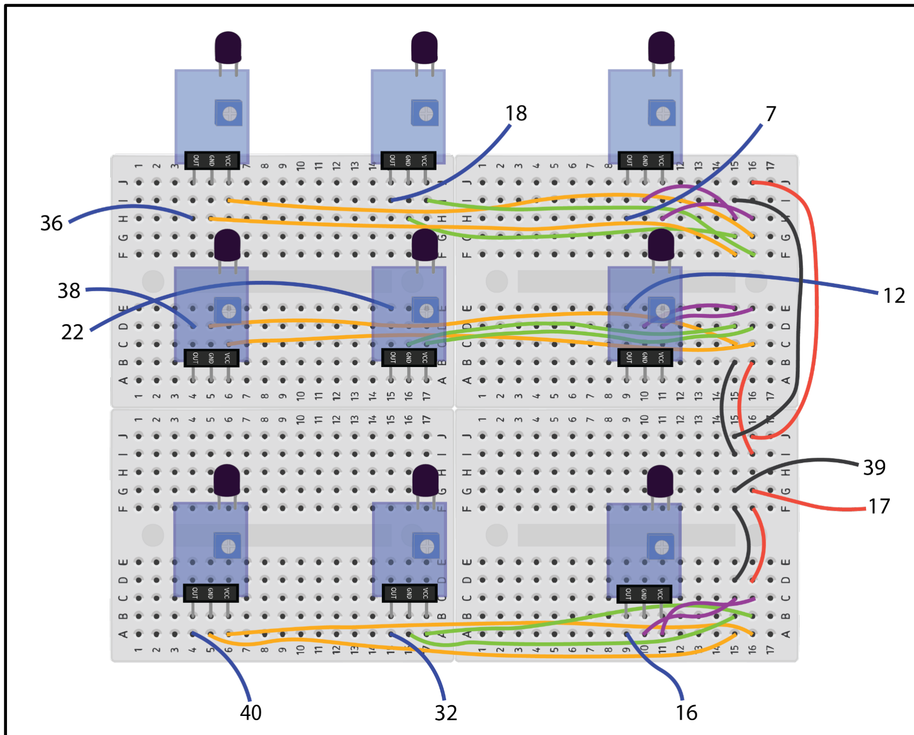
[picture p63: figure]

Figura 15. Lógica para conectar los fotodiodos al panel GPIO.

c. Coloque la pieza P2 sobre los fotodiodos. Introduzca cuidadosamente los 9 fotodiodos en los orificios de la pieza P2. A continuación, fije la pieza con tornillos M3 de 2 x 6 mm (Fig. 16). *No apriete los tornillos del todo todavía; la pieza P2 debe estar orientada de manera que las protuberancias (guías para los LED) queden hacia arriba.

Figura 16. Progreso del montaje: se han instalado los componentes P1 y P2, los fotodiodos y la placa de interfaz GPIO.

2. Conexión de los pines de salida de 3,3 V (las salidas digitales de las dos células retinianas) al GPIO:
Materiales necesarios: 4 cables Dupont hembra-hembra, 4 cables del kit del Connector Pre-Crimped Cable Kit, cinta eléctrica.
a. Arma un conector de 4 pines (con 4 pines a cada lado) y su correspondiente tapa, ambos del Connector Pre-Crimped Cable Kit. Esto permite conectar los cables por ambos lados. En un lado, los pines estarán visibles; en el otro, quedarán cubiertos por el zócalo.
b. Colóquelo en el orificio central de P1, tal como se muestra en Fig. 17. La parte con los pines del conector debe quedar orientada hacia el interior de la carcasa. *El conector debe quedar en la parte interior de la carcasa y los pines en la exterior. El conector debe encajar firmemente en el orificio de la carcasa.
c. Conecte los cables del kit a los 4 pines del conector situado en el interior de la carcasa de RetINaBox (Fig. 17).
d. Conecte estos cables en serie utilizando conectores Dupont hembra-hembra (asegure la conexión con cinta eléctrica) y conecte a los pines GPIO correspondientes (según se muestra en Fig. 17).

Figura 17. Conexión de los pines de salida de 3,3 V RGC a los GPIO. Tenga en cuenta que la tapa no aparece en el esquema de conexión.

3. Conexión del buzzer (parlante zumbador):
Materiales necesarios: 1 mini tablero de cirucitos, 1 resistencia de 10k ohms, 1 transistor PN2222, 1 buzzer activo Elegoo, 1 cable de conexión, 3 cables del Connector Pre-Crimped Cable Kit , 3 cables Dupont macho-hembra
a. En un mini tablero, coloque el buzzer, el transistor, la resistencia de 10K ohms y el cable de conexión, tal como se muestra en la Fig.18.

Figura 18. Ubicación del buzzer, del transistor, del cable de conexión entre el transistor, el buzzer y de la resistencia.
b. Conecte los componentes según se muestra en Fig. 19. Primero, conecte los tres cables del Connector Pre-Crimped Cable Kit a los pines de salida correspondientes. A continuación, conecte estos cables en serie mediante conectores Dupont hembra-macho (utilice cinta eléctrica o aislante para asegurar las conexiones). Tenga en cuenta que el buzzer está conectado a la placa GPIO mediante los pines de salida ubicados en la parte posterior de la caja (consulte Figs. 10, 12 and 17). Con este circuito, el zumbador solo sonará cuando los pines 24 y 26, que corresponden a RGC1 y RGC2, envíen 3,3 V simultáneamente, lo cual ocurre cuando RGC1 y RGC2 están activados al mismo tiempo.

Figure 19. Diagrama de conexión del circuito del buzzer (relacionado con la lección 2)

4. Conexión de los paneles LED al GPIO:
Materiales necesarios: cable eléctrico, cortador de cables, 10 cables Dupont hembra-hembra, 2 tornillos M3 de 6 mm de longitud
a. Una la pieza P3 con 2 tornillos M3 de 6 mm de longitud (Fig. 20). *La pieza P3 debe colocarse de forma que las protuberancias (guías) para los LED (es decir, las pequeñas elevaciones alrededor de cada orificio para el LED) queden orientadas hacia abajo.

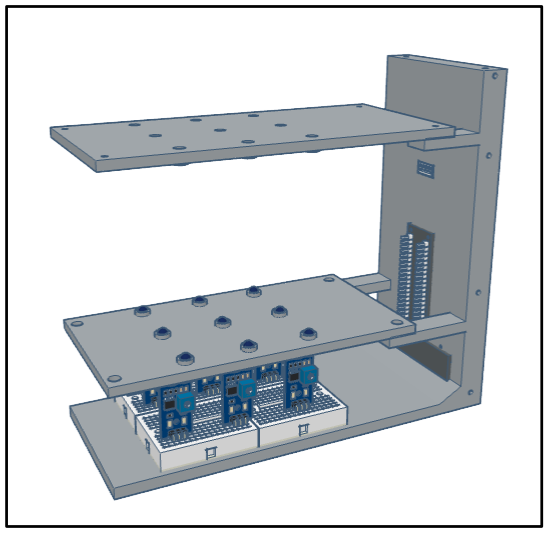
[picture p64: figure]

Figure 20. Unión de la pieza P3.

b. Coloque los paneles con los LEDs encima de P3 (Fig. 21; el cableado no se muestra aquí para facilitar la visualización). La base del panel de LEDs de colores no debe estar pegada a P3. Serán asegurados cuando P5 es colocado encima. *Antes de completar el paso b), siga los pasos c) y d).

Figure 21. Fijación de los LED encima de la pieza P3.

c. Conecte cada uno de los 9 pares de LED (blanco + infrarrojo) a los pines GPIO (mediante 9 cables naranjas (+) y negros (-, GND) en Fig. 22. Para los cables naranjas (el color naranja es solo para identificación visual; en realidad, usamos cable eléctrico rojo), corte el cable a la longitud adecuada (~5 cm) y conecte su extremo a un conector hembra-hembra Dupont, que a su vez se conectará a la placa GPIO (según se muestra en Fig. 22). *Se utiliza cable eléctrico (en lugar de cables Dupont) debido al espacio limitado entre los LED y las piezas impresas en 3D entre las cuales estarán posicionados estos paneles de LEDs.

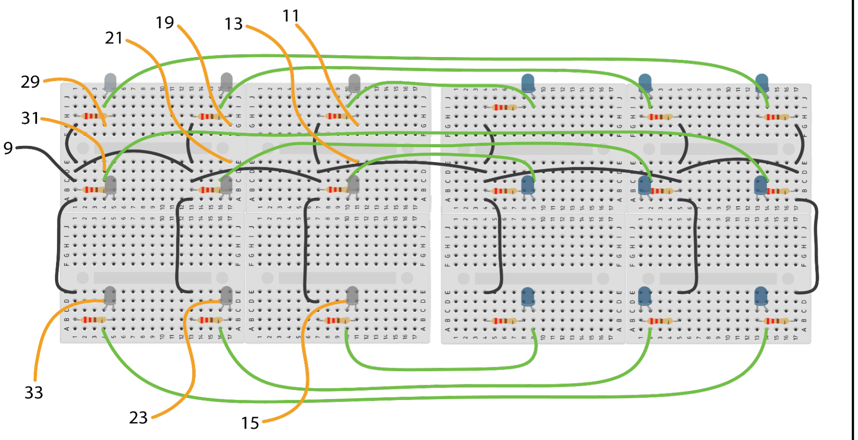
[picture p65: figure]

Figura 22. Conexión de LEDs blancos e infrarrojos a los pines GPIO.

d. Conecte los dos LED de colores (verde y amarillo), que representan las salidas de las células ganglionares 1 y 2, al GPIO, siguiendo la siguiente lógica (Fig. 23). De forma similar al paso anterior, utilice cable eléctrico y conéctelo a un conector Dupont hembra-hembra.

Figura 23. Conexión de los LEDs verdes y amarillos al GPIO.

e. Fije la pieza P4 uniéndola a las piezas P2 y P3 (Fig. 24). Esto estabilizará la carcasa y facilitará las pruebas. La instalación de las piezas P5 y P6, que cerrarán la carcasa de RetINaBox, deberá realizarse posteriormente, una vez que RetINaBox esté conectado a Raspberry Pi y se hayan comprobado las funciones electrónicas y se haya optimizado la sensibilidad de los fotodiodos (como se describe a continuación).

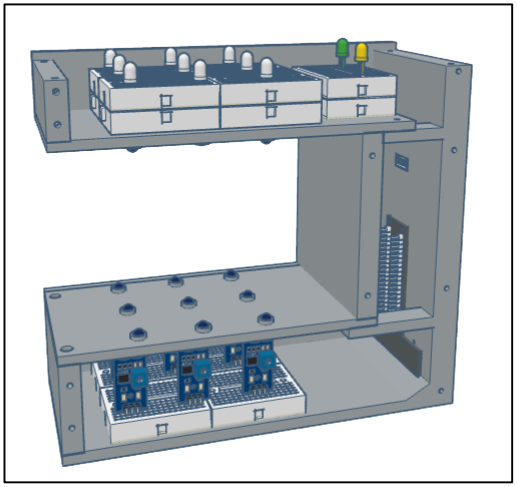
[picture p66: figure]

Figura 24. Unión de la pieza P4.

### 3. ARMADO DE LA HERRAMIENTA DE ESTÍMULO

Los estímulos visuales se pueden generar directamente con el Controlador de Estímulos Visuales dentro de la interfaz gráfica de usuario de RetINaBox. Sin embargo, para simular mejor los experimentos prácticos de neurociencia visual, los usuarios pueden activar todos los LED de estímulo de RetINaBox e insertar formas reales entre los LED y los fotodiodos (es decir, bloquear la luz en patrones específicos) para generar estímulos visuales y probar la selectividad de características de las dos RGC. Aquí ofrecemos un par de métodos para generar estímulos visuales que se pueden usar para probar RetINaBox.

a) Herramienta de Estímulo Visual

Materiales necesarios: lámina de plástico transparente, marcador permanente de punta fina, plastilina, regla (ver lista de materiales en el anexo)

Para presentar diferentes patrones de estímulos visuales a RetINaBox, recomendamos a los usuarios crear una herramienta de estímulos visuales. Para ello, cojan una lámina de plástico transparente y, con un rotulador permanente de punta fina y una regla, dibujen una cuadrícula que cubra toda la lámina (Fig. 25). Cada cuadrado de la cuadrícula debe tener 3 cm de ancho por 3 cm de largo, lo que corresponde aproximadamente al área del campo receptivo de un fotodiodo de RetINaBox.

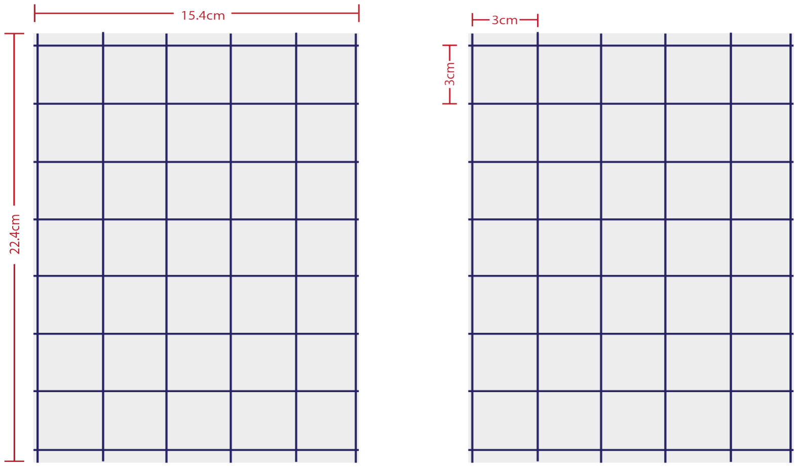
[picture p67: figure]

Figura 25. Herramienta de Estimulación Visual con cuadrículas para alinear los estímulos con la matriz de fotorreceptores del modelo.

A continuación, coloca la plastilina sobre la lámina de plástico. Deja ciertas zonas sin plastilina para crear el estímulo visual (es decir, el paso de la luz a través de esas zonas será el estímulo). Puedes utilizar la plastilina para crear estímulos visuales de diferentes formas y presentarlos a RetINaBox (Fig. 26).

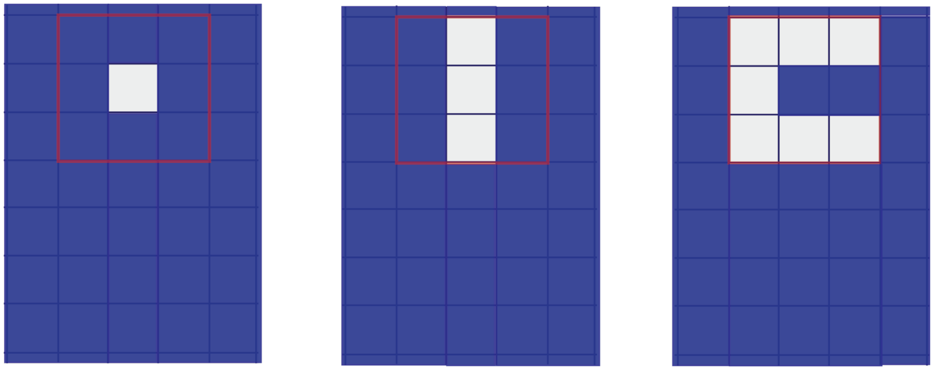
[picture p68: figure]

Figura 26. Ejemplos de estímulos visuales. La región marcada con el cuadrado rojo indica el tamaño del campo visual de RetINaBox.

La herramienta de estimulación visual funciona controlando qué fotoreceptores (es decir, fotodiodos) se activan, permitiendo que la luz procedente de los LED de estimulación llegue a los fotodiodos (Fig. 27).

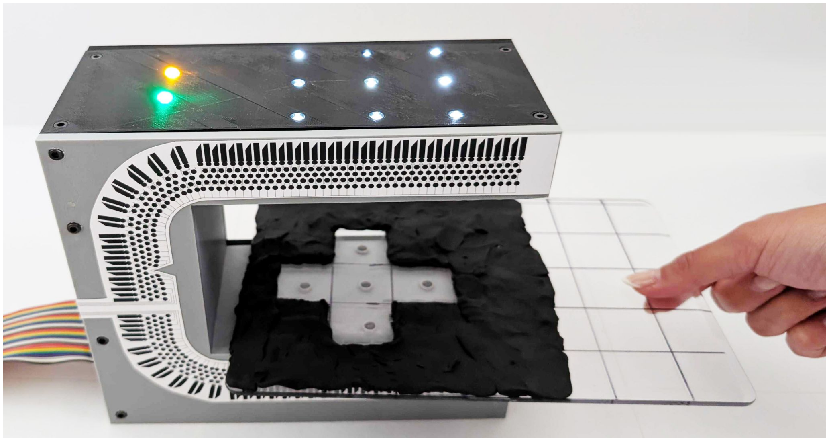
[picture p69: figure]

Figura 27. Herramienta de estímulo visual en acción (este ejemplo relacionado a la lección 2)

b) Estímulo Visual con formas cortadas de papel/cartón
Si bien la Herramienta de Estímulo Visual es una excelente opción, ya que permite crear prácticamente cualquier forma, tanto activada como desactivada, puede llevar un tiempo cambiar entre diferentes estímulos. Como método alternativo para probar las respuestas visuales en RetINaBox más rápidamente, se pueden recortar formas de papel o cartón. Para empezar, los usuarios pueden acceder a un documento PDF con plantillas de formas que se pueden imprimir y recortar aquí. Estas formas, como se muestra en la Fig. 28, se pueden utilizar para realizar muchas de las actividades del plan de lecciones. También se pueden generar otras formas según se considere necesario.

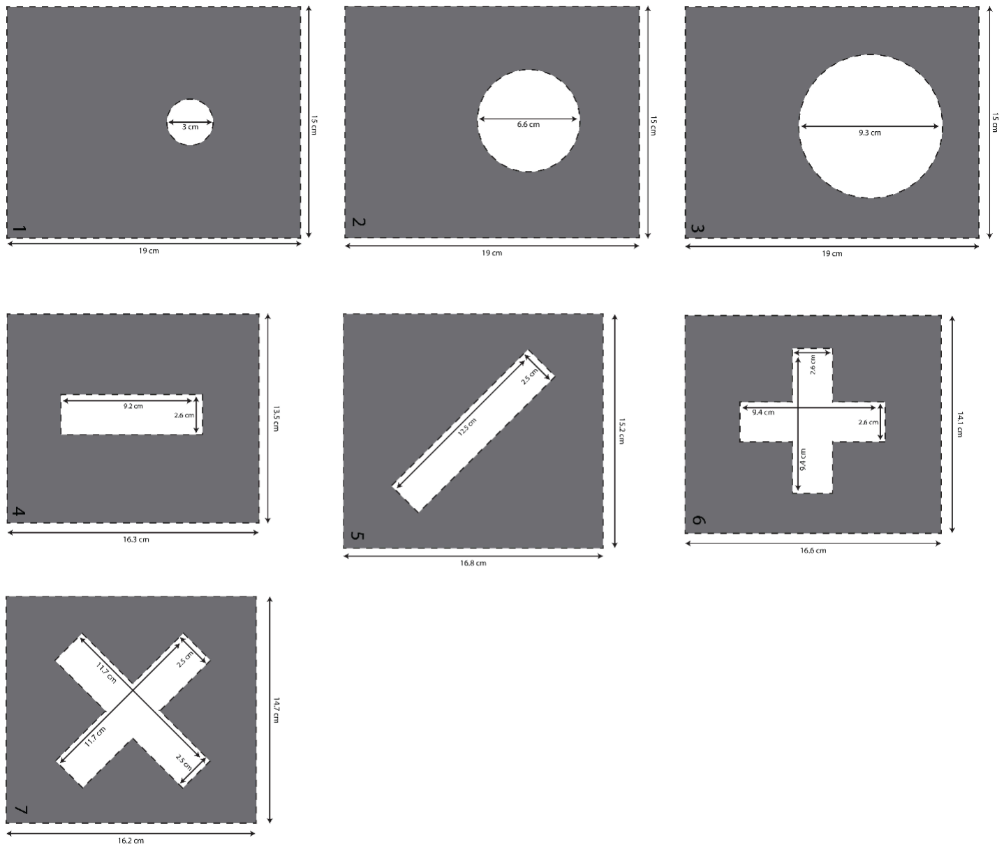
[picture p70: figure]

Figura 28. Formas de estímulo visual se pueden imprimir y recortar en papel o cartón.

### 4. INSTALACIÓN DEL SOFTWARE

a. En su Raspberry Pi, utilice el navegador web para acceder a la página de GitHub del proyecto RetINaBox del Trenholm Lab: https://github.com/Trenholm-Lab/RetINaBox *Recomendamos usar un Raspberry Pi 500 (o Raspberry Pi 5). Probamos el software en una Pi 400 y, aunque funciona, si se presentan problemas de compatibilidad, presenta cierta demora.
b. Descargue el archivo ZIP del repositorio haciendo clic en el botón verde ‘Code’ y, a continuación, en el botón ‘Download ZIP’ (Fig. 29). Una vez descargado, el archivo ZIP aparecerá en la carpeta de descargas con el nombre RetINaBox-main.zip.


Figura 29. Descargando el software RetINaBox desde GitHub.

c. Para descomprimir los archivos de código en su dispositivo, haga clic con el botón derecho del ratón sobre el archivo RetINaBox-main.zip y seleccione ‘Extract To…’ (Extraer a). Seleccione el escritorio como carpeta de destino y deje las demás opciones como están, tal como se muestra en Fig. 30. Tras este paso, el escritorio contendrá una carpeta llamada RetINaBox-main. No modifique ni mueva esta carpeta. Ahora puede cerrar el explorador de archivos.

Figura 30. Menú de extracción de archivos (Extract Files) de Raspberry Pi

d. Abre el terminal y escribe los siguientes comandos, presionando la tecla Enter después de cada uno, tal como se muestra en Fig. 31.
cd Desktop/RetINaBox-main/Software/RetINaBox chmod +x install_RetINaBox.py
python3 install_RetINaBox.py


Figura 31. Terminal durante la instalación del código de RetINaBox.

e. Tras la instalación exitosa de RetINaBox, verá una nueva aplicación en su escritorio. Para acceder a la interfaz gráfica (GUI), haga doble clic en la aplicación RetINaBox y luego haga clic en Execute (ejecutar) (Fig. 32). ¡Bienvenido al laboratorio de RetINaBox!
i. Si la instalación no resulta exitosa, consulte la sección A2 del manual de usuario: Apéndice 2: Resolución de problemas.

Figura 32. RetINaBox: Mensaje de ejecución de archivo.

### 5. CONEXIÓN DE RetINaBox AL Raspberry Pi

a. Conecte RetINaBox a Raspberry Pi utilizando el cable arcoíris de conexión GPIO. IMPORTANTE: los conectores grises en ambos extremos del cable tienen una pequeña muesca de plástico en un lateral; es fundamental conectarlos correctamente a RetINaBox y Raspberry Pi, ya que de lo contrario la conexión será incorrecta y podría dañarse el Raspberry Pi o alguno de los componentes electrónicos podrían quemarse! Los conectores de RetINaBox y Raspberry Pi también tienen muescas que indican la orientación correcta para la conexión del cable arcoíris.
b. Conecte la computadora Raspberry Pi a la fuente de corriente (es decir, enchufe la Raspberry Pi). Recomendamos utilizar un cable extensor para el cable de conexión arcoíris, que duplica su longitud y facilita la orientación de la RetINaBox junto al Raspberry Pi 500.
c. Si los fotodiodos están conectados correctamente, el LED rojo situado a la derecha en cada placa de circuito debería encenderse (Fig. 33), lo que indica que están recibiendo corriente.

Figura 33. Powering ON the Raspberry Pi should result in power going to all 9 photodiodes, which should turn on the right-most red LED on each photodiode circuit board.

d. El siguiente paso es ajustar la sensibilidad de los fotodiodos IR para que solo se activen cuando se enciendan los LED IR. Primero, tome un destornillador pequeño y, para cada fotodiodo, gire el potenciómetro en sentido horario hasta que se encienda el LED más a la izquierda (Fig. 34). Luego, gire el potenciómetro aproximadamente media vuelta en sentido antihorario para que el LED más a la izquierda se apague. A continuación, abra el software RetINaBox (consulte la Sección 6 a continuación) y encienda los 9 LED. Si los LED se han conectado correctamente, los 9 LED blancos en la parte superior de RetINaBox deberían encenderse (visibles a simple vista), y los 9 LED IR también deberían encenderse, pero no ser visibles a simple vista. Al encender los LED, se activarán los fotodiodos y se encenderá el LED más a la izquierda de cada fotodiodo. Si esto no sucede, ajuste la sensibilidad del fotodiodo con el potenciómetro hasta que el LED rojo más a la izquierda solo se encienda cuando se encienda el LED IR directamente sobre ese fotodiodo (Fig. 34). Si un fotodiodo está encendido pero no puede activarlo encendiendo los LED, es probable que el LED IR no esté conectado correctamente (consulte la sección Solución de problemas).


Figura 34. Ajuste la sensibilidad del fotodiodo infrarrojo girando el potenciómetro hasta que el LED rojo de la izquierda de la placa de circuito se encienda únicamente cuando los LEDs infrarrojos estén activados en el software RetINaBox.

e. Monte las piezas P5 y P6 (Fig. 35). ¡Ya ha terminado de ensamblar RetINaBox!


Figura 35. RetINaBox Completa.

### 6. USO DEL SOFTWARE

a. Haga doble clic en el logotipo de "RetINaBox" en el escritorio, o bien, en Visual Studio Code, ejecute el archivo "main.py".
b. Se abrirá la pantalla de bienvenida (Fig. 36). Seleccione “Enter the Lab” para comenzar a utilizar RetINaBox. También podrá acceder al manual de usuario y a las guías didácticas.


Figura 36. Pantalla de bienvenida de RetINaBox.

c. Ahora verá la interfaz gráfica principal de RetINaBox. (GUI; Fig. 37).

El software contiene 4 elementos de menú:
i. User Manual (Manual de usuario): Abre el manual de usuario en formato PDF.
ii. | Lessons (Lecciones): Aquí puedes acceder a los planes de lección.
| Además, para cada una de las 4 lecciones encontrarás la configuración
| predeterminada de RetINaBox y los desafíos específicos de cada lección.
iii. | Save (Guardar): Haz clic aquí para guardar la configuración actual de
| RetINaBox.
iv. | Open (Abrir): Haga clic aquí para abrir la configuración de RetINaBox
| guardada previamente.

La interfaz gráfica de usuario de RetINaBox está dividida en 3 secciones (explicaremos cada una de ellas con más detalle a continuación):
| Visual Stimulus Controller (Controlador de estímulos visuals): Esta sección
| permite controlar los LED de estímulos de RetINaBox.
| Connectivity Manager (Gestor de conectividad): Aquí se establecen las
| conexiones entre los fotoreceptores y las células ganglionares del modelo.
| Signal Monitor (Monitor de señal): Muestra cuándo están activas las células
| fotoreceptoras, qué señal transmiten a las células ganglionares y cuándo
| estas últimas se activan.


Figura 37. La interfaz gráfica principal de RetINaBox.

d. Visual Stimulus Controller (Fig. 38).
i. En la parte superior, verá la matriz de LEDs de 3x3. Antes de encender los LEDs, deberá seleccionarlos (haciendo clic en ellos). Estos aparecerán en gris en la pantalla.
ii. | A continuación, puede elegir si desea presentar un estímulo estático o en
| movimiento (hacia la izquierda o hacia la derecha). Para empezar,
| seleccione el modo Static (Estático).
iii. | Ahora, pulse el botón de ON/OFF (Encendido/Apagado). En la pantalla,
| verá que los LEDs seleccionados están activos (de color amarillo). Si está
| conectado a RetINaBox, también verá los LEDs seleccionados encendidos.
| La numeración de los LEDs en el software corresponde a la vista frontal de
| RetINaBox.
iv. | Para la lección sobre selectividad direccional (lección 3), puede configurar
| el movimiento de los estímulos visuales hacia la izquierda o hacia la
| derecha. Para ello, seleccione un patrón de LEDs (debe encenderlos
| primero), elija el modo Motion (Movimiento), la dirección (flecha izquierda o
| derecha) y la velocidad (lenta, media o rápida).
v. Finalmente, para todas las lecciones, en algún momento necesitará probar
| estímulos reales, utilizando la herramienta de presentación de estímulos o
| sus manos. Para ello, active los 9 LEDs, seleccione el modo Static y
| enciéndalos.

Figura 38. Visual Stimulus Controller.
e. Connectivity Manager (Fig. 39).

i. El Connectivity Manager permite configurar la conexión entre cada uno de los 9 fotoreceptores del modelo (es decir, los fotodiodos) y las 2 células ganglionares retinianas (RGCs).
ii. | Para cada una de las 2 RGCs, cada fotoreceptor puede configurarse de la
| siguiente manera:
1. Silent (Silencioso): no envía señal a la célula ganglionar.
2. Excitatory (Excitatorio): al activarse, envía una señal de +1 a la
| célula ganglionar.
3. Inhibitory (Inhibitorio): al activarse, envía una señal de -1 a la célula
| ganglionar.
4. Delay (Retardo): se puede añadir un retardo de tiempo entre la
| activación del fotoreceptor y el envío de la señal a la célula
| ganglionar. Las opciones de retardo son: ninguno, corto, medio y
| largo. Estos retardos son útiles para generar respuestas selectivas
| a la dirección y ayudan a modelar la conectividad asimétrica del
| circuito.
iii. | Para modificar la conectividad a una de las células ganglionares, haga clic
| en su circuito (Fig. 39, izquierda). Se abrirá una ventana (Fig. 39, derecha)
| donde podrá modificar la configuración de cada fotoreceptor.
iv. | Establezca el umbral del RGC. En cada momento, el RGC sumará todas
| las entradas de sus fotorreceptores y debe alcanzar este umbral para
| activarse.
v. Establezca el tipo de RGC como ON o OFF. En los RGC ENCENDIDOS,
| los fotorreceptores se consideran activados cuando el fotodiodo detecta
| luz. En los RGC OFF, los fotorreceptores se consideran activados cuando
| el fotodiodo no detecta luz.

Figura 39. Connectivity Manager la interfaz gráfica principal (izquierda) y su ventana emergente (derecha).

f. Signal Monitor (Fig. 40).
i. El Signal Monitor muestra en tiempo real la siguiente información:
1. Qué fotoreceptores del modelo están activos. Esto se visualiza cuando los círculos del lado derecho se vuelven amarillos.
2. La polaridad de la señal que envía cada fotoreceptor activado a cada célula ganglionar de la retina: excitatoria (roja) o inhibitoria (azul).
3. Cuándo se activa cada célula ganglionar (RGC1, superior; RGC2, inferior). Esto ocurre cuando la suma de todas las entradas de los fotoreceptores alcanza o supera el umbral establecido en el Connectivity Manager.

Figura 40. Signal Monitor.
g. Funcionalidades adicionales del software
i. Actividad de descifrado de códigos:
1. En la lección 2, los usuarios deben utilizar los campos receptivos centro-periferia para descifrar códigos. Accediendo a la pestaña "Lessons" en la barra de menú (Lessons > Lesson 2 > Code Breaker), y seleccionando la actividad "Code Breaker", se abrirá una nueva pestaña (Fig. 41).
2. Utilizando la información del código, los usuarios deben volver a la interfaz principal de RetINaBox y configurar el Connectivity Manager para que las células ganglionares RGC1 y RGC2 respondan a los estímulos visuales descritos en el código.
3. A continuación, deben usar la Herramienta de Estímulos Visuales para presentar los estímulos correspondientes a cada letra del código y, consultando el descodificador, introducir la letra correcta en el campo de texto correspondiente a cada estímulo.
4. Una vez descifrado el código, los usuarios pueden comprobar la respuesta.

Figura 41. Actividad de descifrado de códigos relacionada con la Lección 2.

ii. Videojuego Block breaker:
1. En la Lección 3, después de generar las células ganglionares
| selectivas para el movimiento hacia la izquierda y hacia la derecha, se le indica al usuario que abra el juego de romper bloques (accesible a través de la pestaña "Lessons" en la barra de menú). Esto abrirá el juego (Fig. 42). Al abrir el juego, se encienden automáticamente todos los LEDs de estímulo de RetINaBox.
2. El juego está programado para que la señal de salida de RGC1 de
| RetINaBox controle el movimiento de barra gris hacia la izquierda, y la señal de salida de RGC2 la controle hacia la derecha.
3. A continuación, el usuario mueve la mano de izquierda a derecha
| frente al campo de visión de RetINaBox para controlar la barra y jugar.


Figura 42. Videojuego Block breaker relacionado a la Lección 3.

iii. Modo Descubrimiento (Discovery Mode):
1. La Lección 4, Modo Descubrimiento, se accede a través de la
| pestaña "Lessons" en la barra de menú. Se abre la pestaña "Discovery Mode" (Fig. 43). Al activar el modo descubrimeinto, se encienden automáticamente todos los LEDs de estímulo de RetINaBox.
2. A continuación, el usuario selecciona un desafío (Challenge) en el
| menú.
3. En la fase 1, los usuarios utilizan la herramienta de estímulo visual
| o su mano para presentar a RetINaBox diversos estímulos, tanto estáticos como dinámicos, hasta lograr activar la célula ganglionar retiniana (RGC1).
4. Una vez que el usuario encuentra el estímulo visual óptimo para el
| desafío propuesto, lo introduce en la sección izquierda del software

(Phase 1) y selecciona ‘Test Stimulus’. Si la respuesta es correcta, pasa a la fase 2 (Phase 2).
5. En la fase 2, el usuario configura la conectividad entre los fotorreceptores y la célula ganglionar retiniana (RGC) para recrear la selectividad del estímulo visual identificada en la fase 1. Una vez satisfecho con la configuración, el usuario hace clic en ‘Test Connectivity’.


Figura 43. Interfaz gráfica de usuario de Discovery Mode.

Categoría | # | Producto | Especificationes | Proveedor | Notas
RetINaBox | 6 | Carcasa | Pieza impresas 3D (link) (https://drive.google.com/drive/folders/1DmUhCU8-99DyLmYc_d9g1IFadtFvgH2a?usp=sharing)
| 14 | Tornillos M3 10mm
| 12 | Tornillos M3 6mm
| 4 | Tornillos M2 6mm | | | Usado para asegurar el panel GPIO a la carcasa
| 9 | 5mm LEDs IR | 100 mA en corriente continua, 1000 mA en corriente de pulso Tensión directa aproximada: 1,6 V | Adafruit 387 (https://www.adafruit.com/product/387)
| 9 | Fotodiodos infrarrojos (IR) | | Amazon (https://www.amazon.ca/HiLetgo-Infrared-Avoidance-Reflective-Photoelectric/dp/B07W97H2WS)
| 1 | Elegoo electronics kit | Lo que necesitarás: 9 LEDs blancos, 1 LED verde, 1 LED amarillo, resistencias | Amazon (https://a.co/d/1njj6g7)
| 12 | Mini Tableros de circuitos | | Amazon (https://a.co/d/6qQtx3f)
| 26 | Cables Dupont | | Amazon (https://a.co/d/4TvdGkJ)
| | Kit de cables de conexión | | Amazon (https://a.co/d/fxJ6lkD)
| 1 | Kit de expansión GPIO para Raspberry Pi | | Amazon (https://a.co/d/4zZ2Pfc)
| 1 | Extensor de conexión arcoiris | Opcional: añadir uno o dos cables adicionales permite una mayor libertad para posicionar RetINaBox junto a la Raspberry Pi. | Amazon (https://www.amazon.ca/Jumper-Computer-Accessories-Breadboard-Ribbon/dp/B0DQJTR131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)
| 1 | elechawk PH 2.0 Connector Pre-Crimped Cable Kit | | Amazon (https://a.co/d/gQgTWbW)
| 1 | Rollo de cinta elétrica

A1- ANEXO 1: LISTA DE COMPONENTES

Category | # | Product | Specifications | Supplier | Notes
| 1 | Cable eléctrico de color rojo | | Digikey (https://www.digikey.ca/en/products/detail/alpha-wire/3051-1-RD005/281577) | Si tienes alguno a mano, perfecto. Si no, puedes pedir algo similar, no tiene que ser exactamente este producto.
| 1 | Cable eléctrico negro | | Digikey (https://www.digikey.ca/en/products/detail/alpha-wire/3051-1-BK005/281576) | Misma nota que la anterior
Para comprobar el funcionamiento de los LEDs IR | 1 | 3.3V USB a Serial Adapter | Opcional | Amazon (https://www.amazon.ca/dp/B08G1JNSWV?previewDohEventScheduleTesting=C) | Puedes utilizar esto para alimentar un fotodiodo IR y probar los LED IR de forma independiente del resto de RetINaBox.
Herramienta de Estímulo Visual | Set de 2 | Lámina de plástico transparente (15.4x 22.4cm) | | Amazon (https://www.amazon.ca/BAOFALI-Standard-Cutting-Machine%EF%BC%9BClear-Polycarbonate/dp/B0C5QGRGJN) | Coloca la plastilina aquí y luego presiónala entre los LED infrarrojos y los fotodiodos de RetINaBox.
| 1 | Sharpie de punta fina | Cualquier marcador de punta fina funcionará | | Para dibujar una cuadrícula en la herramienta de estímulo visual, que sirva de guía para colocar la plastilina.
| 1 | Plastelina | Cualquier marca funciona, inclusive play dough | | Necesitas una cantidad suficiente para cubrir la herramienta de estímulo visual.
Herraminetas | 1 | 2.5mm hex key | | | Se utiliza con tornillos M3
| 1 | 1.5mm hex key | | | Se utiliza con tornillos M2

A2- ANEXO 2: RESOLUCIÓN DE PROBLEMAS

Problemas relacionados con la impresión 3D:

a. Los fotodiodos y los LED no encajan correctamente en los orificios de las piezas impresas en 3D.
i. Recomendamos imprimir primero la pieza P2, P3 o P5 y comprobar que los LED/fotodiodos queden bien ajustados en los orificios. Si no es así, deberá ajustar el tamaño de las piezas en un porcentaje (aumentando o disminuyendo) según la configuración de su impresora. A continuación, deberá aplicar el mismo factor de escala a todas las demás piezas impresas.

Problemas relacionados con los fotodiodos:

a. El indicador LED de alimentación del fotodiodo (el LED a la derecha en la placa de circuito) no se enciende cuando RetINaBox está conectado al Raspberry Pi y esta última está encendida.
i. Compruebe el cableado entre el conector GPIO de RetINaBox y el fotodiodo. Un multímetro puede ser útil.
ii. | Asegúrese de haber conectado correctamente el cable de conexión.
iii. | Puede comprobar que Raspberry Pi está suministrando correctamente la
| alimentación a los LEDs. Primero, desconecte el cable de conexión. Luego,
| conecte un LED visible a una placa de pruebas pequeña. Con un cable
| Dupont hembra-macho, conecte el pin GPIO 17 (que normalmente
| proporciona 3,3 V para alimentar los fotodiodos) al terminal (+) del LED.
| Con otro cable Dupont, conecte el pin GPIO 39 (que normalmente
| proporciona la alimentación (-)/GND a los fotodiodos) al terminal (-) del
| LED. Si el LED se enciende, Raspberry Pi está suministrando la
| alimentación correctamente, y el problema está en el cableado. Si no
| funciona, es posible que el pin de Raspberry Pi se haya dañado.
b. El fotodiodo está siendo alimentado, pero no se activa (es decir, el LED rojo de la izquierda de su placa no se enciende) cuando se encienden los LEDs IR, o no se
1 | Cortador de cable
1 | Destornillador pequeño | Para ajustar la sensibilidad del fotodiodo

desactiva (es decir, el LED rojo de la izquierda no se apaga) cuando se apagan los LEDs IR.
i. La sensibilidad del fotodiodo no está ajustada correctamente. Retire la pieza P6. Con el software de RetINaBox, encienda el LED situado justo encima del fotodiodo con el problema. Ajuste el potenciómetro de ese fotodiodo (ver Fig. 34) con un destornillador hasta que el LED rojo de la izquierda se encienda cuando el LED esté encendido y se apague cuando esté apagado.
ii. | Si el paso 1 no funciona, hay dos posibles problemas. Primero, podría ser
| que el LED IR no esté conectado correctamente. Para comprobarlo,
| consulte la sección “Problemas relacionados con los LEDs”. En segundo
| lugar, podría ser que el fotodiodo y el LED correspondiente no estén
| correctamente alineados dentro de la carcasa impresa en 3D. En la medida
| de lo posible, cada fotodiodo debe apuntar directamente al LED infrarrojo
| correspondiente, y cada LED infrarrojo debe apuntar directamente al
| fotodiodo correspondiente (los LED tienen un ángulo de emisión
| relativamente estrecho y los fotodiodos son más sensibles a la luz que
| incide directamente sobre ellos).

Problemas relacionados con los LEDs:

a. Uno de los LED blancos no se enciende cuando se activa en el software.
i. Compruebe el cableado (y la polaridad del LED).
ii. | Pruebe a sustituir el LED.
iii. | Como en el paso a-iii de la sección "Problemas relacionados con los
| fotodiodos ", puede comprobar directamente que la Raspberry Pi envía la
| señal correcta. Consulte las Figs. 12 y 22 para identificar los pines GPIO
| que corresponden al LED que no funciona. Con un cable Dupont hembra-
| macho, conecte el pin GPIO que alimenta el LED defectuoso (que
| normalmente proporciona 3,3 V) al terminal (+) del LED en el tablero de
| circuitos. Con otro cable Dupont, conecte el pin GPIO 9 (que normalmente
| proporciona la alimentación (-) /GND a los fotodiodos) al terminal (-) del
| LED. Si el LED se enciende al activarlo en el software, la Raspberry Pi está
| funcionando correctamente y el problema está en el cableado. Si no
| funciona, es posible que el pin de la Raspberry Pi se haya dañado.
b. Uno de los LEDs infrarrojos no se enciende cuando se activa en el software.
i. Compruebe el cableado (y la polaridad del LED).
ii. Pruebe a sustituir el LED.

iii. | Siga las mismas instrucciones que en la sección "Problemas relacionados
| con los LEDs" (a-iii). Como no se puede ver si el LED infrarrojo está activo,
| puede usar el fotodiodo correspondiente en RetINaBox o conectar un
| adaptador serie USB-TTL (ver lista de componentes recomendados) a un
| fotodiodo y usarlo para comprobar la activación del LED infrarrojo.
c. Uno de los LEDs de color (verde o amarillo) no se enciende cuando el software está en ejecución y la célula ganglionar retiniana correspondiente está activada en el Signal Monitor de la interfaz gráfica (GUI).
i. Compruebe el cableado (y la polaridad del LED).
ii. | Pruebe a sustituir el LED.
iii. | Siga las mismas instrucciones que en la sección "Problemas relacionados
| con los LEDs" (a-iii), pero para los pines GPIO que alimentan estos dos
| LED (Figs. 12 y 22).
d. En el caso de un par de LEDs (uno blanco y otro infrarrojo) conectados, solo uno de ellos se enciende (es decir, reciben alimentación, pero solo uno está activo).
i. Compruebe el cableado (y la polaridad del LED).
ii. | Intente reemplazar el LED que no funciona.
iii. | Asegúrese de que las resistencias sean las adecuadas (esto es importante,
| ya que los diferentes tipos de LEDs tienen diferentes voltajes de
| polarización directa (y probablemente también diferente resistencia
| interna). Para garantizar que ambos LEDs se activen con la misma fuente
| de alimentación, debemos usar resistencias para estandarizar la corriente
| que fluye a través de ambos LEDs).
e. Los LEDs parpadean.
i. Compruebe el cableado: probablemente sea un problema de conexión.

Problemas relacionados con la instalación del Software:

a. El código no se ejecuta al hacer clic en la aplicación RetINaBox y seleccionar la opción ‘Execute’. Vea sugerencias para solucionar problemas aquí. (https://github.com/Trenholm-Lab/RetINaBox/blob/main/Software/RetINaBox/README.md)

A3: Anexo 3: Costos

Parte | Precio (CAD) | Precio (USD)
| piza 1 (130g) | 4.03 | 2.86
| piza 2 (136g) | 4.21 | 2.99
| piza 3 (80g) | 2.48 | 1.76
| piza 4 (38g) | 1.18 | 0.83
| piza 5 (48g) | 1.49 | 1.06
| piza 6 (41g) | 1.27 | 0.90
GPIO Breakout Kit para Raspberry Pi | | 18.00 | 12.78
Kit de cables de connexión | | 18.99 | 13.48
Cables Dupont | | 12.99 | 9.22
Mini tableros de circuitos | | 12.99 | 9.22
Fotodiodos | | 15.99 | 11.35
Raspberry Pi 500 | | 169.95 | 120.66
Pantalla YODOIT | | 89.99 | 63.89
Tornillos M3 | | 11.65 | 8.27
Tornillos M2 | | 18.99 | 13.48
ELEGOO kit | | 21.99 | 15.61
Pre-Crimped Cable Kit Compatible | | 20.99 | 14.90
LEDs infrarrojos | | 8.40 | 5.96
Lámina plástica | | 15.99 | 11.35
Play doh | | 3.00 | 2.13
Adaptador 3.3V USB a TTL | | 15.99 | 11.35
Total | | 470.55 | 334.096

Piezas 3D impresas
(costo estimado)

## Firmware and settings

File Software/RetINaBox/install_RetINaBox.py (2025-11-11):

#!/usr/bin/env python3
"""
RetINaBox Development Setup Installer

This script sets up a development environment for RetINaBox on Raspberry Pi.

Modes:
- Raspberry Pi 400: APT-ONLY mode (no pip, no venv). Installs all deps via apt, runs with system Python.
- Raspberry Pi 500/others: Your original flow (venv inheriting system packages + pip -r requirements.txt).

Rationale:
- Pi 400 often runs 32-bit and hits BLAS soname + pip/locale snags. APT-only mode guarantees compatibility.
"""

import os
import sys
import subprocess
import shutil
from pathlib import Path
import re
import time

# ----------------------------- Utils -----------------------------------------

def print_header(text):
    print("\n" + "="*80)
    print(text)
    print("="*80 + "\n")

def run_command(command, description=None, exit_on_error=False):
    if description:
        print(f"{description}...")
    result = subprocess.run(command, shell=True, capture_output=True, text=True)
    if result.returncode != 0:
        if description:
            print(f"ERROR during '{description}':")
        if result.stdout.strip():
            print(result.stdout.strip())
        if result.stderr.strip():
            print(result.stderr.strip())
        if exit_on_error:
            print("Installation failed. Exiting.")
            sys.exit(1)
        return False
    return True

def venv_python(venv_dir): return str(Path(venv_dir)/"bin"/"python")
def venv_pip(venv_dir):    return str(Path(venv_dir)/"bin"/"pip")

def create_venv(venv_dir, inherit=False, desc=None, upgrade_pip=True):
    """Create venv; optionally skip pip upgrade."""
    if Path(venv_dir).exists():
        shutil.rmtree(venv_dir)
    flag = "--system-site-packages" if inherit else ""
    run_command(f"python3 -m venv {flag} {venv_dir}",
                desc or f"Creating {'inheriting' if inherit else 'isolated'} virtual environment",
                exit_on_error=True)
    if upgrade_pip:
        run_command(f"{venv_pip(venv_dir)} install --upgrade pip", "Upgrading pip", exit_on_error=True)

# ------------------------- Pi model detection --------------------------------

def detect_pi_model():
    """
    Returns: 'pi400', 'pi500', or 'other'
    Based on /proc/device-tree/model; tolerant to minor wording differences.
    """
    model_text = ""
    try:
        with open("/proc/device-tree/model", "r") as f:
            model_text = f.read().strip()
    except FileNotFoundError:
        return "other"

    mt = model_text.lower()
    if "raspberry pi 400" in mt:
        return "pi400"
    if "raspberry pi 500" in mt or "raspberry pi 5" in mt:
        return "pi500"
    return "other"

def check_raspberry_pi_or_exit():
    if not sys.platform.startswith("linux"):
        print("This installer must be run on a Raspberry Pi.")
        sys.exit(1)
    try:
        with open("/proc/device-tree/model", "r") as f:
            model = f.read().strip()
        if "Raspberry Pi" not in model:
            print(f"WARNING: This doesn't appear to be a Raspberry Pi ({model}).")
            resp = input("Continue anyway? (y/n): ")
            if resp.lower() != "y":
                sys.exit(1)
        else:
            print(f"Detected: {model}")
    except FileNotFoundError:
        print("WARNING: Cannot confirm this is a Raspberry Pi.")
        resp = input("Continue anyway? (y/n): ")
        if resp.lower() != "y":
            sys.exit(1)

# ----------------------- Requirements helpers --------------------------------

def filter_requirements_skip(req_path, skip_pkgs=("numpy",)):
    """
    Read requirements.txt and return two lists:
      keep: lines to install
      skipped: lines skipped (e.g., numpy)
    """
    keep, skipped = [], []
    if not os.path.exists(req_path):
        return keep, skipped
    with open(req_path, "r") as f:
        for line in f:
            raw = line.strip()
            if not raw or raw.startswith("#"):
                continue
            base = re.split(r"[<>=!~\[]", raw, 1)[0].strip().lower()
            if base in {s.lower() for s in skip_pkgs}:
                skipped.append(raw)
            else:
                keep.append(raw)
    return keep, skipped

# --------------------------- Install stacks -----------------------------------

def install_dependencies_base():
    """Base deps common to both paths (safe)."""
    print_header("Installing Base Dependencies")
    run_command("sudo apt-get update", "Updating package lists", exit_on_error=True)
    packages = [
        "python3-pip", "python3-dev", "python3-venv"
    ]
    run_command(f"sudo apt-get install -y {' '.join(packages)}",
                "Installing base system dependencies", exit_on_error=True)

def install_pi400_system_stack():
    """
    APT-ONLY stack for Pi 400 (no pip, no venv):
    Installs the essential packages for RetINaBox compatibility.
    """
    print_header("Pi 400: Installing APT-only Python stack (no pip, no venv)")
    
    # Core packages needed for RetINaBox
    core_pkgs = [
        "python3-numpy", 
        "python3-pyqt5", 
        "python3-pyqt5.qtsvg",  # Essential for QSvgWidget
        "python3-pyqtgraph",    # Essential for graphing
        "python3-rpi.gpio",     # GPIO for Pi 1-4
        "python3-lgpio"         # GPIO for Pi 5 (newer alternative)
    ]
    
    # Optional packages for additional features
    optional_pkgs = [
        "python3-scipy", 
        "python3-matplotlib", 
        "python3-pil"
    ]
    
    # Install core packages first (with error checking)
    run_command(f"sudo apt-get install -y {' '.join(core_pkgs)}",
                "Installing core RetINaBox packages", exit_on_error=True)
    
    # Install optional packages (without stopping on errors)
    run_command(f"sudo apt-get install -y {' '.join(optional_pkgs)}",
                "Installing optional packages", exit_on_error=False)

def setup_gpio_manager_files(model):
    """Select and rename the appropriate GPIO manager file based on Pi model."""
    print_header("Configuring GPIO Manager Files")
    script_dir = os.path.dirname(os.path.abspath(__file__))
    gui_dir = os.path.join(script_dir, "GUI")
    
    # Define file paths
    lgpio_file = os.path.join(gui_dir, "gpio_manager.py")      # Pi 5 (lgpio)
    rpi_gpio_file = os.path.join(gui_dir, "gpio_manager_0.py") # Pi 1-4 (RPi.GPIO)
    active_file = os.path.join(gui_dir, "gpio_manager.py")
    backup_file = os.path.join(gui_dir, ".gpio_manager_backup.py")
    
    # Check if both files exist
    if not os.path.exists(lgpio_file):
        print(f"ERROR: {lgpio_file} not found!")
        sys.exit(1)
    if not os.path.exists(rpi_gpio_file):
        print(f"ERROR: {rpi_gpio_file} not found!")
        sys.exit(1)
    
    if model == "pi500":
        # Pi 5: use lgpio version (gpio_manager.py is already correct)
        # Backup the RPi.GPIO version
        if os.path.exists(rpi_gpio_file):
            shutil.copy2(rpi_gpio_file, backup_file)
            os.rename(rpi_gpio_file, os.path.join(gui_dir, ".gpio_manager_rpi.py"))
        print("Using lgpio GPIO manager (Pi 5 compatible)")
        print(f"RPi.GPIO version backed up as .gpio_manager_rpi.py")
        
    else:
        # Pi 1-4 or Pi 400: use RPi.GPIO version
        # First backup the current lgpio version
        if os.path.exists(lgpio_file):
            shutil.copy2(lgpio_file, os.path.join(gui_dir, ".gpio_manager_lgpio.py"))
        
        # Replace with RPi.GPIO version
        shutil.copy2(rpi_gpio_file, active_file)
        os.rename(rpi_gpio_file, backup_file)
        print("Using RPi.GPIO GPIO manager (Pi 1-4 compatible)")
        print(f"lgpio version backed up as .gpio_manager_lgpio.py")
        print(f"Original RPi.GPIO file backed up as .gpio_manager_backup.py")

def setup_application():
    """Confirm the app entrypoint exists."""
    print_header("Setting up RetINaBox Application")
    script_dir = os.path.dirname(os.path.abspath(__file__))
    main_file = os.path.join(script_dir, "GUI", "main.py")
    if not os.path.exists(main_file):
        print(f"ERROR: {main_file} not found!")
        sys.exit(1)
    print("Application setup complete - ready to run from source")

def create_desktop_shortcut(python_path, use_utf8=True):
    """Create a desktop launcher pointing at the chosen Python."""
    print_header("Creating Desktop Shortcut")
    script_dir = os.path.dirname(os.path.abspath(__file__))
    main_file = os.path.join(script_dir, "GUI", "main.py")
    logo_path = os.path.join(script_dir, "GUI", "Graphics", "Logo_noText.png")

    launcher_script = os.path.join(script_dir, "launch_retina_box.sh")
    with open(launcher_script, "w") as f:
        f.write("#!/bin/bash\n")
        f.write(f"cd \"{script_dir}\"\n")
        if use_utf8:
            # Force UTF-8 at runtime to avoid any decode issues in logs, configs, etc.
            f.write("export LANG=C.UTF-8\nexport LC_ALL=C.UTF-8\n")
        f.write(f"\"{python_path}\" \"{main_file}\"\n")
    os.chmod(launcher_script, 0o755)
    print(f"Created launcher script: {launcher_script}")

    desktop_dir = os.path.expanduser("~/Desktop")
    os.makedirs(desktop_dir, exist_ok=True)

    icons_dir = os.path.expanduser("~/.local/share/icons")
    os.makedirs(icons_dir, exist_ok=True)
    icon_path = os.path.join(icons_dir, "retina_box_logo.png")
    if os.path.exists(logo_path):
        shutil.copy2(logo_path, icon_path)

    desktop_file_path = os.path.join(desktop_dir, "RetINaBox.desktop")
    with open(desktop_file_path, "w") as f:
        f.write(f"""[Desktop Entry]
Name=RetINaBox
Exec={launcher_script}
Icon={icon_path}
Type=Application
Terminal=false
Comment=RetINaBox Application
Categories=Utility;Science;
Path={script_dir}
""")
    os.chmod(desktop_file_path, 0o755)
    print(f"Desktop shortcut created at: {desktop_file_path}")
    print("The shortcut will run RetINaBox from source")

# ------------------------------- Main -----------------------------------------

def main():
    print_header("RetINaBox Desktop App Installer")
    check_raspberry_pi_or_exit()

    script_dir = os.path.dirname(os.path.abspath(__file__))
    venv_dir = os.path.join(script_dir, "venv")
    requirements_path = os.path.join(script_dir, "requirements.txt")

    model = detect_pi_model()
    print(f"Model classification: {model}")

    # Always install base build/runtime deps
    install_dependencies_base()

    if model == "pi400":
        # APT-ONLY mode — no venv, no pip
        install_pi400_system_stack()
        setup_gpio_manager_files(model)
        setup_application()

        # Launcher uses system Python (no venv)
        system_python = shutil.which("python3") or "/usr/bin/python3"
        create_desktop_shortcut(system_python, use_utf8=True)

    else:
        # Pi 500 / other: install core system packages first, then use venv + pip
        print_header("Pi 500/Other: Installing core system packages + virtualenv")
        
        # Install the same core packages as Pi 400 to ensure consistency
        core_pkgs = [
            "python3-numpy", 
            "python3-pyqt5", 
            "python3-pyqt5.qtsvg",  # Essential for QSvgWidget
            "python3-pyqtgraph",    # Essential for graphing
            "python3-rpi.gpio",     # GPIO for Pi 1-4
            "python3-lgpio"         # GPIO for Pi 5 (newer alternative)
        ]
        run_command(f"sudo apt-get install -y {' '.join(core_pkgs)}",
                    "Installing core RetINaBox system packages", exit_on_error=True)
        
        # Create inheriting venv and pip -r
        create_venv(venv_dir, inherit=True,
                    desc="Creating virtual environment with system packages",
                    upgrade_pip=True)

        if os.path.exists(requirements_path):
            run_command(f"{venv_pip(venv_dir)} install -r '{requirements_path}'",
                        "Installing additional Python requirements", exit_on_error=True)

        setup_gpio_manager_files(model)
        setup_application()

        # Launcher uses venv's Python
        create_desktop_shortcut(venv_python(venv_dir), use_utf8=True)

    print_header("Installation Complete!")
    print("RetINaBox is ready. Use the desktop shortcut to launch.")

if __name__ == "__main__":
    try:
        main()
    except KeyboardInterrupt:
        print("\nInstallation cancelled by user")
        sys.exit(1)
    except Exception as e:
        print(f"\nError: {str(e)}")
        sys.exit(1)

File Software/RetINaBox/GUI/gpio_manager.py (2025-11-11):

from PyQt5.QtCore import QObject, QTimer, pyqtSignal, QThread, QMetaObject, Qt
import numpy as np 

# lgpio library for Raspberry Pi 5

lgpio = None
GPIO_AVAILABLE = False

def check_lgpio_availability():
    """Check and prepare lgpio system before initialization"""
    global GPIO_AVAILABLE, lgpio
    
    try:
        import lgpio as lgpio_lib
        lgpio = lgpio_lib
        # Test if we can open GPIO chip
        try:
            chip = lgpio.gpiochip_open(0)
            lgpio.gpiochip_close(chip)
            GPIO_AVAILABLE = True
            print("lgpio for GPIO control initialized successfully (Pi 5)")
            return True
        except Exception as e:
            print(f"lgpio available but cannot access GPIO: {e}")
            print("You may need to run: sudo python3 GPIO/gpio_cleanup.py")
            GPIO_AVAILABLE = False
            return False
    except ImportError:
        print("lgpio not available - using simulation mode")
        GPIO_AVAILABLE = False
        return False

# Initialize lgpio availability
check_lgpio_availability()

def setup_gpio_system(data_manager):
    """
    Setup the complete GPIO system with manager, worker, and thread
    Always creates worker for timer functionality - operates in simulation mode if GPIO unavailable
    Returns: (gpio_interface, gpio_worker, gpio_thread) or (None, None, None) if failed
    """
    # Clean up any existing GPIO state first
    if GPIO_AVAILABLE:
        try:
            # Try to clean up any existing GPIO state
            import subprocess
            result = subprocess.run(['sudo', 'pkill', '-f', 'lgpio'], capture_output=True)
            print(f"GPIO cleanup attempt: {result.returncode}")
        except Exception as e:
            print(f"GPIO cleanup warning: {e}")

    data_manager.set_gpio_mode(GPIO_AVAILABLE)
    
    try:
        # Always create GPIO interface and worker - they handle simulation mode internally
        gpio_interface = GPIOInterface(data_manager)
        
        # Create GPIO worker thread
        gpio_thread = QThread()
        gpio_worker = GPIOWorker(gpio_interface)
        
        # Move worker to thread
        gpio_worker.moveToThread(gpio_thread)
        
        # Connect signals
        # When thread starts, start the GPIO worker
        gpio_thread.started.connect(gpio_worker.start_reading)
        
        # Core data flow: GPIO worker processes data and updates buffers directly (every 25ms)
        # Processing now happens directly in GPIO worker - no separate signal needed
        
        # LED state changes: data manager --> GPIO worker (immediate)
        data_manager.activated_LEDs_updated.connect(lambda led_states: gpio_interface.write_stim_leds(led_states.flatten()))

        # RGC response updates: data manager --> GPIO worker (immediate)
        data_manager.rgc_leds_on_updated.connect(lambda rgc_leds_state: gpio_interface.write_rgc_leds(rgc_leds_state))
        
        # Cleanup connections
        gpio_worker.finished.connect(gpio_thread.quit)
        gpio_worker.finished.connect(gpio_worker.deleteLater)
        gpio_thread.finished.connect(gpio_thread.deleteLater)
        
        print("GPIO system setup successful")   
        return gpio_interface, gpio_worker, gpio_thread
        
    except Exception as e:
        print(f"Failed to initialize GPIO system: {e}")
        print("Falling back to simulation mode")
        data_manager.set_gpio_mode(False)
        return None, None, None

def cleanup_gpio_system(gpio_worker, gpio_thread, gpio_interface):
    """
    Clean up GPIO system resources - thread-safe cleanup
    """
    if gpio_worker and gpio_thread:
        print("Cleaning up GPIO resources...")
        
        if gpio_thread.isRunning():
            # Connect finished signal to quit thread
            gpio_worker.finished.connect(gpio_thread.quit)
            
            # Emit signal to stop worker from its own thread
            gpio_worker.stop_requested.emit()
            
            # Wait for thread to finish
            if not gpio_thread.wait(3000):
                print("Warning: GPIO thread did not stop gracefully")
                gpio_thread.terminate()
                gpio_thread.wait(1000)
                
    if gpio_interface:
        gpio_interface.cleanup_gpio()
    
    # Additional cleanup for lgpio
    if GPIO_AVAILABLE:
        try:
            print("Performing final GPIO cleanup...")
        except Exception as e:
            print(f"GPIO final cleanup warning: {e}")
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
